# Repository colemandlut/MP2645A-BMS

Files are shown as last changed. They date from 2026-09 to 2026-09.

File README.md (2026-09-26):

# MP2645A-BMS：8S LiFePO4 200A 主动均衡 BMS（MPS 方案）

| 项目 | 内容 |
|---|---|
| 电池 | 8S LFP，25.6V 标称（20~29.2V） |
| 电流 | 持续放电 200A / 充电 100A，硬件短路 800A |
| AFE | MPS **MP2797**（监测、库仑计、高边驱动、硬件保护、被动均衡） |
| 均衡 | MPS **MP2643** ×7（相邻两节一颗，双向 buck-boost，1.78A），光耦由 MCU 控制；v0.3 起替代 MP2645A |
| 功率 | 高边背靠背 NMOS，每方向 8 并联（80V/1.2mΩ TOLL） |

## 目录

- `docs/01-系统设计说明.md` —— 完整方案：架构、选型、功率/采样/均衡电路、保护参数、布局、验证计划
- `docs/02-BOM.csv` —— BOM（数量、立创编号、来源）
- `docs/05-成本估算.md` —— 元器件成本（`python3 tools/cost.py`，嘉立创实时价）
- `tools/bms_calc.py` —— 设计计算器（MOSFET 损耗温升、分流器、均衡时间、MP2643 手册公式）
- `tools/jlc_api.py` —— 嘉立创料号查询（库存、基础/扩展库、阶梯价）
- `firmware/` —— 与硬件无关的保护状态机 + LFP 均衡策略（C11），附主机端单元测试
- `obsidian-vault/` —— 项目知识库（Obsidian 仓库，可直接用 Obsidian 打开）

## EDA

全部使用 **KiCad 10**。云端容器安装：`sudo bash tools/setup_kicad.sh`（之后可用 `kicad-cli`、`kicad-python`）。

## 运行

```bash
python3 tools/bms_calc.py                 # 打印设计计算
python3 -m unittest discover -s tests     # 计算器测试
make -C firmware test                     # 固件逻辑测试
```

> 标注【待核】的参数来自 MPS 产品简介，画原理图前需对照正式数据手册确认。

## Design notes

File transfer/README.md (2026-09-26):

# transfer/

- `pcb-workflow-skill.tar.gz`：上个会话在云主机上改写的 pcb-workflow 技能（KiCad 版、规则 0e、models.toml）。
  **只用于会话间转移**：新会话按 `docs/00-会话交接.md` 第 3 节解压回云主机技能目录，不作为仓库技能使用。

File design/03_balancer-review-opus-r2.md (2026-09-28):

# 03_balancer 第 2 轮独立复核（Opus，复核方）

> 时间戳：2026-09-28 12:15 JST（`TZ=Asia/Tokyo date` 实查）
> 快照：`review/03-r2/`。`03_balancer.kicad_sch` 的 md5 为 `8e57b0ec…1a`，与 `hardware/03_balancer.kicad_sch` 相同。
> 纪律：本轮只读，没有改工程文件，没有运行 git，也没有读画图方报告。
> 分级口径同第 1 轮：P0 = 接错或会损坏器件；P1 = 前提不成立或可靠性风险；P2 = 改进、文档或样板实测项。

## 结论速览

- **P0 0 条，P1 0 条，P2 3 条**（新增 2 条，另有 1 条是第 1 轮的 P2 沿用汇总）。
- 第 1 轮的两条 P1 **均已关闭**。
- **按口径，03 页判定完成。**

---

## 1. 网表与 ERC（独立复核，不依赖主代理的结论）

- **连接关系**：用 r1 和 r2 两份 `netlist.xml` 按「器件.引脚 → 网络」全量比对本页 113 个器件，**连接差异为 0**。
  - r1 的 274 个编号引脚已经在第 1 轮逐一对照规格书 §3.2 核过（0 处不符），所以 r2 的连接同样正确。
- **器件变化**：只有 23 件的值、LCSC 或符号有变化，没有位号增减。
  - D301–D308、D311–D318：1N5819WS → **BAT54WS**，符号 `jlc:BAT54WSL9`，LCSC C22629，封装仍是 `jlc:SOD-323_L1.8-W1.3-LS2.5-RD`。
  - R302–R308：100k → **330k 1%**，符号 `0402WGF3303TCE`，LCSC C25778，封装 `jlc:R0402`。
  - R301 保持 100k（C25741）。
- **BOM**：`docs/02-BOM.csv` 与上面一致：第 56 行 R301（C25741），第 57 行 R302–R308（C25778，7 只），第 59 行 D（C22629，16 只）。
- **ERC**：快照 `erc.json` 中 `/开关电容主动均衡/` 为 **0 条**。根页 6 条 `isolated_pin_label` 属于 01/02 页的契约标签，与第 1 轮相同。
- **网络类**：X1–X8、VB0–VB8、BAL0–8 都属 BAL_3A，BAL_CLK 为 Default ✅。
- **页面文字**：已全部改成 BAT54WS 和 R302–R308 330k。原理图文件里搜不到「1N5819」✅。

## 2. 变更 ①：BAT54WS 的 K/A 方向与「慢开快关」

- **符号**：嵌入符号 `jlc:BAT54WSL9` 与 `jlc.kicad_sym` 一致，引脚为 **1 = K，2 = A**。Footprint 与 `LCSC Part = C22629` 两个字段也一致。
- **封装**：共用的 SOD-323 封装没有变。焊盘 1 在 (−1.17, 0)，阴极丝印条在 x = −0.45，靠焊盘 1 一侧，所以**焊盘 1 = K** ✅。
  - 手册（`datasheets/C22629.pdf`，与 `C22629_CJ_BAT54WS.pdf` 的 md5 相同）p.1 的外形图上，色环一端标「−」，即阴极 ✅。
- **逐只核对**（netlist 里 k = 1..8 全部满足）：
  - **D30k**：1(K) = DRVk，2(A) = GNk。DRV 变低时，N 管栅极经二极管快速放电，**快关**；DRV 变高时二极管反偏，栅极只经 R31k 330Ω 充电，**慢开** ✅。
  - **D31k**：1(K) = GPk，2(A) = DRVk。DRV 变高时，P 管栅极经二极管快速充电，**快关**；DRV 变低时二极管反偏，栅极只经 R32k 330Ω 放电，**慢开** ✅。
- **结电容（第 1 轮 P1-1）**：
  - 手册 p.1 规定 **CT ≤ 10pF @ VR = 1V, 1MHz**（最大值）；p.2 的 CT–VR 曲线在 0V 时也只有十几 pF。
  - 开通管的栅极被耦合上去的量 = V_cell × Cj / (Cj + Cg)。按 Cj = 10–15pF、Cg 取 AO3416 的 Ciss 660pF（QN p.2）或 AO3415A 的 750pF（QP p.3）计算，最大约 **3.65 × 15 / 675 ≈ 0.08V**，远低于 Vth,min（N 管 0.45V，P 管 0.5V）✅。**P1-1 关闭**。
- **其它额定值**（均 ✅）：
  - **正向电压**：VF 最大 0.24V @ 0.1mA、0.32V @ 1mA（p.1）。关断尾段，栅压被拉到离源极不超过约 0.3V，低于 Vth,min。
  - **峰值电流**：关断方向约 (3.65 − 0.8) / 16Ω ≈ 0.18A，持续小于 100ns，低于 IFRM 300mA 与 IFSM 600mA。平均电流约为每边沿 5nC × 75kHz ≈ 0.4mA，低于 IF 200mA。
  - **反向电压**：VR 21V，实际不超过 3.65V。
  - **反向漏电**：IR ≤ 2µA @ 25V，与 330Ω 并联，可以忽略。
  - **结温**：Tj 最高 125°C，功耗是 µW 级。

## 3. 变更 ②：R302–R308 = 330k 时的翻转顺序（第 1 轮 P1-2）

### 3.1 计算条件

- **时间常数**：
  - 第 1 级 τ1 = 100k(±1%) × 1nF(±10%) = **89–111µs**；
  - 第 k 级（k ≥ 2）τk = 330k × 1nF = **294–359µs**。
- **阈值**：VT− 在 VCC = 3.0V 时为 0.89–1.20V（LVC p.6）；3.3V 时插值上限约 1.35V，3.65V 时插值上限约 1.53V。
- **漏电**：输入漏电 IIN ≤ ±1µA（LVC p.7，全温度范围）。在 330k 上最多造成 ±0.33V 的偏移，在 100k 上为 ±0.1V。
- **前提**：固件只在所有节 ≥ 3.0V、相邻压差 ≤ 300mV 时才输出 BAL_CLK，所以时钟卡高时同样满足这一条件。
- **翻转时间**：t = τ · ln[(V_hi − V∞) / (VT− − V∞)]，其中 V∞ 为漏电造成的终值偏移。

### 3.2 结果

| 情况 | 取值 | 翻转时间 |
|---|---|---|
| 第 1 级最晚 | V_hi = 3.37 − 0.3 = 3.07V（3V3 取 +2%），VT− = 0.89V，V∞ = +0.1V，τ = 111µs | ln(2.97 / 0.79) = 1.32，约 **147µs** |
| 第 k 级最早 | V_hi = 3.0 − 0.3 = 2.7V（发送节 3.0V），接收节 3.3V 时 VT− = 1.35V，V∞ = −0.33V，τ = 294µs | ln(3.03 / 1.68) = 0.59，约 **173µs** |
| 第 k 级最早（另一角点） | 发送节 3.35V、接收节 3.65V：V_hi = 3.05V，VT− = 1.53V | 同样约 173µs |

- **第 1 级一定最先翻低**，最坏角点叠加最坏漏电时仍有 26µs 余量；不计漏电时余量为 137µs 对 203µs。
- 第 1 级翻低时，第 2 级输入还在不低于 (2.7 + 0.33) × e^(−147/294) − 0.33 ≈ 1.5V，高于 VT−。
- DRV1 的下降沿（≥ 3.0V）把 IN2 推到约 −1.5V，被钳位在 −0.3V，第 2 级立即翻低，然后逐级在 ns 级内**同步带低**第 3–8 级。混相窗口从最长约 50µs 缩短到逐级传播延迟的量级（< 0.5µs），与每个正常时钟边沿相同。

### 3.3 各种情况

- **停时钟**（停在低电平）：最后一个下降沿逐级传播，全部为低 ✅。
- **MCU 复位**（PA8 变为高阻，R52 下拉）：C321 两端节点只有 pF 级对地电容，IN1 瞬间跳到约 −0.15V，是同步的下降沿 ✅。
- **时钟卡在高电平**：按上面的计算，第 1 级先翻，然后同步带低 ✅。
- **MCU 慢掉电**：
  - PA8 随 VDD 缓慢下降，经 C321 高通后在 IN1 上表现为**额外的向下偏移**（斜率 × τ1），第 1 级只会翻得更早；
  - 第 2–8 级不受 BAL_CLK 影响；
  - 掉电复位时的阶跃同样向下 ✅。
- **上电**：各节输入经下拉为 0，全部为低 ✅。
- **正常工作的副作用**：
  - 第 2–8 级的下垂由 6.5% 降到 2.2%，高电平约 2.64V，比 VT+,max 2.08V（3.3V 时）高，余量更大。
  - 空闲时漏电偏移不超过 0.33V，低于 VT−,min 0.89V，仍被可靠地压在低电平。
  - 时钟下限仍由第 1 级（τ1 = 100µs）决定，约 20kHz，不变 ✅。
- **结论**：停时钟、MCU 复位、时钟卡高、慢掉电四种情况都收敛到全低，**持续性混相已消除**，飞电容稳态只承受一节电压（≤ 3.65V）。**P1-2 关闭**。
  - 前提：固件的 300mV 压差门限必须有效。如果接收节 3.65V 而发送节只有 3.0V（压差 650mV），再叠加 −1µA 的漏电，第 k 级最早会提前到约 143µs，与 147µs 相当。这个角点已被固件的 `BAL_MAX_DIFF_MV` 排除，见 P2-2。

## 4. 变更 ③：可读性（PDF 第 4 页目视）

- C30k 的位号已经移到电容右侧，不再与 `VBk` 标签重叠 ✅。
- Q311–Q318 的「AO3415A」「Q31k」文字已经正向显示 ✅。
- 标题栏为 Rev `v0.3-draw-r2`、Date 2026-09-28 ✅。
- 残留：C301–C308 的值文字「100nF 16V」与电容的竖向连线轻微相交（每节都有），见 P2-1。

---

## P0

无。

## P1

无。第 1 轮的 P1-1（二极管结电容）和 P1-2（时钟卡高混相）均已关闭，分别见 §2 和 §3。

## P2

1. **P2-1（新增，可读性）**：C301–C308 的值「100nF 16V」与电容的竖向连线轻微相交。建议把值文字右移，或放到位号下方。属规则 00 ③，不影响网表。
2. **P2-2（新增，文档与固件）**：§3 的翻转顺序依赖两个固件前提：「≥ 3.0V 才开均衡」「压差 ≤ 300mV」。
   - 建议在 docs/03 §4.3 和规格书里注明：「R302–R308 = 330k 的时序余量依赖 `BAL_MAX_DIFF_MV` 与 `BAL_MIN_CELL_MV`」。
   - 固件 X-5（停时钟停在低电平、IWDG）仍然未实现，同第 1 轮 P2-6。
3. **P2-3（沿用）**：第 1 轮的 P2-1 到 P2-8 全部沿用，状态不变：
   - UMW 手册 p.2 引脚表与 p.1 图矛盾，原理图正确；
   - IN1 正向地电位瞬变没有钳位；
   - 跨级传播延迟造成的重叠待样板实测；
   - C191023 的手册没有进 `datasheets/`（现在已不再使用，可以忽略）；
   - 0.16A 口径的适用范围；
   - 74LVC 瞬态电流、BAL_3A 线宽、J6 定位柱。
   - 另外，第 1 轮 P2-4 中的「P 管文字倒置」和「标题栏」两项已经修掉，只剩本轮的 P2-1。
   - 补充：死区的绝对值取决于阈值以下的栅极电容，手册里 Ciss 660pF 与 Fig 11 初段约 1.3nF 两个数不一致，所以样板仍要按规格书 §8.3 第 2、3 条实测。若测得重叠，可以按规格书的预案把 330Ω 改为 470Ω（C25117），不影响封装。

## 覆盖清单

| 项 | 结果 |
|---|---|
| 连接与 r1 全量比对 | ✅ 0 差异（程序比对） |
| 23 件的值、LCSC、符号、封装 | ✅ 与 BOM 第 56、57、59 行一致 |
| 嵌入符号对库 | ✅ BAT54WSL9 为 1 = K、2 = A；0402WGF3303TCE 一致 |
| D 的封装极性 | ✅ 焊盘 1 靠阴极丝印条，手册色环为阴极 |
| 16 只 D 的方向与慢开快关 | ✅（§2） |
| 结电容 | ✅ ≤ 10pF，栅极耦合量 ≤ 0.08V |
| 停时钟、复位、卡高、慢掉电、上电 | ✅（§3，含容差、阈值和漏电的最坏角点） |
| 飞电容最大电压 | ✅ 稳态只承受一节，持续性混相已消除 |
| ERC、网络类 | ✅ 本页 0 条；X、VB、BAL 属 BAL_3A |
| 可读性 | ✅ 三项已改；残留见 P2-1 |
| 第 1 轮 P2 | 沿用（P2-3） |

### 交主代理 / 知识库（复核方没有写入）

- 「交流耦合链的同步回零：让第 1 级的 τ（100k）明显小于其余各级（330k），留出余量要算上 VT− 离散、±10% 电容容差和 ±1µA 漏电的最坏角点，并依赖固件的压差门限」。

---

## qwen P1-A 裁决（2026-09-28 12:50 JST，Opus 独立复核，只读）

**裁决：不构成 P1，降为 P2（样板实测项），维持现有电路，不建议串电阻。** 同时，qwen 的 P2-9「TI SN74LVC1G17 是反相器」**不成立**。

### 1. 快关路径的实际电流（按拓扑逐段核）

**上升沿（关 P 管）**：U30k.4 → D31k（A→K）→ GPk → Q31k 栅极。

- 回路电阻 = 输出内阻 ro + 二极管动态电阻（约 5Ω）。
  - ro 取 16–29Ω：由 LVC p.6–7 推算，VCC 3.0V 时 VOH 2.3V @ −24mA、VOL 0.55V @ 24mA。
- 驱动电压 = V_cell − Vf。BAT54WS 在 0.1A 时 Vf ≈ 0.7–0.8V（C22629 p.1：VF5 ≤ 1.0V @ 100mA）。
- 负载是 P 管栅极，约 0.75nF（Ciss，QP p.3）到约 1.8nF（按 Qg/V 计入米勒）。

**下降沿（关 N 管）**：经 D30k（A = GN → K = DRV）灌电流。对称计算，N 管栅极约 0.66–1.35nF，所以电流更小。

慢开支路（330Ω）在边沿时只额外叠加约 V_cell / 330Ω ≈ 10mA。

| ro | V_cell 3.0V | V_cell 3.65V |
|---|---|---|
| 16Ω | 110mA | 136mA |
| 24Ω | 79mA | 98mA |
| 29Ω | 68mA | 84mA |

- **峰值约 70–140mA**。qwen 的 85mA 在这个范围内，数量级正确。
- **持续时间**：τ = (ro + rd) × Cg ≈ 21–34Ω × 0.75–1.8nF ≈ 16–60ns。电流高于 50mA 的时间 ≈ τ·ln(Ipk / 50mA)，约 **15–60ns**。
- **每个边沿的电荷**：约 V_cell × Cg ≈ 3–6nC。
- **平均电流**：2 × 3.3V × 1.8nF × 75kHz ≈ **0.9mA**。
- **RMS 电流**：约 110mA × √(150k/s × 35ns / 2) ≈ **5.6mA**。
- **输出级耗散**：≈ ½CV² × 2f ≈ **1.5mW**，SOT-23-5 的温升 < 1°C（θJA 300°C/W，LVC p.4）。

### 2. ±50mA 是直流还是含瞬态

- UMW 手册 p.4 原文是「**DC** Output Sink Current IO ±50mA」，同表还有「**DC** Output Diode Current IOK ±50mA」和「**DC** Supply Current per Supply Pin ICC ±100mA」。三者都是**直流 / 连续**额定，手册没有给容性负载的瞬态峰值。
  - TI 原版的对应条目是「Continuous output current」，语义相同。
- 手册自己的 AC 测试条件就会产生超过 50mA 的瞬态：tpd 在 **CL = 50pF** 下测（p.8），74LVC 边沿约 1–2ns，i = C·dV/dt ≈ 50pF × 3.3V / 1.5ns ≈ **110mA**。可见数十到上百 mA、ns 级的容性充放电峰值，是这类输出的**正常工作状态**，并不违反直流 abs max。
- 与可靠性相关的量是平均电流和 RMS 电流（电迁移）以及结温。本设计分别约 0.9mA 和 5.6mA，温升 < 1°C，**都远低于 ±50mA 和 ±100mA**。
- 另外，qwen 引用的「24mA@3.0V」是 VOH/VOL 的**直流规格测试点**，不是电流上限。

**结论**：「长期超 abs max」的判断把直流额定套用到了 ns 级的容性瞬态上，前提不成立。**不构成 P1**。这条已被本报告第 1 轮 P2-8 覆盖（样板时看 DRVk 波形与 U30k 温升），维持 **P2**。

### 3. 「DRVk 串 10–33Ω」的后果（不建议）

- **串 10Ω**：峰值只降到约 55–100mA，仍高于 50mA，达不到目的。
- **要把峰值压到 50mA 以下**，需要串约 **47Ω**：(3.65 − 0.5) / (16 + 47 + 5) ≈ 46mA。这样快关的 τ 从约 16–60ns 增大到约 50–120ns，P 管关断时间（约 2.7τ）从约 110–165ns 增加到约 **135–330ns**。
- 慢开一侧只由 330Ω 加 47Ω 决定，基本不变：N 管在约 40–80ns 就越过 Vth,min。
- 净效果是**死区被吃掉，重新出现两管同时导通**，正好抵消 U-1 的目的，比现状更差。
- 如果将来实测证明确实要限流，必须**同步放大慢开电阻**，保持「慢开时间常数远大于快关时间常数」，例如串 47Ω 并把 R31k/R32k 由 330Ω 改为约 1k。代价是完全导通更慢（约 5µs，占半周期 6.67µs 的大部分），R_FSL 会明显变差，需要重新核算均衡电流。**不推荐**，只作为样板实测不理想时的备选。

### 4. qwen P2-9「TI SN74LVC1G17 是反相器」

- **不成立。** UMW 手册 p.1 Description 写的是「Single **Non-inverting** Schmitt Trigger Buffer」，p.1 Figure 1 的符号是不带反相圈的缓冲器，p.3 功能表为 A = L → Y = L、A = H → Y = H。
- TI 的命名规则也是 SN74LVC1G17 = 单路施密特**缓冲器**（非反相），SN74LVC1G14 才是施密特**反相器**。
- 本设计的「8 级同相、相位 1 全高、相位 2 全低」正是依赖非反相（规格书 §1.2 引 LVC p.3 函数表），原理图与 BOM 用的都是 1G17（C7394021），**正确**。

### 本节对总计数的影响

不变：**P0 0 / P1 0 / P2 3**。qwen P1-A 并入第 1 轮 P2-8（沿用，样板看 DRVk 波形与 U30k 温升）；qwen P2-9 驳回。**03 页判定完成的结论不变。**

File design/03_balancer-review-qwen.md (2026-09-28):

# 子图 03_balancer 独立复核（review2 / qwen3.8-27b）

- 快照：`review/03-r1/`（03_balancer.kicad_sch md5 `9caa8c53fcb304c45472574c5d2f5c59`）——**本报告的复核对象**
- 工作树说明：截至本复核（2026-09-28 12:3x JST）工作树已按规格书 §8.1c 用户决定进入 r2 状态（md5 `8e57b0ecc86f58e3d9b49bf7c53b8c1a`，冻结于 `review/03-r2/`）→ 骨架第 3 行「与工作树逐字节一致」已失效；本报告对 r1 快照下结论，并对 r2 换料做独立验收（§8）
- 复核方：阿里云 qwen3.8-27b；画图方 DeepSeek、第一复核 Opus，三方不同厂商
- 独立性声明：未读画图方报告（`03_balancer-draw-report.md`、`*-draw-*.out`）、未读第一复核报告、未读生成/自检脚本注释；全部结论从快照 + 规格书 + docs + BOM + 手册 + 05 页源独立重推
- 输入：`review/03-r1/`（sch / erc.json / netlist.xml / sch.pdf 第 4 页）、`design/03_balancer-spec.md`（含 §8.1b/§8.1c 用户决定）、`design/03_balancer-task-draw-r2.md`（任务书，允许输入）、`docs/03-详细设计.md` §1/2.4/4、`docs/02-BOM.csv` 均衡段、`datasheets/`（C479060、C5350990、C7394021、C191023、C22629、C15008、C163126、C18202166）、`hardware/05_mcu_comm.kicad_sch`（BAL_CLK 源）、`hardware/mp2645a-bms.kicad_pro`（网络类）、`hardware/lib/jlc/jlc.kicad_sym`、`tools/bms_calc.py`（sc_equalizer）、`tools/jlc_api.py`（抽核）

## 结论汇总

**P0 = 0；P1 = 3（P1-B、P1-C 为 r1 缺陷，r2 已修复且本复核独立核实修复成立；P1-A 仍未覆盖、保持开放）；P2 = 10（含 2 条纯备注）。**

| # | 级别 | 位号 | 摘要 | 状态 |
|---|---|---|---|---|
| P1-A | P1 | U301–U308（脚 4/DRVk） | 栅驱峰流 ≈(Vcell−Vf)/ro ≈ 80–110mA（ro≈24Ω 为 TI 同族估计，UMW 手册未列 ro），每边沿 ~13–18ns × 75kHz×2 边沿 ×8 级，超 UMW 手册 p4 绝对最大 **IO ±50mA**；功能不受影响（二极管钳位端点电压与 ro 无关）但长期 24/7 超出绝对最大额定 = 可靠性风险 → 样机实测/UMW 书面确认；备选：DRVk 串 10–33Ω | **开放**（r2 未覆盖） |
| P1-B | P1 | D301–308/D311–318（r1 = 1N5819WS C191023） | Cj 110pF@4V 与栅电容电容分压：DRV 边沿馈通 ΔV·Cj/(Cj+Ciss) ≈ +0.47V（N 栅）/ −0.42V（P 栅）→ 边沿提前 ~10–30ns。独立重推（缓冲器模型，见 §3.2）：P 栅馈通后 Vgs_P ≈ −1.4V，仍比 \|Vth\|max 0.9V 低 ≥0.5V → **不构成持续直通**；后果比初报定级轻（边沿毛刺，非死区失效）。r2 换 BAT54WS（CT≤10pF）将馈通降一个量级 → 有效改进 | r1 缺陷；**r2 已修，独立核实**（§8） |
| P1-C | P1 | R301–R308（r1 全 100k） | 停时钟/掉电时各级 IN 独立 RC 衰减，翻转时刻 t_k≈100µs·ln(Vcell_k/VT−_k)：ΔV≲100mV 的剖面下相邻级**可能逆序翻转**（靠 VT− 器件离散与电压差同量级竞争），窗口典型 ~1–3µs、最坏角 ~30µs；窗口内 (k=N 通, k+1=P 通) → CF(k−1) 跨两节 6.6–7.3V，板内 τ_CF≈(Rds_N+Rds_P+ESR)×200µF≈18–30µs → 最坏角 CF 峰值 ~6.0–6.5V（**边际超 6.3V 额定**，每掉电一次）；典型角 ~0.4–1.1V 不超。规格书 §4.3 只写「约 30µs 混相」未量化超压。注：本复核按 C33k∥C34k=200µF 口径，比早期「τ=9µs、超压 0.1–1.0V」的估计更保守（超压幅度更小、但最坏角仍触额定）。r2：R301 保持 100k、R302–308→330k，首级翻转 t1≈100µs·ln(V1/VT−1)≈101–131µs（规格「≤133µs」✓）恒早于其余级（≥330µs·ln(V/VT−)≈415–455µs）→ DRV1 下降沿经 C322 把 IN2 拉低 ~0.9975·Vcell（t1 时刻 IN2 自由衰减值仅 ~0.72–0.74·Vcell）→ 钳位至 VB1 输入二极管 → 级联 ~5ns/级带低 2–8 级 → 逆序窗口消除，残留 = MOS 转换 ~0.3µs → CF 过压 ≈7.3V×(0.3/18)µs ≈ **24mV** | r1 缺陷；**r2 已修，机制独立重推成立**（§8） |
| P2-1 | P2 | D30k/R31k/D31k/R32k（全部 8 级） | DRV 下降沿：N 快关（D30k 放栅，~40ns 过 Vth）与 P 慢开（R32k，~70ns 至「基本导通」、~400ns 全导通）重叠 ~30–350ns；Thevenin 峰值 Vcell/(Rds_N+Rds_P) ~10–20A，被电芯 ESR（~10–30mΩ）+线束 0.7µH 限制到实际数 A；每边沿能量 ~0.3–1µJ ×75k/s → **~10–80mW/级**（θJA 89°C/W → 每级几 °C–10°C）；AO3416 绝对最大 6A 在边界 → SPICE/样机实测灌流峰 | 待样机 |
| P2-2 | P2 | D30k + Q30k（GNk） | N 快关地板 GN=VOL+Vf：r1 1N5819WS ≈0.75–0.9V（r2 BAT54WS ≈0.54–0.8V）vs N Vth 0.45–1.0V：最坏角（Vth max）关断裕量 0.1–0.25V ✓，典型角（Vth 0.7）仅 ~50mV → 亚阈 µA 级漏 | 备注（典型角贴边） |
| P2-3 | P2 | D31k + Q31k（GPk） | DRV 高电平期间 P 栅端点 GP=DRV_high−Vf → Vgs_P≈−(0.7+Vf)≈−0.94…−1.15V vs \|Vth\| max 0.9V：r2 BAT54WS 低 Vf 角（0.24V）Vgs_P≈−0.94V → 部分 P（\|Vth\|≤0.94）在 N 导通半周处于导通边界（亚阈 µA–mA，非破坏）→ 仿真确认 | 待仿真 |
| P2-4 | P2 | C301（r1 PDF 第 4 页） | 可读性：C301 位号/字段压「VB1」全局标签；Q311–318 字段角度倒置（fa≠0）。r2 已修（r2 渲染确认分离/正立） | r1 缺陷；r2 已修 ✓ |
| P2-5 | P2 | 固件（X-5 TODO，尚无代码） | 规格书门控（ΔV>300mV 禁均衡 / <3.0V 禁 / 顶部区策略 / 静置 30min）尚未落地。无门控时：级 k 的 IN 高电平 = 前级 DRV 耦合 ≈Vcell(k−1)·0.9975，须 > VT+(VCC=Vcell_k) 才能翻转：最恶劣相邻剖面（下 2.5V/上 3.65V）高电平裕量 = 2.5·0.9975 − VT+(3.65≈2.4) ≈ 0.1V → 该级停摆（CF=0↔1 节，**非破坏**，均衡能力降级）→ 核固件落地 | 待固件 |
| P2-6 | P2（备注） | D30x/D31x 符号 | BAT54WSL9 为单二极管符号：已核实为单 die（CJST 手册 p1），JLC API 文案「Independent…Diodes」系分类套话；K=pin1（fp_poly 封装色环在 pin1 侧）✓ | 已核实，备注 |
| P2-7 | P2（文档更正） | — | 「栅负载约 3.2nF」（知识库 + 详细设计 §4.3）= Qg/V 假象（(8+9.5)nC/3.2V≈3.3nF），实际 Ciss 合计 660+750=**1.41nF**（另加二极管 Cj）→ 已写回知识库更正（死区决策本身不受影响，仍成立） | 已更正 |
| P2-8 | P2（未核） | F300–F308（CFS12V3T3R0 C163126） | 手册已读页无 I²t 表 → 规格书「40–73A 约 1ms 熔断」为工程估计 → **未核**；额定 3.00A/DC32V/分断 50A@32V/−20…+105°C 已核 | 未核 |
| P2-9 | P2（重要备注） | U301–U308（C7394021） | **器件身份**：UMW/UTD「SN74LVC1G17DBVR」是**非反相施密特缓冲器**（手册 p1 标题 "Non-inverting Schmitt Trigger Buffer"、p3 功能表 INA L→OUTY L / H→H、p1 引脚图），借用 TI 反相器 1G17 料号；TI 原装 1G17 为反相器且引脚不同（TI：1=GND/2=CEXT/3=A/4=Y/5=VCC，UMW：1=NC/2=INA/3=GND/4=OUTY/5=VCC）。本设计拓扑**依赖缓冲功能**（各级同相；若为反相器则各级交替 N/P，CF1/3/5/7 常态跨两节 6.6–7.3V）→ BOM/规格书/符号应加注「**勿代换为 TI 原装 1G17 反相器**」。所购 C7394021 = 缓冲器 = 设计正确 | 已核实，需加注 |
| P2-10 | P2（备注） | U30x / J6 | 规格源不一致：UMW 手册 p1 Features「Source/Sink 24mA@3.0V」vs JLC API/BOM「32mA」（P1-A 以 abs max ±50mA 为准，不受影响）；J6 连欣手册 6A/针 vs JLC API/BOM 5A/针（均被 F30k 3A 覆盖） | 备注 |

次要（不计 P2）：详细设计 §4.3 栅驱损耗 2.6mW/节 vs 按 Qg·f 推算 ~4.3mW（估算偏差，不影响结论）；2.5V 电芯角 Vgs_N≈2.25V 略低于 2.5V 测试条件，Rds(on) 略劣于 26mΩ 标称（~35–40mΩ 量级），I²R≈1mW 无碍。

## 0 前置检查（断线/死头/悬空、同网多名、GND/CELL）

- **断线/死头/悬空**：ERC（快照冻结 `erc.json`，Kicad 10.0.6，2026-09-28T02:32）sheet `/开关电容主动均衡/` violations = **0**；全工程 6 条 warning 均为根图页 `/` 的 `isolated_pin_label`（DSG_G/CHG_G/SRP/SRN/FET_MID/PACK+），与本页无关。网表逐脚复核：无一脚挂两网；未连接脚仅 **U30x.1**（NC，UMW 手册 p1 引脚图确认 NC）与 **J6.10**（有意空放 NC，规格书 §7 接口定义），均有文档依据，无意外悬空。
- **同网多名**：网表每网唯一名；本页 60 网无两名共指同一物理连接（逐脚比对无「两个不同全局标签落在同一对引脚」）→ 0 条。
- **本页无 GND / 无 CELL\***：网表确认本页 60 网全部为 `/开关电容主动均衡/…`（50 个：IN1–8、DRV1–8、GN1–8、GP1–8、X1–8、VB0–8、CLK_R）+ 全局 BAL0–8（9）+ BAL_CLK（1）；无 GND/0/CELL*。工程网表中的 GND、CELL0–8、NTC_CELL1/2 均在 01/02/05 页。符合规格书 §8.1b 用户决定（VB0 不接地、首级交流耦合、本页无 GND/电源符号）。
- **U30x 浮动供电合法性**：U30k VCC=VBk、VSS=VB(k−1)，供电 = 一节 2.5–3.65V ∈ UMW 手册 p5 推荐工作条件 1.65–5.5V ✓；C30k 100nF/16V（C1525）跨 VCC–VSS 去耦 ✓ 8/8。

## 1 逐节推导（k=1..8）

**拓扑（从 r1 网表独立重推，8 级逐字段核完，全部一致）：**

- **U30k**（C7394021 UMW 非反相施密特缓冲器，身份见 P2-9）：pin2 INA = INk（= R30k→VB(k−1) ∥ C32k）；pin3 VSS = VB(k−1)；pin5 VCC = VBk；pin4 OUTY = DRVk；pin1 = NC 悬空。
- **k=1 特例**：C321.1 = CLK_R（← R300 1k ← BAL_CLK；BAL_CLK 另两节点 = 05 页 R52.1、U6.29，即 MCU 侧 + 100k 下拉，规格书 §8.1b「IN 只接 100k 下拉」在 05 页实现）；**k≥2**：C32k.1 = DRV(k−1)。C32k.2 = INk。
- **Q30k N（AO3416 C479060）**：G=GNk、S=VB(k−1)、D=Xk；**Q31k P（AO3415A C5350990）**：G=GPk、S=VBk、D=Xk（N、P 漏极共 Xk，Xk 节点 = {C33k.1, C34k.1, Q30k.3, Q31k.3} ✓）。
- **死区网络（引脚级核完 8/8）**：D30k（r1：1N5819WS C191023）**pin1(K)=DRVk、pin2(A)=GNk**，∥ R31k 330Ω（DRVk↔GNk）→ **N 慢开**（R31k 充栅 τ≈330×(660+Cj)pF）、**N 快关**（D30k 放栅 GN=VOL+Vf）；D31k **pin1(K)=GPk、pin2(A)=DRVk**，∥ R32k 330Ω（GPk↔DRVk）→ **P 慢开**（R32k）、**P 快关**（D31k 钳 GP=DRV−Vf 跟上升沿）。二极管方向与页面注记「慢开快关」一致 ✓。
- **飞电容**：CFk = C33k∥C34k = 2×100µF/6.3V（C15008，1206），Xk↔X(k+1)，7 级 7/7 ✓。
- **储能/去耦**：C31k 100µF/6.3V（C15008）VB(k−1)↔VBk（本地储能，规格书 §8.1b：线束 0.7µH 与 100nF 谐振 ±1V → 必须 100µF）8/8 ✓；C30k 100nF/16V（C1525，0402）VB(k−1)↔VBk（栅驱去耦）8/8 ✓。
- **R30k**：INk↔VB(k−1)，r1 全 100k（C25741），R301.2=VB0 … R308.2=VB7 ✓。

**功能推导（缓冲器模型）：** INk 高 → DRVk 高 → N 通、P 关 → Xk=VB(k−1)；INk 低 → DRVk 低 → N 关、P 通 → Xk=VBk。CLK 高半周：1nF 耦合链使各级 IN 同相为高（tpd max 4.5ns@3.3V，UMW 手册 p7）→ **全级 N 通，CFk=Vcell_k**；CLK 低半周：全级 P 通，**CFk=Vcell_{k+1}**。电荷转移方向：Vcell_k>Vcell_{k+1} 时 CFk 在 N 相充至 Vcell_k、P 相跨在 k+1 节上放电 → 净 k→k+1 ✓（经典全同相开关电容均衡，拓扑正确）。

## 2 时钟链与停时钟/复位/上电/卡高状态、飞电容耐压

- **正常**：75kHz（半周期 3.35µs ≫ 慢开 0.22–0.28µs + tpd），全级同相（缓冲器级联，无反相）✓；均衡电流口径见 §6。
- **停时钟 / MCU 复位 / 时钟卡任意电平（DC 终态）**：R30k 把所有 INk 拉向 VB(k−1)（低），C32k 隔直 → 所有 DRVk 低 → **全 N 关**（地板 GN=VOL+Vf≈0.75–0.9V < Vth max 1.0V，最坏角关断）、**全 P 通**（Vgs≈0.3−3.3=−3.0V）→ **CFk=Vcell_{k+1} ≤ 3.65V ✓**。规格书 §8.1b「停时钟/复位都收敛到全低」的「全低」= 全 IN/DRV 信号低（即全 P 通态），与规格书口径一致。
- **收敛时间**：首级 IN1 经 R301∥(R300+R52) 衰减，τ≈100µs，翻转 t1=τ·ln(Vcell1/VT−)≈101–131µs（VT− 按 VCC=Vcell 内插）。**r1**：其余级 R30k 亦 100k → t_k 同量级 → 见 P1-C（混相）。**r2**：R302–308=330k → 其余级独立翻转 ≥415µs，全部由首级级联在 ~40ns 内带翻 → 见 §8。
- **上电**：初始充电经 F30k（3A）与导通 MOSFET，CFk 初值受相邻两节电压约束（≤单节等效）；C31k 初值分配 ≤4.4V/只（规格书 §5 上电分析，本复核核过充电通路存在、无 2 节直并路径）→ 6.3V 额定裕量 ≥1.9V ✓。
- **飞电容耐压（稳态 + 停钟态）**：CFk ≤ max(Vcell_k, Vcell_{k+1}) ≤ 3.65V（并联每只 3.65V = 额定 58%）✓。**唯一 CF>1 节的状态 = P1-C 的 r1 混相瞬态**（最坏角 ~6.0–6.5V，r2 已消）。

## 3 器件级核算（Vgs / Rds(on) / 耐压 / 死区直通）

### 3.1 各 MOSFET 的 Vgs（2.5–3.65V 驱动）

| 状态 | 栅压 | 角核算 | Rds(on) |
|---|---|---|---|
| N 通（DRV 高） | Vgs_N ≈ (Vcell−VOH)+Vf−… = GN−VB(k−1) ≈ Vcell−0.25（@3.3V 角 ≈3.05V；2.5V 角 ≈2.25V） | ≥ Vth max 1.0V 裕量 ≥1.25V ✓；2.5V 角低于 2.5V 测试条件 → Rds 略劣（~35–40mΩ 量级） | 26mΩ max @2.5V（AO3416 手册）；I²R@0.16A ≈ 0.7mW ✓ |
| N 关（DRV 低，地板） | Vgs_N = VOL+Vf ≈ 0.75–0.9V（r1）/ 0.54–0.8V（r2） | 最坏角 < Vth max 1.0V ✓（裕量 0.1–0.25V）；典型角（Vth 0.7）贴边 ~50mV → 亚阈 µA（P2-2） | 关态漏 µA 级 ✓ |
| P 通（DRV 低） | Vgs_P ≈ VOL−Vcell ≈ −3.0V（@3.3V）/ −2.2V（@2.5V，VOL max 0.55V 角） | < Vth min −0.5V 裕量 ≥1.4V ✓ | 47mΩ max @−2.5V（AO3415A 手册）；I²R ≈ 1.2mW ✓ |
| P 关（DRV 高，端点） | Vgs_P = (DRV_high−Vf)−Vcell ≈ −(0.7+Vf) ≈ −0.94…−1.15V | vs \|Vth\| max 0.9V：r1 角（Vf 0.45–0.6）裕量 0.35–0.55V ✓；r2 BAT54WS 低 Vf 角（0.24V）≈−0.94V → 贴导通边界（P2-3，µA–mA 亚阈） | — |

- 耐压：AO3416 ±20V、AO3415A −20V vs 单节 ≤3.65V + 混相瞬态 ≤7.3V（r1 P1-C 最坏角）✓ 裕量 ≥2.7V；二极管 VRM 30V（BAT54WS）/40V（1N5819WS）✓；C15008 6.3V 为唯一贴额定语件（P1-C 焦点）。
- 热：每级 8 件总损耗 = 导通 I²R（~2mW）+ 栅驱（Qg·V·f ≈ (8+9.5)nC×3.3V×75k ≈ 4.3mW，文档 2.6mW 偏低，次要）+ 重叠（P2-1，10–80mW）→ θJA 89.3/65–90°C/W → 结温升 <15°C，无热风险（P2-1 待仿真收紧）。

### 3.2 死区 / 直通（r1 1N5819WS，Cj 110pF@4V/1MHz）

- 时序（缓冲器模型 + 网表二极管方向，§1）：
  - **N 慢开**：R31k 330Ω 充 660pF(+Cj)：τ≈0.22–0.25µs，自地板 0.75V 充至 ~Vcell−0.25；**N 快关**：D30k 经 U30x 输出 ro（≈24Ω，TI 同族估计）放栅：τ≈ro×(660+110)pF≈18ns，过 Vth max（1.0V）~40ns。
  - **P 慢开**：R32k 放 750pF(+Cj)：τ≈0.28µs；**P 快关**：D31k 钳 GP=DRV−Vf 跟上升沿（~5ns 级）。
  - **重叠（DRV 下降沿）**：N ~40ns 关断、P ~70ns 起「基本导通」（~400ns 全导通）→ 重叠 ~30–350ns，Thevenin 峰值 ~10–20A，实际被电芯 ESR + 线束 0.7µH 限流 → 每边沿 ~0.3–1µJ ×75k/s → **10–80mW/级**（P2-1，样机/SPICE）。上升沿无重叠（N 慢开时 P 已快关）。
- **电容分压（P1-B 重推）**：Cj 与栅电容并联分压，DRV 边沿馈通 ΔV·Cj/(Cj+Ciss)：N 栅 +0.47V@3.3V（发生于 N 慢开启动点，此时 P 已关 → 短暂 10–30mA 提前导通，µW 级，无碍）；P 栅 −0.42V（DRV 下降沿）→ Vgs_P≈−1.4V，仍低于 \|Vth\|max 0.9V 达 0.5V → P 不提前通。**结论：r1 的 Cj 问题是「边沿提前 ~10–30ns」，非持续直通；r2 换 BAT54WS（CT≤10pF → 馈通 0.03–0.05V）有效，独立核实见 §8。**

### 3.3 U30x 输出峰流（P1-A，开放）

- 路径：DRVk 边沿 → 死区二极管（ro_d≈0.2–0.3Ω@100mA）→ 栅。上升沿：P 栅（750pF/Qg 9.5nC）经 D31k 充电：I_peak ≈ (DRV_high−GP_start−Vf)/ro_out ≈ (Vcell−0.7−0.45)/24 ≈ **85mA**（3.3V 角）；下降沿：N 栅经 D30k 放电：≈(2.75−0.75)/24 ≈ **83mA**；持续 ~13–18ns（tpd ~5ns + ro×C 16–18ns），**每个边沿**（75kHz×2）×8 级。
- 对照 UMW 手册：**绝对最大 IO = ±50mA（p4 Absolute Maximum Ratings）**；Features 保证 24mA@3.0V（p1）。峰流超 abs max ~70–110%：端点电压由二极管钳位、与 ro 无关 → **功能正确，但长期超出绝对最大额定 = 可靠性降级风险**（该器件 75kHz 永久工作，非偶发脉冲）。
- 处置建议：(a) 样机实测 U30x 输出电流峰（栅极电流探头/示波器）；(b) UMW/UTD 书面确认脉冲能力；(c) 若实测 >50mA：DRVk 串 10–33Ω（峰流降至 <50mA，重核慢开 τ 仍 ≪3.35µs ✓，D30k/D31k 钳位端点不变）。

## 4 J6 针位与保险丝

- **J6**（C18202166，连欣 XDWF-C3030WV-2X05P，Micro-Fit 3.0 兼容，2×5）：网表逐脚核完 **pad n ↔ BAL(n−1)（n=1..9），pad 10 = unconnected NC** ✓（规格书 §7「焊盘 10 空放」）。封装 `CONN-TH_XDWF-C3030WV-2-5P` 焊盘坐标（前会话已读封装文件）：之字形 2×5，pad 1,3,5,7,9 @y=−1.50、2,4,6,8,10 @y=+1.50，x=−6..+6 步进 3.0mm，pad 1 矩形为 pin-1 标记；连欣手册图面无针号 → BOM「按物理位置对针」合理 ✓。
- **电流**：连欣手册 6A/针 vs JLC API/BOM 5A/针（P2-10 备注）；均衡工况最坏针流 = 相邻两级叠加 ≤ 2×0.16 = 0.32A ≪ 3A 保险丝 ≪ 5–6A 端子 ✓。
- **F300–F308**（CFS12V3T3R0，C163126，TA-I 1206，3.00A）：网表 9/9 **脚 1 = BALk（线束侧）、脚 2 = VBk（板侧）** ✓；额定 DC32V、分断 50A@32V、−20…+105°C、100% 额定体温升 <75°C（手册已读页）；0.32A = 额定 10.7%，温升可忽略 ✓。保护对象 = 线束；**板上保险丝保护不了电芯端线束 → 线束端保险丝暂不加 = 已知风险 U-6（用户 2026-09-27 接受）**。I²t「40–73A 约 1ms」= 工程估计（手册已读页无 I²t 表）→ **未核**（P2-8）。

## 5 网络类（BAL_3A）

- 网表核完：`/开关电容主动均衡/` 的 **X1–8、VB0–8（17 个）+ 全局 BAL0–8（9 个）= 26/26 全部 class=BAL_3A** ✓（.kicad_pro BAL_3A：3A、线/迹 1.2mm）。
- IN/DRV/GN/GP/CLK_R/BAL_CLK = Default（控制信号网，脉冲均值 <1mA）✓，未被卷入 BAL_3A 也无 CELL_SENSE 误卷。
- **图纸名陷阱复核**：网表本地网名含图纸名路径 `/开关电容主动均衡/…`（非文件名 `03_balancer`）→ pattern 必须用图纸名（知识库既有教训，与 vault 记录一致）；改图纸名会静默退 3A 线宽。

## 6 均衡电流口径（bms_calc sc_equalizer）

- `tools/bms_calc.py sc_equalizer`：**0.159A@100mV** ↔ 规格书 §4.1 I=ΔV/0.628Ω → 0.16A ✓ 一致；60°C 0.14A、最坏 0.12A ✓。
- 模型假设（**未核，样机实测 X-1**）：线束/导线电阻 45mΩ 名义值、R_FSL 系数 4（MP2797 均衡路径安全系数）、C15008 直流偏置降额未建模、6·R_w 线阻模型。
- 级联叠加：bms_calc 为单级口径；8 级级联时线束针流 = 相邻两级之和（§4），0.32A 对 3A 保险丝/5–6A 端子裕量充足 ✓。

## 7 ① 电容完备性 / ② 封装下探 / ③ 可读性 / LCSC 与 BOM

**① 电容完备性**：U30k 去耦 C30k 8/8（16V 额定 vs 单节 3.65V = 4.4× 裕量 ✓）；CFk 双并联 7/7（一只失效 → 100µF 冗余，电流减半，非破坏）；C31k 本地储能 8/8（§8.1b 决定）；C32k 1nF/50V 耦合 8/8（50V ≫ 7.3V 瞬态 ✓）；栅极无旁路电容 = 直驱 + 330Ω，与规格书一致 ✓。**无缺漏。**

**② 封装下探**：AO3416/AO3415A SOT-23-3（Qg 8/9.5nC、θJA 89.3/65–90°C/W）：0.16A 下 I²R≈1.9mW/级，无热风险 ✓；BAT54WS SOD-323（r2）：IR 2µA@25V、PD 200mW、VRM 30V —— 钳位电流仅为栅边沿脉冲（均值 <1mA）✓；1N5819WS SOD-323（r1）同封装，Cj 110pF 见 P1-B；C15008 1206 100µF/6.3V：纹波损耗未核（手册已读页无 ESR 表，次要）；CFS12V3T3R0 1206：0.32A 温升可忽略 ✓；J6 3.0mm 孔阵 φ1.02 与连欣手册 3.00×3.00mm 布局一致，Micro-Fit 3.0 0.110" 线束针兼容 ✓。

**③ 可读性（sch.pdf 第 4 页，r1 渲染）**：缺陷 = C301 位号/字段压「VB1」标签 + Q311–318 字段倒置（P2-4，r2 已修，r2 渲染确认）；右栏整体上移 26.67mm 合理；F300–F308 与 VBk 不同高（两栏行距差，9 只排不齐）——画图方已自记为电气等价偏差，不影响判读（备注）；标题栏 v0.3-skeleton（r1）/ v0.3-draw-r2（r2）+ 6 行说明完整 ✓。

**LCSC 与 BOM 一致性**：r1 快照 113 件逐行比 BOM（均衡段行 49–61 + J6 行 100）：符号 Value/MPN/LCSC 全部一致 ✓（8 级同构 + 7 飞电容 + J6 + 9 保险丝 + R300 + 16 死区二极管 r1 态）。JLC API 抽核（`tools/jlc_api.py`）：C7394021、C22629、C479060、C5350990、C15008、C1525、C1523、C25741、C25778、C25104、C11702、C163126、C18202166 —— 与 BOM/手册一致（两处规格源不一致见 P2-10）；BOM 已更新至 r2 态（D→BAT54WS C22629、R302–308→330k C25778）✓。

## 8 r2 换料独立验收（任务书 §8.1c 用户决定，2026-09-28）

- **对象**：工作树 `hardware/03_balancer.kicad_sch`（md5 `8e57b0ec…`，与冻结 `review/03-r2/` 一致）。
- **独立重跑**（Kicad CLI 10.0.6，本复核执行）：
  - 网表（kicadxml）vs r1 冻结网表：175/175 网，本页子集 69/69（含 BAL_CLK 的 05 页外部引用 R52.1/U6.29）→ **名 0 差异、连接 0 差异、网络类 0 差异**；
  - 符号 diff = **恰好 23 件 Value/LCSC 变化**：16 D（1N5819WS/C191023 → BAT54WS/C22629，SOD-323 封装不变）+ 7 R（100k/C25741 → 330k/C25778），**R301 保持 100k**，总件数 113/113 ✓；
  - ERC（`--format json`）：本页 `/开关电容主动均衡/` **0 条**（全工程 6 条 warning 仍在根图页）。
- **机制独立重推（P1-C 修复有效性）**：R301=100k、R302–308=330k → 首级 t1≈100µs·ln(V1/VT−1)≈101–131µs（规格「≤133µs」✓）**恒早于**其余级独立翻转时刻（330µs·ln(V/VT−) ≈ 415–455µs，最恶劣角亦 > t1+280µs）→ 首级翻转时 DRV1 下降（缓冲器：IN 低 → DRV 低），C322 把 IN2 拉低 ~0.9975·Vcell1；t1 时刻 IN2 自由衰减值 ≈ Vcell·e^(−101µs/330µs) ≈ 0.72–0.74·Vcell < 拉低量 → IN2 被 U302 输入钳位二极管夹在 VB1 以下 → 2 级在 ~tpd(5ns) 内翻转 → 依次级联，**8 级全部在 ~t1+40ns 翻转**，逆序窗口从 r1 的典型 ~1–3µs/最坏 ~30µs 缩到 MOS 转换本身 ~0.3µs → CF 过压从最坏角 ~6.0–6.5V 降至 ≈7.3V×(0.3/18)µs ≈ **24mV**。**修复成立**（对 Vcell≥~3.15V 有效；低于 3.15V 两节 <6.3V 本就不会超压）。
- **残留**：(a) 级联钳位裕量按本复核口径 ≥~1V（IN2 拉低后低于 VSS 0.25V+，钳位二极管动作），对 VT− 离散不敏感 → 无需额外措施；(b) P1-A（U30x 峰流）r2 未覆盖，**保持开放**；(c) 建议样机示波器实测 DRV1 vs DRV8 边沿对齐（混相窗口直接证据）。

## 覆盖清单

| 必查项 | 状态 |
|---|---|
| ⓪ 断线/死头/悬空 | ✅ 0 条（ERC 本页 0 + 网表逐脚复核 + NC 脚均有文档依据） |
| ⓪b 同网多名 | ✅ 0 条 |
| 本页无 GND / 无 CELL\* 网 | ✅（60 网全核） |
| 逐节推导 k=1..8（串在哪/并在哪/电流路径） | ✅ 8/8 逐字段核完（含二极管 K/A 方向、R30k 端点 R301.2=VB0…R308.2=VB7） |
| 时钟链终态（停时钟/MCU 复位/上电/时钟卡高） | ✅ 缓冲器模型全核（U30x = UMW 非反相缓冲器，手册 p1/p3/p4 核实）；DC 终态全 P 通，CF≤1 节 |
| 飞电容最大电压 ≤6.3V | ✅ 稳态 ≤3.65V；瞬态 = P1-C（r1 最坏角 6.0–6.5V；r2 后 ≈24mV） |
| 每 MOS Vgs @2.5–3.65V 驱动 | ✅ §3.1 表（含 2.5V 角 Rds 降额、P2-2/P2-3 贴边角） |
| Rds(on) / 热 | ✅ 1.9mW/级 + 栅驱 4.3mW/级 + P2-1 重叠 10–80mW/级 → 结温升 <15°C |
| 直通 / 死区 | ✅ P2-1（估计值，待样机）+ P1-B（r2 已修，§8）+ P1-A（开放） |
| J6 pad n↔BAL(n−1)、pad 10 空 | ✅ 网表 + 封装焊盘坐标 + 连欣手册（图面无针号 →「按物理位置对针」合理） |
| F300–F308 → BAL 节点 | ✅ 9/9（脚 1=BALk、脚 2=VBk） |
| 网络类 Xk/VBk/BALk ∈ BAL_3A | ✅ 26/26；图纸名 pattern 陷阱复核 |
| 均衡电流 0.16A@100mV 口径 | ✅ bms_calc 0.159A 一致；模型假设标未核（X-1） |
| ① 电容完备性 | ✅ 无缺漏（4 类电容 8/8、7/7、8/8、8/8） |
| ② 封装下探 | ✅（C15008 ESR 纹波损耗未核——次要） |
| ③ 可读性（PDF 第 4 页） | ✅ r1：P2-4（r2 已修 ✓） |
| LCSC 与 BOM 一致性 | ✅ 113/113 + JLC API 抽核（P2-10 两处备注） |
| U30x 器件身份/引脚序 | ✅ p1 引脚图 4=OUTY/5=VCC 与库符号一致（p2 文字层乱码为提取伪影，非引脚对调） |
| r2 换料验收 | ✅ 连接 0 差异 + 恰好 23 件变化 + ERC 0 + 机制独立重推成立（§8） |
| 保险丝 I²t「40–73A 约 1ms」 | ⬜ **未核**（手册已读页无 I²t 表，P2-8） |
| U30x 输出 ro | ⬜ **未核**（UMW 手册未列；P1-A 用 TI 同族 24Ω 估计 → 待样机） |
| SPICE/样机（重叠灌流峰、混相窗口、U30x 栅驱电流） | ⬜ 未核（需样机） |
| 固件门控（Δ>300mV 禁/<3.0V 禁/顶部区/静置 30min） | ⬜ 代码未落地（P2-5，X-5 TODO） |
| C15008 ESR/纹波损耗 | ⬜ 未核（次要） |

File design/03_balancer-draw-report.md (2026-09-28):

# 03_balancer 画图报告（第 1 轮 · 分段 A + B）

> **本文件由「分段 B」创建**：任务书 r1a 要求分段 A 产出本报告，但 A 段结束时磁盘上没有这个文件
> （只有 03 页文件与两个脚本），故由 B 段补写。§1–§5 是对分段 A 成果的**追述**，数据不是凭记忆写的，
> 而是从 `hardware/03_balancer.kicad_sch`、`hardware/gen/gen_03_balancer.py`、`check_03_layout.py`
> 的实际输出与仓库 diff 里取的；凡是 B 段实测的数字都标了出处。§6 是分段 B 的正文。
>
> 时间戳：2026-09-28（分段 A 约 02:00 JST 前，分段 B 11:00–11:30 JST）
> 画图方：Claude（DeepSeek 画图泳道）　设计依据：`design/03_balancer-spec.md`（含 §8.1b 用户决定）
> 本段写入的文件**只有 4 个**：`hardware/03_balancer.kicad_sch`、`hardware/gen/gen_03_balancer.py`、
> `hardware/gen/check_03_layout.py`、本报告。库 / BOM / docs / 根图 / 其它子图都没动，
> 没跑 `tools/gen_kicad_skeleton.py`，没碰 git。

---

## 0. 一句话结论

第 1–8 节全部半桥、7 级飞电容、J6 线束端子与 F300–F308 熔丝**已画完**：
`check_03_layout.py` 检查 1–9 与墨迹版面 10/11/12/13 **全 PASS**（逐脚核对 **274/274**、113 件的
Footprint/LCSC 全非空），生成器**幂等**（连跑两次逐字节相同），`kicad-cli sch erc` 里
**本页（`/开关电容主动均衡/`）0 条**；全工程只剩 6 条 `isolated_pin_label`，**全部在 01/02 页**
（`DSG_G`/`CHG_G`/`SRP`/`SRN`/`FET_MID`/`PACK+`），不是本页的东西，也没动它们。

---

## 1. 分段 A 完成情况（追述）

### 1.1 画了什么

第 1–4 节（k=1..4）每节的 **11 件**，加首级时钟输入，加 k=1..3 的三个飞电容级与跨到第 4 节的第 4 级：

| 每节 11 件 | 符号（嘉立创 C 编号） | 连接（spec §3.1） |
|---|---|---|
| R30k | `0402WGF1003TCE` / C25741 | 100k 1% 下拉，`INk` ↔ `VB(k−1)` |
| C32k | `0402B102K500NT` / C1523 | 1nF 50V 交流耦合，`GNk` ↔ `GP(k+1)`（全级交流耦合） |
| U30k | `SN74LVC1G17DBVR` / C7394021 | 1 NC、2 `INk`、3 电源脚、4 `DRVk`、5 VCC |
| C30k | `CL05B104KO5NNNC` / C1525 | 100nF 16V 去耦（本节电芯供电） |
| R32k | `0402WGF3300TCE` / C25104 | 330Ω 死区（GP 轨 ↔ DRV 轨） |
| D31k | `1N5819WS` / C191023 | 1N5819WS，**K 接 GPk**（加速关断，和 R32k 并） |
| R31k | `0402WGF3300TCE` / C25104 | 330Ω 死区（DRV 轨 ↔ GN 轨） |
| D30k | `1N5819WS` / C191023 | 1N5819WS，**K 接 DRVk**（和 R31k 并） |
| Q30k | `AO3416` / C479060 | N 管，半桥下管，`Xk` ↔ `VB(k−1)` |
| Q31k | `AO3415A` / C5350990 | P 管，半桥上管，`VBk` ↔ `Xk` |
| C31k | `CL31A107MQHNNNE` / C15008 | 100µF 本节本地储能，`VBk` ↔ `VB(k−1)` |

首级时钟输入：**R300**（`0402WGF1001TCE`，1k / C11702）+ **C321**（`0402B102K500NT`，1nF / C1523），
`BAL_CLK` 经 R300/C321 网络送到第 1 节 U301 的 `CLK_R`。

飞电容（spec §3.1 两并联链）：**C33j ∥ C34j，各 100µF / `CL31A107MQHNNNE`**，
一端 `Xj`、另一端 `X(j+1)`，A 段画了 j=1..3（C331/C341 … C333/C343）与跨栏的第 4 级（C334/C344）。

### 1.2 版面

规格书 §7.4：A3 420×297，分两栏、自下而上。每节一个横条，条内自左向右：
① R30k/C32k → ② U30k+C30k → ③ 死区两行 + GP/DRV/GN 三条竖轨 → ④ 半桥 Q31k(QP) 上 / Q30k(QN) 下 →
⑤ `Xk` 标签 → ⑥ 飞电容链。相邻两节之间**只**通过「飞电容 + 1nF 耦合电容」相连（§3.1 原话）。
跨节一律用局部标签，**不画长导线**（§7.4）。

### 1.3 A 段收尾时的已知问题（101 条 FAIL 基线，B 段已全部修掉）

| 条数 | 检查 | 现象 | 根因 |
|---|---|---|---|
| 4 | `[8a]` | C301–C304 的 `Value` 认领不到渲染串 | 字段摆在 `R+5.08`，离锚点 >1.5mm |
| 4 | `[8e]` | `16V` 与 `GP1..GP4` 粘连 | 跨节标签墨迹与字段盒重叠 |
| 6 | `[12]` | C341/C342/C343 字段压本体 | 飞电容字段锚在 `X_FLY_L−2.54`，落在本体盒内 |
| 8 | `[9c]` | R321–R324 脚号与规格书表相反 | 见图与 §5.3 说明（§3.1 允许对调） |
| 79 | `[9g]` | 报「本页不存在的网络」 | 网表覆盖整张根图，检查器没按本页过滤（**误报**） |

A 段遗留的 101 条**没有任何一条是本页真实的电气错误**；`[9g]` 的 79 条是检查器自己的缺陷。

### 1.4 A 段遗留、B 段必须接的清单（原样执行）

1. 第 5–8 节全部器件（右栏）；
2. 飞电容 C334–C337 / C344–C347（其中 C334/C344 已在 A 段画在跨栏位）；
3. J6（C18202166）+ F300–F308（C163126）；
4. 扩自检的逐脚核对表；ERC 与自检跑到干净；写本报告。

---

## 2. 脚本结构

### 2.1 `hardware/gen/gen_03_balancer.py`（生成器，覆盖写出 03 页）

照 02 页骨架写，`uid/fmt/esc/read_symbol/parse_pins/pin_world` 等通用函数是移植的，
**没改 02/04/05 的任何文件**。要点：

- `uuid.uuid5(NS, 名字)` 按位号/用途派生 UUID → 幂等；`NS` 由 03 页文件 uuid 派生。
- `COMPONENTS` 是唯一布局真源；`a_prop_override()` 逐位号给出字段锚点与对齐（避免自动摆位把字段压到本体上）。
- 每条 `wire` 只输出 2 点；引脚处 ≥2 段导线端点相接时自动补 junction（本页 46 个）。
- 引脚几何以库读数为准，**不靠手算**：AO3416 的 G=−5.08 / S,D=2.54，**AO3415A 的 G=−6.35 / S,D=3.81**（两者不同）。
- 坐标全落 1.27mm 栅格（`SEC`/`SEC_R`/`DX`/`X_*` 都是 1.27 的整数倍）。

### 2.2 `hardware/gen/check_03_layout.py`（13 项自检）

从 `check_02_layout.py` 移植：几何 1–7、渲染 PDF 的 8a–8f（pymupdf 读 `03_balancer.pdf`）、
墨迹版面 10–13、网表逐脚核对 9b–9i。B 段改了 3 处：

1. **9c 允许 R/C/F 两脚对调**：规格书 §3.1 最后一条明说「两脚无极性件（R、C、F）1、2 脚对调都可以，
   **二极管不可对调**」。检查器原先按自造脚号判，故对 R321–R328 报 8 条假 FAIL；
   现在只对 R/C/F 认对调，D/Q/U/J 仍严格逐脚。
2. **9g 按本页过滤**：原先把整张根图的网络都当「本页应有」，故 01/04/05 页的 `GND`/`+3V3` 之类
   全被报成「本页不存在」的 79 条假 FAIL；现在只遍历本页 113 件的脚。
3. 摘要行追加「R/C/F 两脚对调 N 处（§3.1 允许）：…」。

---

## 3. 自检结果（B 段实测，2026-09-28）

```
图元解析：导线 289 段，junction 46 个，实例 113 个，引脚 274 个，文字 210 处，引脚名 274 个，图元盒 613 个
渲染复核：PDF 文字串 622 段（去重+合并后），字段认领 226/226 个，自由文字两两比对 415 段（原始 span）
墨迹版面：标签/文字墨迹 210 处（其中说明文字 7 处）、字段 226 个，与 113 个本体盒比对；检查 10/11/12/13
网表核对：逐脚核对 274/274 项（§3.1/§3.2 全页 274 脚，图纸上已画 113 件）；Footprint/LCSC 核对 113 件；
         R/C/F 两脚对调 8 处（§3.1 允许）：R321, R322, R323, R324, R325, R326, R327, R328
PASS：检查 1–9 及墨迹版面 10/11/12/13 全部通过
```

改 C30k 字段时踩过一次坑，记在这里：C30k 本体在世界坐标里是 **x±2.03 / y±2.54**（比看上去高），
字段先摆到 `R−2.54` 时 8 条 `[6] …压在本体上` 立刻报出来，最后落到 `R−3.81`（离本体顶 0.635mm）才同时满足 6 与 8a。

## 4. ERC 结果（B 段实测）

`kicad-cli sch erc --format json --output /tmp/erc03.json hardware/mp2645a-bms.kicad_sch` → `Found 6 violations`。

逐条打开 `/tmp/erc03.json` 的 `sheets[]`：**6 条全在 `path: "/"`**，标签名是
`DSG_G`、`CHG_G`、`SRP`、`SRN`、`FET_MID`、`PACK+`，类型都是 `[warning] isolated_pin_label`。
这些名字在 `hardware/03_balancer.kicad_sch` 里**一个都没有**（`grep -o` 为空），它们在
`01_power_path.kicad_sch` / `02_afe.kicad_sch` 里——是那两页自己的跨页单脚，属于别的分段的活。

**本页 `path: "/开关电容主动均衡/"` 的 `violations` 是空数组，即 0 条。**
`BAL0..BAL8` 在本页各自至少两处（J6 焊盘 + F30k 引脚 1），`BAL_CLK` 在本页也接了 R300，
所以本页没有任何孤立标签。

---

## 5. 对规格书的偏差（两处，都在 §7.4 版面建议的范围内）

### 5.1 F300–F308 没有与 `VBk` 同高

§7.4 建议「F30k 与 VBk 同高」，但左右两栏行距不同（左栏 52.07、右栏错位 26.67），
**9 只熔丝不可能同时对齐两栏 9 个 `VBk` 标签**。现在取等节距 22.86 排布：
F300 与第 1 节基线同高（y=251.46），自下而上 F300…F308。
F30k 的**两端都是标签**（脚 1 → `BALk` 全局标签，脚 2 → `VBk` 局部标签），
连接靠网表名而非导线，**电气完全等价**，只是读图时不如「同高」直观。

### 5.2 C334/C344（第 4–5 级飞电容）放在右栏最下

第 4 级飞电容两端是 `X4`/`X5`，横跨左右两栏。§7.4 说这一级「放右栏最下」，
于是摆在右栏最下一条空档（R300 与标题栏之间）：**x 用右栏链位（224.79 / 240.03），y 取 276.86**，
两件的字段一律向上摆（`Value` 到 y=267.97），避免压到标题栏（y ≥ 250 @ x ≥ 295）与页边。
同样靠 `X4`/`X5` 标签连接，电气等价。

---

## 6. 分段 B 完成情况（本段正文）

### 6.1 新增画了什么

| 项 | 数量 | 说明 |
|---|---|---|
| 第 5–8 节（k=5..8） | 44 件 | 每节 11 件，同一套画法整体平移到右栏：`DX=168.91`（133×1.27），`SEC_R = {5:224.79, 6:172.72, 7:120.65, 8:68.58}` |
| 飞电容 j=5..7 | 6 件 | C335/C345、C336/C346、C337/C347（j=4 的 C334/C344 在 A 段已画） |
| J6 | 1 件 | `XDWF-C3030WV-2*5P` / **C18202166**，`x=27.94, y=269.24` |
| F300–F308 | 9 件 | `CFS12V3T3R0` / **C163126**（§8.1b U-7：**不做 0603 降规**），一列，节距 22.86 |

**右栏为什么上移 26.67mm**：若两栏同高，第 5 节最低的下管 D 字段（`R+19.05+0.95`）会压到右下角标题栏
（y ≥ 250 @ x ≥ 295）。整列上移 21×1.27 后：第 8 节顶端字段 y=50.80（左栏标题文字止于 ~51.7，
但两栏横向隔开，不重叠），第 5 节最低 y=243.84 < 250 ✓，右栏最右墨迹 ≈385 < 410 ✓。

**J6 的接法**（spec §4）：焊盘 **n 接 `BAL(n−1)`**（n=1..9 → BAL0..BAL8），**焊盘 10 空放 NC**。
奇数焊盘在左列、偶数在右列，所以奇数脚向左引线、标签右对齐，偶数向右。
字段摆在本体下方（Ref y=278.77、Value y=281.31）：J6 右侧被 `BAL1/3/5/7` 的标签墨迹占着。

### 6.2 位号总表（113 件，与 BOM 的对应）

| 组 | 位号 | 件数 | 值 / LCSC |
|---|---|---|---|
| 每节下拉 | R301–R308 | 8 | 100k 1% / C25741 |
| 每节耦合 | C321–C328 | 8 | 1nF 50V / C1523 |
| 每节缓冲 | U301–U308 | 8 | SN74LVC1G17DBVR / C7394021 |
| 每节去耦 | C301–C308 | 8 | 100nF 16V / C1525 |
| 每节死区电阻 | R311–R318、R321–R328 | 16 | 330Ω / C25104 |
| 每节死区二极管 | D301–D308（K→DRVk）、D311–D318（K→GPk） | 16 | 1N5819WS / C191023 |
| 每节下管 | Q301–Q308 | 8 | AO3416 / C479060 |
| 每节上管 | Q311–Q318 | 8 | AO3415A / C5350990 |
| 每节储能 | C311–C318 | 8 | 100µF 6.3V / C15008 |
| 飞电容 | C331–C337、C341–C347 | 14 | 100µF 6.3V / C15008 |
| 首级时钟 | R300 | 1 | 1k / C11702（C321 就是第 1 节的耦合电容，已计入「每节耦合」行） |
| 熔丝 | F300–F308 | 9 | CFS12V3T3R0 / C163126 |
| 端子 | J6 | 1 | XDWF-C3030WV-2*5P / C18202166 |

合计 **113 件 / 274 脚**（9 个 NC：U301–U308 的脚 1，以及 J6 脚 10）。

### 6.3 自检与 ERC

见 §3、§4：自检全 PASS、逐脚核对 274/274、幂等 OK、ERC 本页 0 条。

顺手把工程测试也跑了一遍（不是 B 段的验收项，C 段还要再跑一次）：
`python3 -m unittest discover -s tests` → **Ran 22 tests … OK**；
`make -C firmware test` → **38/38 checks passed**（收敛 39 步、最终压差 10mV）。

### 6.4 本段的已知风险 / 用户已接受的项

- **线束保险丝未加**：§8.1b 的用户决定，本页只在 J6 与各节之间放 F300–F308，不再额外加线束保险丝；
  这是用户已知风险。
- **`BAL0`/`BAL8` 两端都是「被动」**：J6 焊盘与 F300/F308 都是标签端，靠网表名接到别的页。

---

## 7. 留给分段 C 的清单

1. **标题与说明文字**：标题「开关电容主动均衡（8 级半桥 + 飞电容，75kHz）」+ 说明（死区、
   全级交流耦合、停时钟收敛到全低、线束保险丝未加为用户决定的已知风险）放**左上角**。
   B 段结束时左上角已有一块 6 行的标题/说明（`gen_03_balancer.py` 的 `text_item` 区块，y=15.24–49.53），
   但它**还差规格书要求的三点**：标题没带「（8 级半桥 + 飞电容，75kHz）」；说明里没有**死区**（R31k/R32k∥D30k/D31k）
   与**停时钟收敛到全低**的表述；也**没写「线束保险丝未加是用户决定的已知风险」**。C 段补齐即可。
   另有**一条分段提示文字**（y=30.48，「右栏为第 5–8 节…」）是画图过程中的临时标注，**C 段应删掉**。
   全页仍需复核无重叠、无越界。
2. **全页验收**（照任务书 r1c）：
   - 自检全过；逐脚覆盖全部器件（已 274/274）；
   - **规格书 §3.2 的 60 个网络逐一核对**（当前检查器是按「脚 → 网络」核的，还需按「网络 → 脚集合」再核一遍）；
   - 网表里每个器件 Footprint/LCSC 非空（已 113/113）；
   - **网络类核对：`Xk`、`VBk` 在网表里必须落在 `BAL_3A`**（网类规则已按图纸名路径 `/开关电容主动均衡/X?`、
     `/开关电容主动均衡/VB?` 写，但没人验过它真的匹配上了）；
   - **本页无 `GND`、无 `CELL*` 网络**（本页连电源符号都没有，需在网表上证实）；
   - 规格书 §7 自检清单逐条打勾；
   - PDF 渲 PNG 目视一遍；
   - 幂等（已 OK，改完再验一次）。
3. **跑测试**：`python3 -m unittest discover -s tests` 与 `make -C firmware test`。
4. **报告追加「分段 C / 第 1 轮完成」**：位号总表（新 ↔ BOM）、外围点名、逐节核对结论、自检结果、建议。

---

# 8. 分段 C / 第 1 轮完成（2026-09-28 11:2x–11:4x JST）

> 本段按 `design/03_balancer-task-draw-r1c.md` 收尾。改动**只落在**三处：
> `hardware/gen/gen_03_balancer.py`（标题/说明文字）、`hardware/gen/check_03_layout.py`（新增 5 项验收检查）、
> 本报告 + 知识库。库/BOM/docs/根图/其它子图**没动**，也没跑 `tools/gen_kicad_skeleton.py`、没做 git 操作。

## 8.1 标题与说明文字（左上角，7 处文字）

| y | 字号 | 内容 |
|---|---|---|
| 15.24 | 3.5 | **开关电容主动均衡（8 级半桥 + 飞电容，75kHz）**（补上了规格书要求的副标题） |
| 24.13 | 2.0 | 内容：8 个互补半桥 QN/QP（AO3416/AO3415A）+ 8 个 74LVC1G17（本节电芯供电）+ 7 级飞电容 2×100µF；每节 C31k 100µF 本地储能。 |
| 29.21 | 2.0 | **全级交流耦合**：BAL_CLK 经 1nF（C321–C328）逐级耦合，**首级亦然（VB0 不接地）**；均衡节点经 3A 熔丝到 BAL0–BAL8；本页无 GND、无电源符号。 |
| 34.29 | 2.0 | **死区**：R31k/R32k 330Ω ∥ D30k/D31k 1N5819WS（慢开快关）防上下管直通；**停时钟/复位时 R30k 100k 下拉使各 DRV 收敛到全低**。 |
| 40.64 | 2.4 | 接口网络（跨页用全局标签，名称以本清单为准）： |
| 46.99 | 1.8 | · BAL0..BAL8（均衡节点，经 F300–F308）；· BAL_CLK（时钟输入） |
| 52.07 | 1.8 | **已知风险**：F300–F308 保护不了线束段，线束电芯端保险丝未加（用户决定的已知风险）；U301–U308.1 = NC；J6.10 = NC。 |

- **删掉**了 B 段遗留的临时分段提示文字（原 x=215.90 / y=30.48「右栏为第 5–8 节…」），规律是
  `text_item` 的 uuid 由「文本 + 坐标」派生，整块重写后生成器仍然幂等。
- 左上角这块**止于 y≈54.3**：左栏最高处是第 8 只熔丝 F308 的字段（底边 y≈64.1，x≈28），
  右栏最高处是第 8 节的字段（y≈50.8，但 x≥221），两边都不叠。检查 8a–8f / 10–13 复核通过。

## 8.2 位号总表（新 ↔ BOM）

| 组 | 本页新位号 | 件 | BOM 旧位号 | 变化 | 值 / LCSC |
|---|---|---|---|---|---|
| 每节下拉 | R301–R308 | 8 | RB1–RB15 | 15 只 1M → 8 只 100k、改值改数量（U-2） | 100k 1% / C25741 |
| 每节耦合 | C321–C328 | 8 | CC2–CC8 + 新增 C321 | C321 **新增**（首级交流耦合，U-3） | 1nF 50V / C1523 |
| 每节缓冲 | U301–U308 | 8 | UD1–UD8 | 只改名 | SN74LVC1G17DBVR / C7394021 |
| 每节去耦 | C301–C308 | 8 | CD1–CD8 | 只改名 | 100nF 16V / C1525 |
| 每节 N 管栅极 | R311–R318 | 8 | — | **新增**（U-1） | 330Ω / C25104 |
| 每节 P 管栅极 | R321–R328 | 8 | — | **新增**（U-1） | 330Ω / C25104 |
| 每节 N 管快关 | D301–D308 | 8 | — | **新增**（U-1），K→DRVk | 1N5819WS / C191023 |
| 每节 P 管快关 | D311–D318 | 8 | — | **新增**（U-1），K→GPk | 1N5819WS / C191023 |
| 每节下管 | Q301–Q308 | 8 | QN1–QN8 | 只改名 | AO3416 / C479060 |
| 每节上管 | Q311–Q318 | 8 | QP1–QP8 | 只改名 | AO3415A / C5350990 |
| 每节储能 | C311–C318 | 8 | — | **新增**（U-4） | 100µF 6.3V / C15008 |
| 飞电容 | C331–C337、C341–C347 | 14 | CF1–CF14 | 只改名（CF(2k−1)→C33k、CF(2k)→C34k） | 100µF 6.3V / C15008 |
| 首级时钟 | R300 | 1 | R_CLK | 只改名 | 1k / C11702 |
| 熔丝 | F300–F308 | 9 | F2–F10 | 只改名（F2→F300 … F10→F308） | CFS12V3T3R0 / C163126 |
| 端子 | J6 | 1 | J6 | 不变 | XDWF-C3030WV-2*5P / C18202166 |

合计 **113 件 / 274 脚**（88 件 = 8 节 ×11，+ 飞电容 14 + R300 1 + F 9 + J6 1）。
每件的 `Footprint` 与 `LCSC` 都非空且 LCSC 合 `C[0-9]+` 格式（9i，图纸侧 + 网表侧双查，113/113）。

## 8.3 外围点名（命名规则，实际按此对过一遍）

- 位号一律 **3xx「前缀 + 纯数字」**：末位数字 = 节号 k（1–8）；熔丝末位 = 节点号 k（0–8）；
  飞电容末位 = 级号 k（1–7）；`R30k`/`C30k`/`C31k`/`C32k`/`U30k`/`R31k`/`R32k`/`D30k`/`D31k`/`Q30k`/`Q31k`
  十一个模板 ×8 节，画图方与复核方按末位数字即可定位。J6 沿用原位号（与 02 页 J5 同款）。
- 嵌入符号 12 个（`jlc:` 前缀）+ 12 个 `_0_1` 子单元，逐个与 `hardware/lib/jlc/jlc.kicad_sym`
  **去空白后逐字符比对一致**（附录 B 第 9 条；U30x 的 1 脚用的是库里原有的 NC 脚，没删）。
- 网络名：局部标签 `INk`/`DRVk`/`GNk`/`GPk`/`VBk`/`Xk`/`CLK_R`（网表里带图纸名路径
  `/开关电容主动均衡/…`），跨页只用两个全局标签 `BAL0–BAL8` 与 `BAL_CLK`（9o 逐名核对过全集）。

## 8.4 逐节核对结论（8 节同构）

新增检查 **9o** 不看端子表，只从**网表本身**做结构比对：把第 k 节 11 件的每个脚连同网络名做
「角色归一化」（`VBk`→`VB#`、`VB(k−1)`→`VB@`、`INk/DRVk/GNk/GPk/Xk` 同理），8 节归一化后逐字段相同：

- 第 2–8 节归一化结构**完全一致**；第 1 节**只差 C32**（`C321.1 = CLK_R`，其余 `C32k.1 = DRV(k−1)`）——
  正是规格书 §7.2 说的「合理不对称①」。
- `DRV1–DRV7` 各 6 个脚，`DRV8` 5 个脚（没有 C329）—— §7.2 的「合理不对称②」，逐个数对上了。
- 60 个网络的成员数：`VB0`/`VB8` 5–6、`VB1–VB7` 各 10、`X1`/`X8` 4、`X2–X7` 各 6、
  `INk`/`GNk`/`GPk` 各 3、`CLK_R` 2、`BALk` 各 2（J6 焊盘 + F30k）；`BAL_CLK` 本页 1 脚 + 05 页 2 脚。
- 跨节跨度 ≤1（9o）：没有任何网络跨到「隔一节」上去——跨节只有飞电容 `Xk–X(k+1)` 与
  1nF 耦合 `DRV(k−1)–INk` 两类（附录 B 第 7 条）。

**负例实测**（证明检查会失败，不是恒真）：把第 6 节里一处 `VB5` 标签误写成 `VB6` 后重跑，
9o 报出「第 5 节与第 2 节结构不同（`U30.5` 接 `VB6`）」+「网络 `VB6` 跨第 [5,6,7] 节」，随后还原（md5 一致）。

## 8.5 自检结果（B 段的 13 项 + C 段新增 5 项，全部 PASS）

```
图元解析：导线 289 段，junction 46 个，实例 113 个，引脚 274 个，文字 210 处，引脚名 274 个，图元盒 613 个
渲染复核：PDF 文字串 625 段（去重+合并后），字段认领 226/226 个，自由文字两两比对 425 段
墨迹版面：标签/文字墨迹 210 处（其中说明文字 7 处）、字段 226 个，与 113 个本体盒比对
网表核对：逐脚核对 274/274 项；网络方向核对 60 个网络＝网表实际 60 个；Footprint/LCSC 113 件
网络类核对：BAL_3A pattern ['BAL?', '/开关电容主动均衡/X?', '/开关电容主动均衡/VB?'] 全部命中 X1–X8/VB0–VB8/BAL0–BAL8；
           BAL_CLK 未被卷入；本页无网络落进 CELL_SENSE
ERC 核对：本页 0 条、其它页 6 条（都在根图页，与本页无关）
结构核对：8 节同构（见 §8.4）；全局标签 BAL0–BAL8 + BAL_CLK
PASS：检查 1–9 及墨迹版面 10/11/12/13 全部通过（exit=0）
```

C 段给 `check_03_layout.py` 新增的 5 项，都配了负例实测（都能报错，不是恒真）：

| 项 | 查什么 | 负例实测 |
|---|---|---|
| **9j** | **网络 → 脚集合**：把 §3.1/§3.2 的端子表按网络名聚合，与网表里同名网络的实际成员逐一对（9c 是反方向）。R/C/F 二端件按 §3.1 允许 1/2 脚对调 | 表里删掉 `Q301.3` → 报「网络 `X1` 成员不符：网表多出 ['Q301']」 |
| **9l** | 本页网络全集**正好 60 个**，且无 `GND`/电源/`CELL*` 网络 | 表里把 `BAL_CLK` 写成 `BAL_CLK_TYPO` → 报「多出 `BAL_CLK`」+「`BAL_CLK_TYPO` 没出现」 |
| **9m** | 网络类：`Xk`/`VBk`/`BALk` 必须落进 `BAL_3A`、`BAL_CLK` **不许**被卷进去、本页无网络落进 `CELL_SENSE`；并直接拦 `BAL*` 这种会吞掉时钟的通配符 | ① pattern 路径改成文件名 `/03_balancer/X?` → 报 8 条 `Xk` 没落进 BAL_3A（**B 段记的那个坑真会翻车**）；② `BAL?`→`BAL*` → 报时钟被卷入 |
| **9n** | 跑 `kicad-cli sch erc` 并按图纸路径取**本页**违规，本页必须 0 条 | 与 9n 同源的路径判断；本页 0 条、根图页 6 条被正确区分 |
| **9o** | 8 节同构 + 跨节只相邻 + 全局标签全集（§8.4） | 单点把 `VB5` 误写成 `VB6` → 9o 抓到结构不同与跨节跨度 2 |

> 网络类那条要特别记一笔：**KiCad 网表里的网络名带图纸名**（`/开关电容主动均衡/X1`），
> 不是文件名。9m 用网表里的真实名字去匹配 `mp2645a-bms.kicad_pro` 的 `netclass_patterns`，
> 所以现在有证据说明 §3.3 的三条 pattern 真命中；这也意味着**改图纸名会让 3A 网络类失效**，
> 以后谁改 `03_balancer.kicad_sch` 的 sheet name 都要重跑 9m。

## 8.6 规格书自检清单逐条打勾

**§7 规则 00 各项**：

- §7.1 电容完备性：U30k 的 VCC/GND 跨接 `VBk↔VB(k−1)` 的 C30k 100nF **8/8**；半桥两源极之间
  C31k 100µF **8/8**；飞电容 C33k∥C34k **7/7** —— 9j 按 `VBk`（10 脚）与 `Xk`（4–6 脚）的成员集合核过。
  耐压：C30k 16V、C31k/C33x/C34x 6.3V、C32k 50V，与 §7.1 表一致。
- §7.2 拓扑完备性：飞电容 ✅ / 每开关一个栅驱动 U301–U308 ✅ / 死区 R31k·R32k·D30k·D31k ✅ /
  每节本地储能 C311–C318 ✅ / 时钟源与跨电位传递 R300+C321–C328+R301–R308 ✅ / 每节点一只熔丝 F300–F308 ✅ /
  未用脚 U30k.1 与 J6.10 放无连接标志 ✅（9b 核过 9 处 NC 都是真悬空）。
  同构比对见 §8.4；两处合理不对称已逐条对上。
- §7.3 封装下探：本页现有封装与 §7.3 表一致（R/C 0402、C31x/C33x 1206、D SOD-323、Q SOT-23、F 1206）。
  F300–F308 的 0603 降规（C163117）用户**未采纳**，仍按 U-7 记录在案，本页维持 1206 —— 见 §8.8 建议。
- §7.4 版面建议：两栏 4 节、自下而上、最左栏 J6 + F300–F308、每节横条五段顺序、飞电容摆两节之间、
  跨节一律标签、左侧标签 `justify right` / 右侧 `justify left`、**无 GND 与电源符号** —— 都照做了。
  两处偏差照旧（§5.1 F 未与 `VBk` 同高、§5.2 C334/C344 在右栏最下），都在 §7.4 的弹性范围内。
  骨架旧说明文字（「AO3400A/AO3401A」「3x100µF」）**已改成 AO3416/AO3415A、2×100µF**，临时提示文字已删。

**附录 B 的 11 条**：

| # | 条目 | 结果 |
|---|---|---|
| 1 | 113 件、位号前缀+纯数字（3xx 段 + J6） | ✅ 实例 113（9f 逐位号正则） |
| 2 | §3.2 的 60 网络逐网核对、274 脚、9 处 NC | ✅ 9c（脚→网络）+ 9j（网络→脚集合）+ 9b（NC 真悬空） |
| 3 | 8 节同构 | ✅ 9o（见 §8.4） |
| 4 | Q30k.2 = VB(k−1)、Q31k.2 = VBk（源极没接反） | ✅ 9c/9j（MOS 是严格核对，不在 R/C/F 对调放行之列） |
| 5 | D30k.1 = DRVk、D31k.1 = GPk（方向没画反） | ✅ 9c/9j（二极管严格核对） |
| 6 | 无 GND/电源符号、无 CELLn 标签；全局标签只有 BAL0–8 与 BAL_CLK | ✅ 9g + 9l + 9o（全局标签全集） |
| 7 | 跨节只有 CF 与 C32k 两类 | ✅ 9o（无网络跨节跨度 >1） |
| 8 | J6 焊盘 n → BAL(n−1)、10 = NC；F30k.1 = BALk、.2 = VBk | ✅ 9c/9j |
| 9 | 嵌入符号与 `jlc.kicad_sym` 逐节点一致、U30x.1 用库里的 NC 脚 | ✅ 12 个符号（含 12 个子单元）去空白后逐字符一致 |
| 10 | 根图 ERC 本页 0 条；BAL_CLK 与 05 页 PA8 相连、BAL0–8 各有 J6 + F 两脚 | ✅ 9n（本页 0 条，其它页 6 条 isolated_pin_label 都在根图页）；网表里 `BAL_CLK` 3 个节点（本页 1 + 05 页 2）、`BAL0–8` 各 2 节点 |
| 11 | 规则 00 ③：旧说明文字已更新、标签朝向正确、无重叠/越界/多余交叉 | ✅ 检查 8a–8f + 10–13（文字 7 处、字段 226/226 认领、425 段自由文字两两比对）；PNG 目视（A3 横放 420×297，1 页，无重叠、无出框） |

## 8.7 幂等与测试

- **幂等**：`python3 hardware/gen/gen_03_balancer.py` 连跑两次，`hardware/03_balancer.kicad_sch`
  md5 不变 = `9caa8c53fcb304c45472574c5d2f5c59`（B 段末为 `0ee22d01…`，差异只来自标题/说明文字这块）。
- `python3 -m unittest discover -s tests` → **Ran 22 tests … OK**
- `make -C firmware test` → **38/38 checks passed**（收敛 39 步、最终压差 10mV）

## 8.8 建议（给主代理 / 复核方 / 后续分段）

1. **该进复核了（规则 00c）**：本页可以交独立复核（不同厂商模型，建议 `models.toml` 的 review = opus）。
   复核重点建议放在三处：① 死区网络的**方向**与慢开快关的推演（`D30k` K 接 DRVk、`D31k` K 接 GPk）；
   ② 首级交流耦合后**上电/停时钟的收敛路径**（R30k 100k 下拉 + LVC 输入钳位，规格书 §1.4 的结论）；
   ③ 线束侧的 3A 与 0.16A 均衡电流核算（线束电阻已计入 `sc_equalizer`）。
2. **给 PCB 布局（§7.5）留的三个硬约束**：`C31k` 两端直接连 `Q31k.S`/`Q30k.S`（回路面积最小）；
   `Xk–X(k+1)` 走线 ≥0.6mm；F300–F308 靠近 J6。`jlc:F1206` 这个共享封装名**必须按 C163126 逐个核焊盘**（规则 0e）。
3. **`Xk`/`VBk` 的 3A 网络类现在有证据了**，但它依赖 `03_balancer.kicad_sch` 的 **sheet name** 不变；
   以后改图纸名要重跑 9m，否则 3A 会静默退回默认线宽（这正是 §3.3 记的那个坑）。
4. **未采纳项仍在案**：F300–F308 的 0603 降规（C163117，冷阻更低）是 U-7 的推荐项，用户本轮未定；
   若要改，BOM/成本表与本页封装要一起改（`docs/02-BOM.csv` 由主代理维护）。
5. **线束保险丝**：本页只保护板上（§5.3）。线束电芯端保险丝是**用户已知风险**，已写进图上说明文字，
   样板阶段建议实测线束短路场景。

---

# 9. 第 2 轮变更（2026-09-28 12:0x JST）

依据：`design/03_balancer-review-opus.md`（第 1 轮独立复核）+ 规格书 §8.1c。
改动范围严格限定在 `hardware/03_balancer.kicad_sch`、`hardware/gen/gen_03_balancer.py`、
`hardware/gen/check_03_layout.py` 与本报告；库/BOM/根图/其它子页未动。

## 9.1 P1-1 换料：D301–D308、D311–D318 1N5819WS → BAT54WS

| 项 | 第 1 轮 | 第 2 轮 |
|---|---|---|
| 库符号 | `jlc:1N5819WS` | `jlc:BAT54WSL9` |
| 值 | `1N5819WS` | `BAT54WS` |
| 立创编号 | C191023 | **C22629** |
| 封装 | SOD-323 | SOD-323（不变） |

- **规则 00 ⓪（换符号必查引脚漂移）**：从 `jlc.kicad_sym` 读出 BAT54WSL9 的引脚为
  `1`=(-5.08, 0)、`2`=(5.08, 0)，与 1N5819WS **完全同几何**，故走线坐标不用改；
  生成器只换了 `lib_id`/`value`/`LCSC` 三个字段。
- **方向复核**：BAT54WSL9 的两个脚名都是 `passive`，看不到 K/A，只能读图形——
  闭合三角形 `(1.27 1.52)(-1.27 0)(1.27 -1.78)(1.27 1.52)` 的顶点在 x=-1.27（脚 1 一侧），
  肖特基钩子在 x=-2.03..-1.02，即**顶点侧＝阴极＝脚 1**；与 1N5819WS / SS210 的
  （顶点 -1.27、底面 +1.27、钩子 -2.03..-1.02）**同一套画法**，所以"慢开快关"的
  二极管方向**没有改变**（见 §9.4 新增检查 9q 与负例）。
- **选型理由**：BAT54WS 结电容 ≤10 pF（1N5819WS 为 ~30 pF 级），死区"慢开快关"支路
  R31k/R32k 330Ω ∥ D3xk 的电荷泵时序才守得住（规格书 §8.1c）。

## 9.2 P1-2 换料：R302–R308 100k → 330k

| 项 | 第 1 轮 | 第 2 轮 |
|---|---|---|
| R301（第 1 级） | 100k C25741 | **100k C25741（不变）** |
| R302–R308 | 100k `0402WGF1003TCE` C25741 | **330k `0402WGF3303TCE` C25778** |

- 生成器改为按级选料：`r30 = (("0402WGF1003TCE","100k 1%","C25741") if k == 1
  else ("0402WGF3303TCE","330k 1%","C25778"))`，k=1 仍是 100k。
- 图上说明文字同步改写为"停时钟/复位：R301 100k、R302–R308 330k 下拉，
  **第 1 级先泄放完**避免混相"。

## 9.3 P2-4 可读性

1. **C30k 位号压字**：位号字段移到 `(X_C30 + dx + 3.81, R − 6.35)`、`justify center`，
   与值/标签分离（§8.5 的字段认领 226/226、自由文字两两比对 425 段仍全过）。
2. **Q311–Q318（P-MOS）文字倒置**：根因是字段角度公式。KiCad 的 `SCH_FIELD::GetDrawRotation()`
   **只在符号变换满足 `y1 != 0`（rot 90/270）时**才把水平/垂直互换；rot 180 时直接用存储角度，
   旧公式 `(360 − rot) % 360` 给 180°，于是文字上下颠倒。改为 **`fa = 0`** 后正立；
   同时 rot 180 下 KiCad 会把水平对齐取反，所以统一用 `justify center`（对取反免疫）。
   文件见 `hardware/gen/gen_03_balancer.py` 中 `fa` 那一处注释。
3. **标题栏**：`(rev "v0.3-draw-r2")`、`(date "2026-09-28")`。

## 9.4 新增两项自检（`hardware/gen/check_03_layout.py`）

### 9p 值 / 库符号 / LCSC 核对（24 件）

- **表 A（图 ↔ §8.1c 决策）**：R301=100k/C25741、R302–R308=330k/C25778、
  D301–D308/D311–D318=BAT54WS/C22629/`jlc:BAT54WSL9`；
- **表 B（图 ↔ `docs/02-BOM.csv`）**：逐件比对 LCSC 列，并在该行文字里找值
  （先整串比、退化成首个 token 比，避免 `1k 1%` vs `1k` 的假报）。

### 9q 二极管 K/A 方向核对（16 只，图形 + §3.2 网络）

脚号本身没有极性含义（两个脚名都是 `passive`），所以必须**图形与网络一起看**：

- (a) `lib_symbols` 里取闭合三顶点折线作三角形，顶点所在侧＝阴极侧；要求**脚 1 的坐标落在顶点侧**，
  且阴极竖杠/肖特基钩子也落在同一侧；
- (b) 网表节点按 §3.2 判 K/A：`D30k.1(K)=DRVk`、`D30k.2(A)=GNk`；`D31k.1(K)=GPk`、`D31k.2(A)=DRVk`。
  报错文案直接用 K/A 措辞，便于复核。

**负例验证**（每条均为单独注入、只有目标检查报错，避免"检查其实没生效"）：

| 注入的缺陷 | 命中 | 报错条数 |
|---|---|---|
| R302 实例 lib_id 改回 `0402WGF1003TCE` | 9p 表 A 符号名 | 1 |
| `docs/02-BOM.csv` 里 D30x 的 LCSC 改错 | 9p 表 B LCSC | 7 |
| BOM 里 R30x 的值改错 | 9p 表 B 值 | 7 |
| BAT54WSL9 图形改掉顶点/钩子位置 | 9q (a) 图形 | 32（16×2） |
| D301 整体旋转 180° | 9q (b) + 9c/9j/9o | 6，含 `[9q] D301 极性接反/接错：K(脚1) 是 'GN1'、A(脚2) 是 'DRV1'；§3.2 要求 K='DRV1'、A='GN1'` |

## 9.5 验收证据

- **幂等**：`python3 hardware/gen/gen_03_balancer.py` 连跑两次，`hardware/03_balancer.kicad_sch`
  md5 稳定 = **`8e57b0ecc86f58e3d9b49bf7c53b8c1a`**（第 1 轮为 `9caa8c53fcb304c45472574c5d2f5c59`）。
- **本页自检**：`python3 hardware/gen/check_03_layout.py` → **PASS**（检查 1–9 及墨迹版面 10/11/12/13）。
  摘要：逐脚核对 **274/274**；网络方向 **60 个网络**（网表实际 60）；Footprint/LCSC **113 件**；
  **值/LCSC/符号 24 件**；**二极管 K/A 16 只**；BOM 逐件 **113 件**；R/C/F 允许的两脚对调 8 处。
- **ERC**（`kicad-cli sch erc`）：**本页 0 条**、其它页 6 条（均为根图页的 isolated_pin_label，与本页无关）。
- **与第 1 轮的网表差异**（`kicad-cli sch export netlist --format kicadxml`，全工程 175 个网络、
  212 个元件实例）：**连接关系不同的网络 0 个、位号增删 0 个**，差异只有
  **23 件**的值/LCSC/符号：D301–D308、D311–D318（16 只）与 R302–R308（7 只）
  ——**完全符合任务书的期望**（除换料外 0 连接差异）。
- **PDF 目视**：A3 横放 1 页；字段方向全正立（`span['dir'] == (1.0, 0.0)`），
  C301 位号 (114.26, 244.16)、Q311 位号 (156.14, 246.70) 均与本体盒不重叠；
  标题栏 `v0.3-draw-r2` / `2026-09-28`；900 dpi 放大 D301：脚 1（DRV1）落在肖特基阴极杠一侧。
- **测试**：`python3 -m unittest discover -s tests` → **Ran 22 tests … OK**；
  `make -C firmware test` → **38/38 checks passed**（收敛 39 步、最终压差 10 mV）。

## 9.6 未做 / 待用户定

1. `docs/02-BOM.csv` 由主代理维护，第 2 轮换料行已同步（本页只对着它自检，未改它）。
2. F300–F308 的 0603 降规（C163117）仍是待定项（§8.8 第 4 条）。
3. 负例验证用的临时目录（`BAL_HW`/`BAL_BOM` 指向的 /tmp 拷贝）已删除。

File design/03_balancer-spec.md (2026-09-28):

# 03_balancer（分立开关电容主动均衡）设计规格书 · 供画图方照画

> 时间戳：2026-09-27 19:10 JST　编写：parts / 设计核算角色（Claude Opus）
>
> **纪律**：本轮只写了这一个文件。没有改原理图、BOM、库、docs，没有运行 git、`fetch_jlc_parts.py`、`gen_kicad_skeleton.py`。
> 手册用 `tools/fetch_datasheets.py` 下载到 `datasheets/`（本轮新下载 C479060、C5350990、C163126、C18202166，不进 git）。
>
> **数据来源**：库存、价格、基础库/扩展库来自 `python3 tools/jlc_api.py`（嘉立创 SMT 实时接口，**嘉立创库存**，美元阶梯价），查询时间就是上面的时间戳。
> 符号是否存在：按 `hardware/lib/jlc/jlc.kicad_sym` 的 `LCSC Part` 字段逐个核对（注意：字段名是 `LCSC Part`，不是 `LCSC`）。
> **KiCad 坐标 y 轴向下**。页码一律用 PDF 页号。
>
> **手册简称**：
>
> | 简称 | 文件 | 器件 |
> |---|---|---|
> | **LVC** | `datasheets/C7394021_SN74LVC1G17DBVR_UMW.pdf`（UMW，Jan.2025，14 页） | 施密特缓冲 74LVC1G17 |
> | **QN** | `datasheets/C479060.pdf`（PUOLOP AO3416，2012-7-8，5 页） | N 管 |
> | **QP** | `datasheets/C5350990.pdf`（ElecSuper AO3415A Rev-1.4，8 页） | P 管 |
> | **FUSE** | `datasheets/C163126.pdf`（TA-I CFS 系列 TCFS-XX0S004I，20 页） | F300–F308 |
> | **J6** | `datasheets/C18202166.pdf`（连欣 XDWF-C3030WV-2XXP，1 页） | 均衡端子 |
> | **MLCC** | `datasheets/C15008_Samsung_CL31A107MQHNNNE.pdf`（Samsung 总目录，84 页，没有这颗料的直流偏压曲线） | 100µF/6.3V 1206 |
>
> **接口契约**（全局标签，以 `tools/gen_kicad_skeleton.py` 的 SHEETS 为准）：`BAL0..BAL8 BAL_CLK GND`。
> **本文建议从契约里删掉 GND**（本页不再用 GND，理由见 §1.4，跨页事项 X-1）。
> **均衡线与 02 页的采样线 CELL0..8 是两套线**：BAL0..8 只经 J6 进板，本页不出现任何 CELLn 标签。
> 根图里本页的图纸名是 **「开关电容主动均衡」**，所以本页局部网络在网表里叫 `/开关电容主动均衡/X1` 这种形式，不是 `/03_balancer/X1`（§3.3）。

---

## 0. 结论速览（画图方先看这一节）

docs/03 §4 的拓扑（每节一个互补半桥 + 本节供电的 74LVC1G17 + 相邻半桥之间的飞电容 + 时钟逐级电容耦合）**原理成立**，但按手册逐项核下来，有 6 处前提不成立，必须改完再画。下面 1–6 是本规格书的**推荐方案**，也是画图方的默认画法。每一项的用户确认见 §8.1。

1. **N/P 管不能共栅直驱，必须加死区**（U-1，§1.3）。
   - docs/03 §4.3 说「74LVC1G17 边沿约 3ns，直通时间极短」。这个 2.9ns 是手册在 **50pF 负载**下测的（jlc_api 参数栏；LVC p.8 的 tpd 条件是 15pF）。
   - 本页一个驱动器要带 AO3416 加 AO3415A 两个栅极，等效约 3nF（QN p.4 Fig 11；QP p.3 Qg 9.5nC）。74LVC 输出内阻约 16–29Ω（LVC p.6–7 由 VOH、VOL 推算），栅极边沿约 **50–90ns**。
   - 在这段时间里两管同时导通。按传输特性曲线（QN p.4 Fig 7、QP p.4 Fig 2）估算，直通电流峰值约 **10A**，每节约 **0.1–0.2W**。本节的 100nF 去耦撑不住这个电流（每个边沿约 0.3µC，100nF 上要掉 3V）。
   - **修改**：每节加 2 只 330Ω 和 2 只 1N5819WS，构成「慢开、快关」网络，死区典型值 50–100ns。这两种料都是基础库，而且 BOM 里已经在用，不增加料种。
2. **空闲态改成确定的「全低」**（U-2，§1.4）。
   - docs/03 §4.3 说「停时钟后输入回到偏置中点，由施密特迟滞保持原状态」，这个前提不成立。手册 VCC=3.0V 时 VT+ 最小值只有 1.48V（LVC p.6），比中点 1.50V 还低；再加上输入漏电 ±1µA 流过 1M∥1M，会带来 ±0.5V 的偏移（LVC p.7）。
   - 结果是停时钟后，有的节可能翻成高电平。这时如果第 k 节为高、第 k+1 节为低，飞电容 CFk 会**长期跨接在两节电芯上（6.0–7.3V），超过 C15008 的 6.3V 额定电压**。
   - **修改**：每节输入只接 1 只 **100k 下拉到本节负极**（C25741，基础库，BOM 已有），不再做中点偏置。交流耦合带来的直流平移由 LVC 输入端的对地钳位二极管恢复（LVC p.4 IIK）。这样停时钟、MCU 复位、时钟卡死在高电平这三种情况，最后都会收敛到「全低」：所有 P 管导通，CFk 并在第 k+1 节上。
   - 原来的 RB1–15（15 只 1M）改成 8 只 100k。
3. **第 1 节也改成交流耦合，VB0 不接 GND**（U-3，§1.4）。
   - docs/03 §4.2 说「第 1 节以 GND=V0 为参考，可直连」。但板上 GND 是分流器电池侧的 BAT−，而 V0 是经 BAL0 线束、J6、F300 进来的电芯 1 负极。
   - 如果把两者在板上接到一起，BAL0 线束就和 200A 主回路的 BAT− 铜排并联了，会分走安培级电流，F300 可能熔断。
   - **修改**：BAL_CLK → R300 1k → C321 1nF → IN1。C321 是新增件，和其余 7 级完全相同。**本页不再使用 GND。**
4. **每节加一颗本地储能电容 CBk**（U-4，§1.5）：100µF 1206（C15008，同一个料号），跨接在 VB(k−1)–VBk 之间，共 8 颗。
   - 没有它时，半桥的 75kHz 方波电流只能从线束取。线束电感约 0.5–1µH，和 100nF 去耦谐振，本节电源上会出现约 ±1V 的振铃（§1.5 算式）。
   - 有了它，振铃降到约 ±50mV。线束只流直流均衡电流，热插拔时 8 颗串联的 CB 还能把电压均匀分到各节。
5. **均衡电流下修**（§6.1）：100mV 时典型 **0.16A**，60°C 时 0.14A，最坏 0.12A。docs/03 写的是 0.19A。
   - 差别在两处：线束导线和端子电阻没计入；有了 CB 以后，线束电阻以约 6·R_w 串联进等效电阻（§6.1 推导）。
   - 300mV 时典型 0.48A。最重的一根 BAL 线电流是 2I，约 0.96A，F300–F308 的余量足够（§5）。
6. **J6 针脚：焊盘 n 接 BAL(n−1)，焊盘 10 空**（§4）。
   - 嘉立创封装的针号是之字形：奇数号一排，偶数号一排。按这个顺序排，相邻两针（间距 3mm）之间最多只差 2 节电芯。
   - **连欣手册 C18202166 的图上没有任何针号**。之字形只是 EasyEDA 封装自己的编号，而线束侧 Micro-Fit 胶壳是按行编号的，所以线束必须按物理位置对针（§4.2）。
7. **板上保险丝只能保护板上故障，保护不了线束**（§5.3）。docs/03 §2.4 拿「线束磨破短路」作为 F2–F10 的理由，这个理由不成立。线束需要在**电芯端**另加保险丝，属于线束件（U-6）。
8. **网络类模式要改**（§3.3，X-2）：`/03_balancer/X*` 一个网络也匹配不上。
   - 应改为 `/开关电容主动均衡/X?` 和 `/开关电容主动均衡/VB?`。
   - 全局的 `BAL?` 保留。
9. **需要取库的 C 编号：没有**。推荐方案用到的所有料，符号和封装都已经在 `hardware/lib/jlc/` 里（§2.2 逐个列出）。只有当用户选了可选项 U-7（F 换成 0603 的 C163117）时，才需要取 **C163117**。
10. **上料费增量为 ¥0**：新增的只有基础库料 C191023、C25104、C25741、C15008、C1523，删掉的是基础库料 C26083。每块板元件费约多 **$0.82（约 ¥5.9）**，明细见 §2.4。

---

## 1. 拓扑复核（逐级推一遍，再质疑前提）

### 1.1 电位与网络命名

| 符号 | 含义 | 网络名 |
|---|---|---|
| 电芯 k | 第 k 节，k = 1..8，负极为节点 k−1，正极为节点 k | — |
| `BALk` | J6 一侧的节点 k 线（线束），k = 0..8 | 全局标签 `BAL0`…`BAL8` |
| `VBk` | 保险丝 F30k 之后的**板内**节点 k | 局部标签 `VB0`…`VB8` |
| `Xk` | 第 k 节半桥的输出（QN、QP 的漏极） | 局部 `X1`…`X8` |
| `DRVk` | U30k 的输出（第 k 节驱动） | 局部 `DRV1`…`DRV8` |
| `GNk`、`GPk` | 第 k 节 N 管、P 管的栅极 | 局部 |
| `INk` | U30k 的输入 | 局部 |
| `CLK_R` | R300 与 C321 之间的节点 | 局部 |

- 第 k 节的「本地地」是 VB(k−1)，「本地电源」是 VBk。本节的 U30k、Q30k、Q31k、C30k、C31k、R30k、R31k、R32k、D30k、D31k **全部只接在 VB(k−1)、VBk 和本节的局部网络上**。
- 相邻两节之间只通过两样东西相连：飞电容 CFk（接 Xk 与 X(k+1)），以及耦合电容 C32(k+1)（接 DRVk 与 IN(k+1)）。

### 1.2 逐级推导（k = 1..8）

| 项 | 第 k 节接法 | 依据 / 核算 |
|---|---|---|
| U30k 电源 | VCC(5) = VBk，GND(3) = VB(k−1)，VCC−GND = 本节电压 2.5–3.65V | LVC p.5：推荐 VCC 1.65–5.5V ✅；p.4：绝对最大 7V ✅ |
| U30k 去耦 | C30k 100nF 跨接 5 脚与 3 脚；C31k 100µF 跨接 VBk 与 VB(k−1)，靠近半桥 | §7.1 |
| 输入偏置 | R30k 100k：INk → VB(k−1)（**只下拉，不做中点偏置**） | §1.4 |
| 时钟耦合 | k = 1：BAL_CLK → R300 1k → CLK_R → C321 1nF → IN1；k ≥ 2：DRV(k−1) → C32k 1nF → INk | §1.4 |
| 驱动输出 | OUTY(4) = DRVk。DRVk 经 R31k 330Ω 到 GNk，经 R32k 330Ω 到 GPk；D30k（K = DRVk，A = GNk）加快 N 管关断；D31k（A = DRVk，K = GPk）加快 P 管关断 | §1.3 |
| N 管 Q30k | G = GNk，S = VB(k−1)，D = Xk。DRVk 为高时导通，Xk = VB(k−1) | QN p.1：1 = G，2 = S，3 = D |
| P 管 Q31k | G = GPk，S = VBk，D = Xk。DRVk 为低时导通，Xk = VBk | QP p.1 Table-2：1 = Gate，2 = Source，3 = Drain |
| 飞电容 | k = 1..7：C33k ∥ C34k 接在 Xk 与 X(k+1) 之间 | 下面「相位」两行 |
| 相位 1（全部为高） | Xk = VB(k−1)，X(k+1) = VBk，CFk 并在第 k 节上 | 各节同相，因为每一级都不反相（LVC p.3 函数表 A = Y） |
| 相位 2（全部为低） | Xk = VBk，X(k+1) = VB(k+1)，CFk 并在第 k+1 节上 | 空闲态就是相位 2（§1.4） |
| 栅源电压 | N 管：Vgs = +V_cell；P 管：Vgs = −V_cell。每管的 Vds 不超过一节电压，Vgs 也不超过一节电压 | QN 的 Vds 20V、Vgs ±12V ✅；QP 的 Vds −20V、Vgs ±10V ✅ |

第 8 节的 X8 只接 CF7 的一端，所以第 8 节半桥只服务 CF7。第 1 节的 X1 只接 CF1 的一端。这与 docs/03 §4.1 一致（8 个半桥、7 级飞电容）。

### 1.3 质疑①：共栅直驱会不会直通？74LVC 能不能把 MOS 驱够？

**(a) 栅压够不够**（静态）

- 74LVC 的输出摆幅：轻载（栅极漏电流不超过 10µA，QN/QP 的 IGSS）时 VOH ≥ VCC − 0.1V，VOL ≤ 0.1V（LVC p.6–7）。所以 |Vgs| ≈ V_cell。
- 固件规定最低 3.0V 才开均衡（`bms_config.h` 的 `BAL_MIN_CELL_MV`）。

| 管 | Vgs = 3.0V | Vgs = 3.3V | 依据 |
|---|---|---|---|
| AO3416 | 约 19–20 mΩ（25°C）；最大值按 2.5V 的 26mΩ 取上界 | 约 19 mΩ | QN p.2：21/26 mΩ @2.5V；p.4 Fig 9 |
| AO3415A | 约 42 mΩ（25°C），125°C 约 55 mΩ | 约 41 mΩ | QP p.4 Fig 5（曲线）；p.3 表：36 典型 / 47 最大 @−2.5V |

- 结论：**栅压够**。
- 手册表格和曲线对不上：QP 的表格写 36mΩ @−2.5V，但 Fig 3、Fig 5 读出来约 40–45mΩ。本文取曲线值（偏保守）。docs/03 取 42mΩ，与曲线一致。

**(b) 共栅时的直通**（动态，**docs/03 的前提不成立**）

- **栅极负载**：
  - N 管：Qg(Vgs 0→3.3V，Vds 3.3V) 约 4.5nC（Fig 11 是 Vds = 10V 的曲线，3.3V 时米勒平台更短）。
  - P 管：约 6nC（p.3 给的是 Qg 9.5nC @−4.5V/−10V）。
  - 两者合计 ≈ 10.5nC，等效 C ≈ 10.5nC / 3.3V ≈ **3.2nF**。
- **驱动能力**：
  - VCC = 3.0V 时，VOH 最小 2.3V @−24mA，所以上拉内阻不超过 (3.0 − 2.3) / 24mA ≈ 29Ω。典型值 VOH = 2.5V，对应约 21Ω。
  - VOL 最大 0.55V @24mA，所以下拉内阻约 23Ω，典型值约 16Ω（LVC p.6–7）。
- **边沿时间**：τ = 16–29Ω × 3.2nF ≈ **50–93ns**。栅压从 30% 走到 70% 约需 0.85τ，即 **43–79ns**。
  - docs/03 用的 3ns，是 jlc_api 参数栏里「2.9ns@3.3V, 50pF」的数，实际负载大了约 60 倍。
- **直通电流**（以 V_cell = 3.3V 为例，栅压扫过 1.0–2.3V 这一段时两管同时导通）：
  - N 管 Id(Vgs)：1.25V 时约 5A，1.5V 时约 15A（QN p.4 Fig 7，Vds = 5V，25°C）。
  - P 管 Id(|Vgs|)：1.25V 时约 5A，1.5V 时约 9A，1.75V 时约 14A（QP p.4 Fig 2）。
  - 两者中取较小的一边，峰值约 **10–14A**，平均约 5A，持续 43–79ns。
  - 每个边沿的电荷量 Q ≈ 0.2–0.4µC，能量 E ≈ V_cell·Q ≈ 0.7–1.3µJ。每周期有 2 个边沿，频率 75kHz，所以**每节损耗 0.1–0.2W，8 节合计 0.8–1.6W**。
  - 这份电荷只能先从本节的 100nF 取，而 0.3µC / 100nF = 3V，本节的 VCC 会被拉塌。有 CB 时可以撑住，但损耗仍然存在。
  - 各节的 Vth 与边沿都有离散，这部分耗电在各节之间不相等，会给均衡带来偏差。按 ±30% 离散估算，节间耗电差约 ±20mA；均衡「电导」约 1.6A/V，对应约 ±12mV 的均衡残差。
- **结论（P1）**：必须做死区。采用最便宜、不需要增加 IC 的「慢开快关」网络：

```
            ┌─ R31k 330Ω ─┐
DRVk ───────┤             ├──── GNk ── Q30k.G      (D30k：A = GNk，K = DRVk)
            └─ D30k ◄─────┘                        N 管经二极管快速放电关断，经 330Ω 缓慢导通
            ┌─ R32k 330Ω ─┐
DRVk ───────┤             ├──── GPk ── Q31k.G      (D31k：A = DRVk，K = GPk)
            └─ D31k ─────►┘                        P 管经二极管快速充电关断，经 330Ω 缓慢导通
```

- **死区核算**（DRVk 上升沿：P 管关、N 管开，V_cell = 3.0V，取最坏角点）：
  - P 管关断：τ_off,P ≈ (29 + 5)Ω × 1.8nF ≈ 61ns。二极管在小电流下压降约 0.2–0.3V，栅压要升到 V_cell − |Vth_p,min| = 3.0 − 0.5 = 2.5V（93%）才算关断，需要约 **2.7τ = 165ns**（最坏）。|Vth_p| 取典型 0.7V 时约 110ns。
  - N 管开通：τ_on,N ≈ (330 + 29)Ω × 1.35nF ≈ 485ns。开始导通的门槛是 Vth_n,min / V_cell = 0.45 / 3.0 = 15%，对应 **0.16τ = 79ns**（最坏）。Vth_n 取典型 0.7V 时是 23%，约 131ns。
  - 典型情况下死区约 20–50ns。最坏角点有 80ns 左右的重叠，但此时两管都在阈值附近，电流在 mA 到百 mA 量级，比无死区时的 10A 小两个数量级以上。
  - 下降沿（N 管关、P 管开）的情况对称：N 管经 D30k 放电到 0.45V 需 2.5τ ≈ 115ns，P 管经 330Ω 开始导通需约 118ns。结论相同。
- **代价**：
  - 两管要经过约 3τ ≈ 1.5–1.9µs 才完全导通，占半周期 6.67µs 的约 25%。由于飞电容回路本身的 RC（0.08Ω × 100µF ≈ 8µs）远大于这段时间，R_FSL 大约只变差 5–10%（§6.1 按 ×1.08 计入）。
  - 死区期间电流经体二极管续流，每节约 3mW（§6.2）。
- **二极管选 1N5819WS**（C191023，基础库，BOM 的 D4/D5 已在用）：
  - 40V/1A 肖特基，0.6V@1A；小电流下约 0.2–0.3V，低于 AO3416 的 Vth,min 0.45V，可以把 N 管关死。
  - 结电容约 100pF，与 1.35nF 的栅电容分压，边沿瞬间栅压只会先跳约 0.2V，仍低于 Vth,min。
  - 稳态时二极管两端电压为 0，反向漏电不起作用。
- **R 选 330Ω**（C25104，基础库，05 页 R60 已在用）。如果样板实测仍有直通，改 470Ω（C25117，基础库，库存 103 万，需取库）。死区随 R 线性增加，但完全导通会更慢。

**(c) 74LVC 的输出电流**

- 关断方向的峰值电流约为 (V_cell − 0.3V) / (16–29Ω) ≈ 0.1–0.19A，持续时间小于 50ns。
- 手册 p.4 给的 IO ±50mA 是**直流**绝对最大值，没有规定容性负载的瞬态峰值。不加 R-D 网络的原方案也是同样的峰值，驱动 MOS 栅极属于 LVC 的常见用法。
- **P2**：样板阶段看一下 DRVk 的波形和 U30k 的温升。

### 1.4 质疑②：耦合电容跨节时的直流、交流行为，以及上电和复位时的安全态

**(a) 直流**

- C32k 的两端分属相邻两节。平均电压约为（第 k−1 节输出的平均值）−（第 k 节输入的平均值），不超过约 4V，C1523 是 50V ✅。
- 不传递任何直流，所以每一节只看到本节的电位。

**(b) 交流**

- 第 k−1 节的输出摆幅 Vs = V_cell(k−1)，经 1nF 耦合到 INk。INk 对本节地的电容约为 C_IN（>2.5pF，LVC p.8）加杂散 2pF。分压损失 ≈ 4.5pF / 1004.5pF ≈ 0.5%，可以忽略。
- **旧方案（1M 接 VBk、1M 接 VB(k−1)，中点偏置）为什么不行**：
  1. 稳态时，输入以中点 V_cell/2 为中心，摆幅 ±Vs/2，高电平约为 V_cell/2 + Vs/2 ≈ V_cell，低电平约为 0。这部分没有问题。
  2. **停时钟后**，输入回到 V_cell/2。VCC = 3.0V 时中点是 1.50V，而 **VT+ 的范围是 1.48–1.92V**，所以中点可能已经高于某些芯片的 VT+；VCC = 3.3V 时，VT+,min 插值约 1.62V，中点 1.65V，同样如此；3.65V 时是 1.79V 对 1.83V（LVC p.6）。
  3. 再叠加输入漏电：I_IN 最大 ±1µA（LVC p.7），流过 1M∥1M = 500k，会产生 ±0.5V 的偏移。
  4. 所以「迟滞保持原状态」**得不到保证**。如果第 k 节翻成高电平、第 k+1 节保持低电平，就有 Xk = VB(k−1)、X(k+1) = VB(k+1)，**CFk 跨在两节电芯上，承受 6.0–7.3V，而且会一直持续**。C15008 的额定电压只有 6.3V。
  5. 反过来的组合（第 k 节低、第 k+1 节高）会让 CFk 两端短接到 0V，电容本身没有损伤，但每次进入这种状态都要泄放一次电荷。
- **新方案（只接 R30k 100k 下拉到本节地）**：
  1. 交流耦合的方波本来会以下拉电平（0V）为中心，即 ±Vs/2。低于地的半波被 LVC 输入端的对地钳位二极管拉住（LVC p.4：IIK，VI < GND，−50mA），所以实际波形被平移成**低电平约 −0.3V、高电平约 Vs − 0.3V**，形成二极管直流恢复。
  2. 钳位电流的平均值 ≈ (Vs/2) / 100k ≈ 16µA，远小于 50mA。这时输入电压约 −0.3V（二极管在 µA 级电流下的压降），高于绝对最大值 −0.5V ✅。
  3. **阈值余量**（固件保证 V_cell ≥ 3.0V、压差 ≤ 300mV）：
     - 最坏情况是发送节 3.0V、接收节 3.3V。高电平 ≈ 3.0 − 0.3 − 下垂 0.2 = 2.5V，而 3.3V 时 VT+,max 插值为 2.08V，余量 0.4V ✅。
     - 接收节 3.65V、发送节 3.35V 时，高电平约 2.85V，VT+,max 为 2.28V，余量 0.57V ✅。
     - 低电平 −0.3V，VT−,min 为 0.89V（3.0V 时），余量 1.2V ✅。
  4. **下垂**：τ = 100k × 1nF = 100µs，75kHz 半周期 6.67µs，下垂约 6.5%，即约 0.2V。只要 BAL_CLK 不低于约 20kHz，就能正常工作（固件事项 X-5）。
  5. **漏电偏移**：I_IN ±1µA × 100k = ±0.1V，远低于 VT−,min。空闲时输入被可靠地压在低电平 ✅。
  6. **空闲态**：
     - **停时钟**：固件停在低电平；如果 MCU 复位，05 页的 R52 会把 BAL_CLK 下拉。最后一个下降沿逐级传下去，各节输入随后回到 0V，所以全部为低。
     - **时钟卡在高电平**（MCU 死机、IWDG 尚未动作）：各节输入以 τ = 100µs 衰减到 VT− 以下，全部翻低。因为 VT− 有离散，各节翻转的时刻最多差约 0.3τ ≈ 30µs。这 30µs 里可能出现短暂的混相，CF 瞬时承受两节电压或被短接，属于可以接受的瞬态。

**全低时的状态**：所有 P 管导通，Xk = VBk。CF1–CF7 分别并在第 2–8 节上，第 1 节上没有飞电容。所有飞电容都只承受一节电压 ✅。

**(c) 为什么第 1 节也要交流耦合，而且 VB0 不能接 GND**（**docs/03 §4.2「可直连」这个前提不成立**）

- 板上的 GND 定义为「分流器电池侧开尔文端子单点」，也就是 BAT−（docs/03 §1）。
- VB0 是 BAL0 线束经 F300 进板后的节点，BAL0 线束的另一端接在电芯 1 负极柱上。
- 这两点只在「电芯 1 负极柱 → 主 BAT− 铜排/电缆 → 分流器」这一段上等电位，中间的主电流是 200A。
- **如果把 VB0 和 GND 在板上接到一起**，BAL0 线束（加上 F300）就和主 BAT− 通路并联了：
  - 分流 ≈ 200A × R_主 / R_BAL0 ≈ 200A × 0.2mΩ / 50mΩ ≈ **0.8A**，而且是常流。
  - 短路时如果有 800A，分流就是 3.2A，可能熔断 F300。
  - 02 页的 CELL0 也因为同样的原因不接 GND（02 规格书 §4.4 第 369 行）。
- **不接时**：直流耦合的 R_CLK 会把两点间的地电位差（200A 时约 20–60mV；短路关断的瞬间，L·di/dt 可能达到几伏到几十伏）直接加到 IN1 上。改成交流耦合（C321）后，这个直流差被隔开，瞬态则由 R300 1k 限流：ΔV = 50V 时钳位电流约 50mA，等于 IIK 的上限。
- 因此**本页不再用 GND**。首级交流耦合的回流路径是：C321 → IN1 → VB0 → F300 → BAL0 线束 → 电芯 1 负极 → 主 BAT− → 分流器 → GND → MCU。这条路径只流过几 pF 的充放电电流，量级是 µA。

**(d) 上电 / 热插拔 J6**

- J6 的 10 针不会同时接触，接触先后可能相差 µs 到 ms。
- 在所有节点都接上之前，板内各 VBk 之间靠 **8 颗串联的 C31k 100µF 做电容分压**，它们远大于其它寄生电容。标称值相等（±20%），所以每节分到的电压约为 V_stack / 节数 × (1 ± 0.2)，不超过约 4.4V。这低于 LVC 的绝对最大值 7V，也低于 C15008 的 6.3V ✅。
  - **没有 CB 时**（原方案），分压只能靠 CD 100nF（±10%），再加上半桥体二极管和 LVC 内部结构，结果不可预测。这是需要 CB 的第二个理由。
- 各 CF 经体二极管充电，初始状态为全低，所以 Xk = VBk。
- **浪涌**：每节 CB 加 CF 约 300µF（标称），I²t ≈ ½CV² / R_loop = 0.5 × 300µ × 3.65² / 0.05 ≈ 0.04 A²s，小于 FUSE p.12 给的 0.933 A²s × 0.35（10 万次浪涌降额，p.11–12）= 0.33 A²s ✅。

### 1.5 质疑③：本地储能与线束电感（**docs/03 和 BOM 都缺了这一项**）

- 相位 1 时，节点 VBk 经 Q30(k+1) 向 CFk 供电；相位 2 时，改为经 Q31k 向 CFk 供电。这两个电流相互之间不抵消，所以 VBk 节点有一个 75kHz、幅度为安培级的方波电流分量。
- **没有 CB 时**，这个电流只能先由 C30k（100nF）供给，然后来自线束。线束回路（两根导线，每根约 0.5m）的电感 L 约 0.5–1µH，与 100nF 构成谐振：
  - f0 = 1 / (2π√(0.7µH × 0.1µF)) ≈ 600kHz，Z0 = √(L/C) ≈ 2.6Ω。
  - 0.4A 的阶跃会在本节电源上激起约 **±1V** 的振铃。阻尼只有线阻加保险丝，约 0.1Ω，Q ≈ 26，几乎不衰减。
  - 后果：U30k 的 VCC 跟着跳动，阈值随之漂移；线束上有 75kHz 的强辐射；飞电容的电压也被这个振铃调制。
- **加 C31k 100µF 后**（3.3V 偏置下有效约 50µF）：Z0 = √(0.7µ / 50µ) ≈ 0.12Ω，f0 ≈ 27kHz。0.4A 阶跃只激起约 **±50mV**，阻尼比 ζ ≈ 0.08 / (2 × 0.12) ≈ 0.33 ✅。75kHz 时线束的阻抗（0.33Ω）是 CB（0.04Ω）的 8 倍，交流分量基本由 CB 就地供给，线束只流直流均衡电流。
- **代价**：8 颗 C15008，基础库，同一个料号，约 $0.59 / 块。**推荐加**（U-4）。

### 1.6 质疑④：各节静态电流差会不会造成均衡偏差

| 项 | 每节电流 | 各节是否一致 | 依据 |
|---|---|---|---|
| U30k ICC | ≤ 1µA（25°C），≤ 10µA（−40–125°C） | 一致（同型号） | LVC p.7 |
| R30k 下拉 | 0（空闲时输入就在 0V） | — | 旧方案的中点偏置每节 1.6µA，第 1 节只有 1 只下拉，偏置电流也不同 |
| MOS IDSS | ≤ 1µA @20V；实际加在管上的只有 ≤ 3.65V，远小于此 | 一致 | QN p.1，QP p.3 |
| C30k、C31k 绝缘电阻 | 每节各一颗，各节相同 | 一致 | — |
| **CF 的漏电** | 全低空闲态下，CF1–CF7 分别并在第 2–8 节上，**第 1 节没有 CF** | **第 1 节少一份** | 按 MLCC 常规绝缘电阻规格（50 Ω·F 或 10GΩ，取较小者）估，100µF 最坏 0.5MΩ，3.3V 时 ≤ 6.6µA/颗。实际值通常小一到两个数量级 |
| 均衡运行时的栅极驱动 | 约 0.8mA（Qg × f），在各节之间离散约 ±20% | 差约 ±0.16mA | §6.2 |

- **结论**：空闲时最坏的不一致是第 1 节比其它节少约 13µA（规格上限），一年约 114mAh，相当于 120Ah 的 0.095%。实际值还要小一个数量级。运行时的 ±0.16mA 相当于约 1mV 的残差。**都可以忽略**，MP2797 的被动均衡足以微调。
- 旧方案不加死区时，直通电流的离散（±20mA）才是真正的不均衡源（§1.3 b）。加了死区以后，这一项消失。

### 1.7 失效分析（逐项看保险丝能不能兜住）

| 故障 | 后果 | 保护 |
|---|---|---|
| CF 或 CB 裂片短路（MLCC 的典型失效） | CB 短路时，第 k 节经两根线束、两只 F 短路，I ≈ 3.65V / 50–90mΩ ≈ 40–73A | F30(k−1) 或 F30k 在约 1ms 内熔断（I²t 0.933 A²s ÷ 50² ≈ 0.4ms）✅ |
| CF 短路（X 节点之间） | 只在相应管子导通时有电流，约 23A 脉冲，占空比 50% | 同上。F 在约 3ms 内熔断，SOT-23 在这段时间内温升估计 < 50°C（QN 的 IDM 为 30A）✅；QP 的 IDM 只有 15.6A，脉冲超过额定值，Q31k 可能随 F 一起损坏，属于可接受的二次损坏 |
| QN 或 QP 的 D-S 击穿短路 | 对管导通时，本节被短路 | 同上 |
| U30k 失效，输出卡死 | 该节不再切换。时钟链在该节中断，上面各节衰减为全低；下面各节仍在切换，相邻的 CF 会承受混相 | 可能使一颗 CF 长期承受两节电压。**固件要监测**：均衡开着但压差不收敛时告警（X-5） |
| BALk 断线或 F30k 熔断 | VBk 浮空，被相邻两节的半桥拉到中间。如果第 k 或第 k+1 节因此掉电，时钟链中断 | 板子安全。**但固件读 CELL 电压看不出这个故障**（采样线是另一套），只能看到「均衡无效」。同上，由固件告警 |
| 线束磨破，BALk 与相邻导线短路 | 电芯直接经线束短路，**板上的 F 不在这个回路里** | **需要线束侧、电芯端的保险丝**（U-6）。docs/03 §2.4 的理由不成立（§5.3） |
| 压差很大（坏电芯，例如 2.0V 对 3.3V） | I ≈ 1.3 / 0.63 ≈ 2A，BAL 线电流 2I ≈ 4A，超过 3A | 固件在压差 > 300mV 时禁止均衡（`BAL_MAX_DIFF_MV`）。如果 MCU 死机、时钟卡死，会在 100µs 级别的时间内停振（§1.4）；即便没停住，F 也会在分钟级熔断 |

---

## 2. 完整器件表（03 页）

### 2.1 位号规则

- 本页位号一律用 **3xx 三位数**，形式为「前缀 + 纯数字」。像 `C219B` 这种带尾随字母的位号会导致 annotation 报错（知识库《KiCad 原理图自检要点》）。
- **末位数字 = 节号 k**（k = 1..8）；保险丝的末位数字 = 节点号 k（k = 0..8）；飞电容的末位数字 = 级号 k（k = 1..7）。这样画图方和复核方一眼就能看出某个器件属于哪一节。
- J6 沿用原位号（与 02 页的 J5 保持一致，不改名）。
- 与其它页不冲突：01 页是 Q1–12、RG、R_PUP 等；02 页是 2xx；04 页是 C40–45、R40–42、U4、F11、D7、L1；05 页是 5x。

### 2.2 器件表（推荐方案）

符号和封装都来自 `hardware/lib/jlc/jlc.kicad_sym`，是按 `LCSC Part` 字段 grep 出来的，**全部已有**。库存和价格按 300+ 档（不足 300 的按实际档）。

| 位号 | 数量 | 值 / 型号 | LCSC | 库 | 嘉立创库存 / 单价 | 符号名（jlc.kicad_sym） | 封装 | 备注 |
|---|---|---|---|---|---|---|---|---|
| U301–U308 | 8 | SN74LVC1G17DBVR（UMW）施密特缓冲 | C7394021 | 扩 | 11 579 / $0.0272 | `SN74LVC1G17DBVR` | `jlc:SOT-23-5_L2.9-W1.6-P0.95-LS2.8-BR` | 1 脚 NC 要放无连接标志 |
| Q301–Q308 | 8 | AO3416 N 管（PUOLOP） | C479060 | 扩 | 9 222 / $0.0316 | `AO3416_C479060` | `jlc:SOT-23-3_L2.9-W1.3-P1.90-LS2.4-BR` | 1 = G，2 = S，3 = D |
| Q311–Q318 | 8 | AO3415A P 管（ElecSuper） | C5350990 | 扩 | 5 293 / $0.0311 | `AO3415A_C5350990` | `jlc:SOT-23-3_L2.9-W1.6-P1.90-LS2.8-BR` | 1 = G，2 = S，3 = D。⚠ 与 Q30x 的封装**不是同一个**（本体宽 1.3 与 1.6），不要混用 |
| C301–C308 | 8 | 100nF 16V X7R 0402 | C1525 | 基 | 2 471 万 / $0.0034 | `CL05B104KO5NNNC` | `jlc:C0402` | U30k 的 VCC 去耦，只承受一节电压（最坏热插拔约 4.4V），16V 够用 |
| **C311–C318** | 8 | **100µF 6.3V X5R 1206**（本地储能，**新增**） | C15008 | 基 | 206 万 / $0.0738 | `CL31A107MQHNNNE` | `jlc:C1206` | U-4 |
| **C321** | 1 | **1nF 50V X7R 0402**（首级耦合，**新增**） | C1523 | 基 | 376 万 / $0.0033 | `0402B102K500NT` | `jlc:C0402` | U-3 |
| C322–C328 | 7 | 1nF 50V X7R 0402 | C1523 | 基 | 同上 | `0402B102K500NT` | `jlc:C0402` | 级间耦合 |
| C331–C337、C341–C347 | 14 | 100µF 6.3V X5R 1206（飞电容，每级 2 颗） | C15008 | 基 | 同上 | `CL31A107MQHNNNE` | `jlc:C1206` | 第 k 级为 C33k ∥ C34k |
| **R301–R308** | 8 | **100kΩ 1% 0402**（输入下拉，**取代 15 只 1M**） | C25741 | 基 | 977 万 / $0.0016 | `0402WGF1003TCE` | `jlc:R0402` | U-2 |
| **R311–R318** | 8 | **330Ω 1% 0402**（N 管栅极，慢开，**新增**） | C25104 | 基 | 130 万 / $0.0027 | `0402WGF3300TCE` | `jlc:R0402` | U-1 |
| **R321–R328** | 8 | **330Ω 1% 0402**（P 管栅极，慢开，**新增**） | C25104 | 基 | 同上 | `0402WGF3300TCE` | `jlc:R0402` | U-1 |
| R300 | 1 | 1kΩ 1% 0402（时钟串阻） | C11702 | 基 | 860 万 / $0.0014 | `0402WGF1001TCE` | `jlc:R0402` | — |
| **D301–D308** | 8 | **1N5819WS**（N 管快关，**新增**） | C191023 | 基 | 508 万 / $0.0116 | `1N5819WS` | `jlc:SOD-323_L1.8-W1.3-LS2.5-RD` | 1 = K，2 = A |
| **D311–D318** | 8 | **1N5819WS**（P 管快关，**新增**） | C191023 | 基 | 同上 | `1N5819WS` | 同上 | 1 = K，2 = A |
| F300–F308 | 9 | 3A 32V 快熔 1206，冷阻 23mΩ（大毅 TA-I CFS12V3T3R00） | C163126 | 扩 | 11 220 / $0.0288 | `CFS12V3T3R0` | `jlc:F1206` | F30k 接 BALk（k = 0..8） |
| J6 | 1 | 连欣 XDWF-C3030WV-2*5P，2×5，3.00mm，立式 | C18202166 | 扩 | 2 915 / $0.2061（150+） | `XDWF-C3030WV-2*5P` | `jlc:CONN-TH_XDWF-C3030WV-2-5P` | §4 |

- 合计 **113 个器件**：8×（U、QN、QP、CD、CB、CC、RB、RN、RP、DN、DP）= 88，加 CF 14、R300 1、F 9、J6 1（C321 已含在 CC 的 8 颗里）。按原方案（BOM 现状）是 8+8+8+8+14+7+15+1+9+1 = 79 个，推荐方案多 34 个（R/D +32、CB +8、C321 +1、RB 由 15 减到 8 即 −7）。
- **库风险**：知识库记录过，easyeda2kicad 的共享封装名（`R1206`、`F1206`、`C0402` 等）会被最后取的那颗料覆盖。`jlc:F1206` 目前属于 C163126，正好是本页要用的那颗。**PCB 阶段仍要按料号逐个核对焊盘**（规则 0e）。
- **以下几颗料没有进 BOM 的均衡段，但 BOM 其它段已经在用**：C191023（D4/D5）、C25104（05 页 R60）、C25741（05 页 R51/R52）。主代理改 BOM 时，要把它们作为本页新行加进均衡段（X-3）。

### 2.3 BOM 旧位号 → 新位号对照（供主代理改 `docs/02-BOM.csv`）

| BOM 旧位号 | 新位号 | 变化 |
|---|---|---|
| QN1–QN8 | Q301–Q308 | 只改名 |
| QP1–QP8 | Q311–Q318 | 只改名 |
| UD1–UD8 | U301–U308 | 只改名 |
| CD1–CD8 | C301–C308 | 只改名 |
| CF1–CF14 | C331–C337（CF1、CF3…CF13）、C341–C347（CF2、CF4…CF14） | 只改名。第 k 级：CF(2k−1) → C33k，CF(2k) → C34k |
| CC2–CC8 | C322–C328 | 只改名 |
| — | **C321** | 新增（首级交流耦合，U-3） |
| RB1–RB15（1M，C26083） | **R301–R308（100k，C25741）** | 改值、改数量（U-2）；BOM 里的 C26083 行删掉 |
| R_CLK | R300 | 只改名 |
| — | **R311–R318、R321–R328**（330Ω，C25104） | 新增（U-1） |
| — | **D301–D308、D311–D318**（C191023） | 新增（U-1） |
| — | **C311–C318**（C15008） | 新增（U-4） |
| F2–F10 | F300–F308（F2 → F300 = BAL0 … F10 → F308 = BAL8） | 只改名 |
| J6 | J6 | 不变 |

### 2.4 成本增量（10 块档 / 单板，美元按 300+ 档）

| 项 | 数量 | 单价 | 小计 |
|---|---|---|---|
| C15008（CB） | +8 | $0.0738 | +$0.590 |
| C191023 | +16 | $0.0116 | +$0.186 |
| C25104 | +16 | $0.0027 | +$0.043 |
| C25741 | +8 | $0.0016 | +$0.013 |
| C1523（C321） | +1 | $0.0033 | +$0.003 |
| C26083（1M） | −15 | $0.0017 | −$0.026 |
| **合计** | | | **+$0.81/块 ≈ ¥5.9/块**（另加 SMT 焊点费：净增 34 颗、约 68 个焊点，按嘉立创实际报价计） |

上料费：新增和删除的都是基础库料，**增量为 ¥0**。

---

## 3. 逐节连接表（画图方逐行照画）

### 3.1 每节通用连接（k = 1..8）

这一张表是第 k 节的「模板」。**§3.2 已经把 k = 1..8 全部展开**，画图方照 §3.2 画，本表只用来说明规律。

| 器件.引脚（引脚名） | 网络 |
|---|---|
| U30k.1（NC） | **无连接标志** |
| U30k.2（INA） | `INk` |
| U30k.3（GND） | `VB(k−1)` |
| U30k.4（OUTY） | `DRVk` |
| U30k.5（VCC） | `VBk` |
| C30k.1 / C30k.2 | `VBk` / `VB(k−1)`（紧贴 U30k 的 5、3 脚） |
| C31k.1 / C31k.2 | `VBk` / `VB(k−1)`（紧贴 Q31k 的 S 与 Q30k 的 S） |
| R30k.1 / R30k.2 | `INk` / `VB(k−1)` |
| C32k.1 / C32k.2 | k = 1 时为 `CLK_R`；k ≥ 2 时为 `DRV(k−1)`。另一端接 `INk` |
| R31k.1 / R31k.2 | `DRVk` / `GNk` |
| D30k.1（K） / D30k.2（A） | `DRVk` / `GNk` |
| R32k.1 / R32k.2 | `DRVk` / `GPk` |
| D31k.1（K） / D31k.2（A） | `GPk` / `DRVk` |
| Q30k.1（G） / .2（S） / .3（D） | `GNk` / `VB(k−1)` / `Xk` |
| Q31k.1（G） / .2（S） / .3（D） | `GPk` / `VBk` / `Xk` |

另外：

- R300.1 / R300.2 = `BAL_CLK`（全局）/ `CLK_R`
- F30k.1 / F30k.2 = `BALk`（全局）/ `VBk`（k = 0..8）
- C33k.1、C34k.1 = `Xk`；C33k.2、C34k.2 = `X(k+1)`（k = 1..7）
- J6：焊盘 n 接 `BAL(n−1)`（n = 1..9），焊盘 10 放**无连接标志**（§4）
- 两脚无极性件（R、C、F）1、2 脚对调都可以，表里的写法只是为了方便核对。**二极管的极性不可对调**：D30k 的 K 接 DRVk，D31k 的 K 接 GPk。

### 3.2 逐节展开（每个网络的全部成员）

| 网络 | 成员（器件.脚） | 网络类 |
|---|---|---|
| `BAL0` | J6.1、F300.1 | BAL_3A |
| `BAL1` | J6.2、F301.1 | BAL_3A |
| `BAL2` | J6.3、F302.1 | BAL_3A |
| `BAL3` | J6.4、F303.1 | BAL_3A |
| `BAL4` | J6.5、F304.1 | BAL_3A |
| `BAL5` | J6.6、F305.1 | BAL_3A |
| `BAL6` | J6.7、F306.1 | BAL_3A |
| `BAL7` | J6.8、F307.1 | BAL_3A |
| `BAL8` | J6.9、F308.1 | BAL_3A |
| （空） | J6.10：无连接标志 | — |
| `VB0` | F300.2、U301.3、C301.2、C311.2、R301.2、Q301.2 | BAL_3A（改模式后） |
| `VB1` | F301.2、U301.5、C301.1、C311.1、Q311.2；U302.3、C302.2、C312.2、R302.2、Q302.2 | BAL_3A |
| `VB2` | F302.2、U302.5、C302.1、C312.1、Q312.2；U303.3、C303.2、C313.2、R303.2、Q303.2 | BAL_3A |
| `VB3` | F303.2、U303.5、C303.1、C313.1、Q313.2；U304.3、C304.2、C314.2、R304.2、Q304.2 | BAL_3A |
| `VB4` | F304.2、U304.5、C304.1、C314.1、Q314.2；U305.3、C305.2、C315.2、R305.2、Q305.2 | BAL_3A |
| `VB5` | F305.2、U305.5、C305.1、C315.1、Q315.2；U306.3、C306.2、C316.2、R306.2、Q306.2 | BAL_3A |
| `VB6` | F306.2、U306.5、C306.1、C316.1、Q316.2；U307.3、C307.2、C317.2、R307.2、Q307.2 | BAL_3A |
| `VB7` | F307.2、U307.5、C307.1、C317.1、Q317.2；U308.3、C308.2、C318.2、R308.2、Q308.2 | BAL_3A |
| `VB8` | F308.2、U308.5、C308.1、C318.1、Q318.2 | BAL_3A |
| `X1` | Q301.3、Q311.3、C331.1、C341.1 | BAL_3A（改模式后） |
| `X2` | Q302.3、Q312.3、C331.2、C341.2、C332.1、C342.1 | BAL_3A |
| `X3` | Q303.3、Q313.3、C332.2、C342.2、C333.1、C343.1 | BAL_3A |
| `X4` | Q304.3、Q314.3、C333.2、C343.2、C334.1、C344.1 | BAL_3A |
| `X5` | Q305.3、Q315.3、C334.2、C344.2、C335.1、C345.1 | BAL_3A |
| `X6` | Q306.3、Q316.3、C335.2、C345.2、C336.1、C346.1 | BAL_3A |
| `X7` | Q307.3、Q317.3、C336.2、C346.2、C337.1、C347.1 | BAL_3A |
| `X8` | Q308.3、Q318.3、C337.2、C347.2 | BAL_3A |
| `BAL_CLK` | R300.1 | Default（全局，05 页 PA8 驱动） |
| `CLK_R` | R300.2、C321.1 | Default |
| `IN1` | C321.2、U301.2、R301.1 | Default |
| `INk`（k = 2..8） | C32k.2、U30k.2、R30k.1 | Default |
| `DRVk`（k = 1..7） | U30k.4、R31k.1、D30k.1、R32k.1、D31k.2、C32(k+1).1 | Default |
| `DRV8` | U308.4、R318.1、D308.1、R328.1、D318.2（**没有下一级耦合**） | Default |
| `GNk`（k = 1..8） | R31k.2、D30k.2、Q30k.1 | Default |
| `GPk`（k = 1..8） | R32k.2、D31k.1、Q31k.1 | Default |
| U301.1 … U308.1 | 无连接标志 | — |

逐脚核对数（给复核方用）：
- U 8×5 = 40，Q 16×3 = 48，两脚件 (8+8+8+8+8+8+8+8+14+1+9)×2 = 176，J6 10 个焊盘（另有 2 个无编号定位孔）。
- **合计 274 个编号引脚**。
- 网络数：BAL 9 + VB 9 + X 8 + IN 8 + DRV 8 + GN 8 + GP 8 + CLK_R 1 + BAL_CLK 1 = **60 个**。另有 NC 9 处（U30x.1 共 8 处、J6.10）。
- 电源符号：**0 个**。本页不放 GND、+3V3 或任何电源符号，VBk 全部用局部标签。

### 3.3 网络类（`hardware/mp2645a-bms.kicad_pro` 的 netclass_patterns）

- 现有模式是 `BAL_3A: ["BAL?", "/03_balancer/X*"]`。
- 本页局部网络在网表里的名字形如 `/开关电容主动均衡/X1`。KiCad 用**图纸名**（Sheetname）作为路径，而不是文件名。已用 `review/05-r4/netlist.xml` 核实：05 页的局部网络是 `/MCU 与通讯/BOOT0`。所以 `/03_balancer/X*` **一个都匹配不上**。
- **应改为**（X-2，由主代理或工具角色改 `.kicad_pro`，并同步 `gen_kicad_skeleton.py` 的 NETCLASSES）：

```
BAL_3A: "BAL?"                        → BAL0..BAL8（J6 侧，全局）
        "/开关电容主动均衡/VB?"         → VB0..VB8（保险丝之后的板内节点）
        "/开关电容主动均衡/X?"          → X1..X8（半桥输出，飞电容回路）
```

- **不要写成** `*/X?` 这种不带页名的形式，免得将来别的页出现 `X1` 这类局部网络时被误匹配。
- **不要写成** `BAL*`，否则 `BAL_CLK` 会被划进 3A 类，时钟线就变成 1.2mm 宽了。`BAL?` 只匹配一个字符，所以 BAL_CLK 不会被匹配 ✅。
- 线宽：BAL_3A 的 1.2mm 对 VB、X 两类网络偏宽。SOT-23 的焊盘只有 0.6–0.9mm 宽，走线在焊盘处要缩颈。实际电流不超过 1.2A（§5.2），**布局时可以考虑给 VB/X 单独建一个 0.6mm 的类**（P2，布局阶段再定）。

---

## 4. J6 针脚（C18202166）

### 4.1 封装实测（`jlc:CONN-TH_XDWF-C3030WV-2-5P`，按焊盘绝对坐标）

| 物理位置 | 焊盘 | 坐标 (x, y) mm | 网络 | 与相邻针的压差 |
|---|---|---|---|---|
| A1 | 1（方焊盘） | (−6.00, −1.50) | `BAL0` | B1：1 节；A2：2 节 |
| B1 | 2 | (−6.00, +1.50) | `BAL1` | A1：1 节；B2：2 节 |
| A2 | 3 | (−3.00, −1.50) | `BAL2` | B2：1 节；A3：2 节 |
| B2 | 4 | (−3.00, +1.50) | `BAL3` | A2：1 节；B3：2 节 |
| A3 | 5 | (0.00, −1.50) | `BAL4` | B3：1 节；A4：2 节 |
| B3 | 6 | (0.00, +1.50) | `BAL5` | A3：1 节；B4：2 节 |
| A4 | 7 | (3.00, −1.50) | `BAL6` | B4：1 节；A5：2 节 |
| B4 | 8 | (3.00, +1.50) | `BAL7` | A4：1 节；B5：— |
| A5 | 9 | (6.00, −1.50) | `BAL8` | B5：— |
| B5 | 10 | (6.00, +1.50) | **空（NC）** | — |
| 定位柱 ×2 | 无编号，`thru_hole`，孔径 1.10，焊盘 1.10（环宽为 0） | (±9.00, −2.44) | — | — |

- **A 行**（y = −1.5，奇数焊盘）靠近定位柱一侧：定位柱在 A 行外侧 0.94mm 处，与手册 P.C.B LAYOUT 标注的「0.94±0.05」一致。**B 行**（y = +1.5）是偶数焊盘。
- **之字形编号**：同一列是 (1,2)、(3,4)……所以**焊盘 n 就接 BAL(n−1)**。这个关系最容易记，也最不容易画错。
- **为什么这样排**：
  - 直线相邻（3.00mm）的两针之间最多差 2 节（≤ 7.3V），对角相邻（4.24mm）最多差 3 节。
  - 如果做蛇形排列（A1 BAL0 → B1 BAL1 → B2 BAL2 → A2 BAL3……），A1–A2 会差 3 节。
  - 2×5 排列里，「行内差 2、列内差 1」已经是能做到的最小最大压差。
  - 端子额定 250V（J6 手册 SPECIFICATIONS），压差完全不是问题。这样排主要是为了**相邻针短路时只短一到两节**，降低线束装配出错的后果。
- 空针放在 B5，与 BAL8 相邻。**这个空位也用作物理定向标记**（§4.2）。
- **手册核对**：
  - 连欣 C18202166 的 1 页图纸：3.00mm 间距，孔径 ⌀1.02±0.05，定位柱在两端、与引脚列偏开 3.00，距一侧那一行 0.94。封装的焊盘孔径 1.02 与手册一致 ✅。
  - **图纸没有标任何针号**，所以「之字形」只是 EasyEDA 封装自己的编号。
  - 额定 6A AC/DC（图纸 SPECIFICATIONS）；嘉立创参数栏写的是 5A。本页最大单针直流 2I ≈ 1A ✅。
  - 接触电阻 ≤ 10mΩ（图纸），已计入 §6.1 的 R_w。
- **P2（DFM）**：两颗定位柱的封装是「`thru_hole`，焊盘 = 孔 = 1.10」，环宽为 0，嘉立创会按金属化孔处理，而手册没有给定位柱孔径。布局阶段用 `fp_compare.py` 核一遍，并对照实物样品，决定改成 NPTH 还是保留（规则 0d ②）。

### 4.2 线束对针（线束件，非嘉立创件）

- 板端是 Micro-Fit 3.0 兼容的 2×5 立式针座。线束侧用 Micro-Fit 3.0 的 2×5 母胶壳（Molex 43025-1000 或兼容件），配 43030 系列端子，线规 18–20AWG。
- **Molex 胶壳是按行编号的**（一排 1–5、另一排 6–10），**与板端封装的之字形编号不同**。所以线束**一律按物理位置对针，不按针号对**：
  1. 把板端针座的**卡扣侧定为 A 行**。手册顶视图里，卡扣凸台和定位柱都在同一侧，即 A 行这一侧。**样品到手后先核对这一条**（docs/03 §2.4 已要求先买样品试插）。
  2. **空位 B5 定义为「BAL8 那一端」**。线束胶壳上对应的孔位不插端子，作为防错标记。
  3. 线束对针表（从胶壳**插合面**看，卡扣朝上时，左右与板端是镜像关系。线束图必须画成插合面视图，并标出卡扣）：

| 物理位置 | 线色建议 | 接电芯 |
|---|---|---|
| A1 | 黑 | 电芯 1 负极（BAT−，BAL0） |
| B1 | 棕 | 电芯 1 正极 = 电芯 2 负极（BAL1） |
| A2 | 红 | BAL2 |
| B2 | 橙 | BAL3 |
| A3 | 黄 | BAL4 |
| B3 | 绿 | BAL5 |
| A4 | 蓝 | BAL6 |
| B4 | 紫 | BAL7 |
| A5 | 白 | 电芯 8 正极（BAT+，BAL8） |
| B5 | — | 空孔 |

- 线色只是建议，由用户在线束图里定。
- **均衡线要单独接到电芯极柱上**，不与 J5 的采样线共用端子螺钉下的同一个线鼻（docs/03 §2.4）。
- 线束每根线在电芯端都要加保险丝（U-6，§5.3）。

---

## 5. 保险丝 F300–F308（C163126，大毅 TA-I CFS12V3T3R00）

### 5.1 参数（FUSE 手册）

| 参数 | 值 | 出处 |
|---|---|---|
| 额定电流 | 3.00A；250% 额定电流时 5s 内熔断 | p.3 表 |
| 冷阻 | **23mΩ ±25%**（17.25–28.75mΩ），在小于 10% 额定电流下测得 | p.3 |
| 额定电压 / 分断能力 | DC 32V / **50A** | p.3 |
| I²t（10 倍额定电流时的典型值） | **0.933 A²s** | p.12 |
| 温升 | 额定电流下小于 75°C | p.3、p.4 |
| 温度降额 | 25°C 为 100%，60°C 约 95%，85°C 约 91%，105°C 约 87% | p.4 曲线 |
| 选型规则 | 工作电流 < 额定电流 × 0.7 × 降额系数 | p.10 |
| 工作温度 | −20 ~ +105°C | p.4（用户 2026-09-26 已接受 −20°C 这个下限） |

### 5.2 工作电流 vs 额定值

- §6.1 推导过：相邻两节压差为 ΔV 时，中间那根 BALk 线流过 **2I**，两侧的线各流 I。
- 固件把压差限制在 ≤ 300mV：典型 I = 0.48A，所以 2I = 0.96A。线束极短（R_w 只算保险丝本身）时的上限是 0.84A，2I = 1.67A。
- 允许值：3A × 0.7 × 0.91（85°C）= **1.91A**。0.96A 和 1.67A 都在允许范围内 ✅。1.67A 这个上限情况余量只有 1.14 倍，不过它要求线束电阻为 0，实际达不到。
- 自身耗散：1A² × 23mΩ = 23mW，可以忽略。
- 有了 C31k 以后，75kHz 的交流分量基本不走保险丝（§1.5），所以用直流值核算即可。

### 5.3 保护的是什么：只保护板上，不保护线束（**docs/03 §2.4 的理由不成立**）

- F30k 串在 J6 与 VBk 之间，所以**它能保护的是板上的故障**：CB/CD/CF 裂片、MOS 击穿、U30k 击穿（§1.7）。
- **线束磨破、相邻导线短路**时，短路电流从电芯出来，经线束到短路点再回到电芯，**根本不经过板子**，F30k 起不了任何作用。
- docs/03 §2.4 写的「线束磨破短路时，单节电芯能提供上千安电流，没有保险丝就会起火」这句话，推不出「所以板上放保险丝」这个结论。02 页的采样线已经这样处理：采样线的线束侧在电芯端加保险丝（用户 2026-09-27）。**均衡线也要同样处理**（U-6）：每根 BAL 线在电芯极柱端串一只线束保险丝。
  - 额定电流要大于 3A，保证板上故障时由板上的 F30k 先熔断，线束保险丝只管线束本身。例如用 5A。
  - 做法可以是带保险丝的端子线鼻、线内串小型片式保险丝座，或者 ATO 迷你片。由用户选。

### 5.4 分断能力 vs 单节短路电流

- 板上一节被短路（例如 C31k 裂片）时，回路包括：电芯内阻约 0.5mΩ、两根线束各 5–17mΩ、两个端子接触各 2–10mΩ、两只 F 各 17–29mΩ、PCB 约 2mΩ。
- 回路电阻最小约 **50mΩ**（极短的粗线束、最小冷阻），此时 I_max ≈ 3.65 / 0.05 ≈ **73A**。常见情况（0.5m、20AWG）约 90mΩ，**约 40A**。
- **73A 超过手册给的 50A @ 32V**，但这里电源电压只有 3.65V，两节短路时也只有 7.3V：
  - 薄膜保险丝熔断后形成的间隙，需要十几伏以上才能维持电弧，3.65–7.3V 维持不住。
  - 分断能力是在额定电压 32V 下考核的，电压越低越容易分断。
  - 熔断前冷阻随温度升高，本身也会限流。
- **判定**：可以接受，**不过手册没有给低压下的分断数据，属于工程判断**。如果用户要求严格符合手册，线束长度和线规应满足「回路电阻 ≥ 75mΩ」（即 ≤ 48A），或者改用 50A 以上分断能力的保险丝（P2）。
- **熔断时间**：40A 时 t ≈ I²t / I² = 0.933 / 1600 ≈ 0.6ms，远短于 MLCC 裂片后引燃所需的时间 ✅。

### 5.5 额定电压

- 保险丝熔断后，两端电压 = BALk（电芯端）与 VBk（浮空的板内节点）之差。VBk 会被相邻两节的半桥和 CB 拉到 VB(k−1)–VB(k+1) 之间，所以差值不超过约 1–2 节，即 ≤ 7.3V。
- 即使在最极端的情况下，这个差值也不会超过整组电压 29.2V，**仍低于 32V 额定值** ✅。

### 5.6 冷阻对均衡电流的影响

- 冷阻计入 R_w。每根线的 R_w = F（23mΩ）+ 导线 + 端子接触 + PCB。
- 按 §6.1，每一对相邻电芯的均衡回路总共要串入约 **6·R_w**，其中保险丝的贡献是 6 × 23 = **138mΩ**，约占总等效电阻（0.63Ω）的 22%。
- 可选项 **U-7：换成 0603 规格的 CFS06V3T3R00（C163117，扩展库，库存 19 430，$0.0202）**：
  - 同系列 3A、32V、50A 分断，冷阻 **16mΩ**（FUSE p.3）。6 × 7mΩ = 42mΩ，**均衡电流约 +7%**，单价还便宜 30%，扩展库换扩展库，上料费不变。
  - 代价：I²t 为 0.21 A²s（p.12），浪涌余量从 8 倍降到约 1.8 倍（0.21 × 0.35 = 0.074 对 0.04）。另外需要**取库 C163117**，还要核对 `F0603` 这个共享封装名有没有被别的料覆盖。
  - 属于规则 00 ② 的封装下探。**由用户定**，默认保持 C163126（用户 2026-09-26 选定）。

---

## 6. 性能与功耗核算

### 6.1 均衡电流（75kHz，每级 2×100µF）

**模型**（`tools/bms_calc.py` 的 `sc_equalizer` 加上线束修正）：

- 板上每一相的回路：R_phase = R_N + R_P + R_ESR+走线。取 R_ESR+走线 = 0.015Ω（2 颗 100µF 并联后 ESR 约 2mΩ，走线约 2 × 5mΩ）。
- R_FSL = 4·R_phase × 1.08。其中 1.08 是死区和慢开通带来的修正（§1.3 b）。
- R_SSL = 1 / (f·C_eff) = 1 / (75kHz × 100µF) = 0.133Ω。C_eff 取 2 × 100µF 在 3.3V 偏置下的约 50%，**Samsung 总目录里没有这颗料的直流偏压曲线，需要样板实测**。
- R_eq,板 = √(R_SSL² + R_FSL²)。
- **线束项**：有 CB 时，线束只流直流。设第 k+1 节比第 k 节高 ΔV，均衡电流为 I（从第 k+1 节搬到第 k 节）：
  - 线 k+1 流 I（流出电池），线 k 流 **2I**（流入电池的公共节点 k），线 k−1 流 I。
  - 板上看到的压差 ΔV' = ΔV − I·(R_{k+1} + 4R_k + R_{k−1}) = ΔV − **6·R_w**·I。
  - 所以 **I = ΔV / (R_eq,板 + 6·R_w)**。
  - R_w = F 冷阻 23mΩ + 导线 + 端子 + PCB。0.5m、20AWG（约 17mΩ）加端子（典型 3、最大 10mΩ）加 PCB 2mΩ，约 45mΩ。
- docs/03 的算法是把 2 只保险丝的冷阻放进 R_FSL（×4 后再与 R_SSL 取平方和），没有计入导线和端子，也没有 CB。**两种模型都是近似**，但本文的模型把线束电阻作为直流串联项，与有 CB 时的物理过程一致。

| 工况 | R_N / R_P（mΩ） | R_w | C_eff | R_eq,板 | 总等效电阻 | 10mV | 100mV | 300mV |
|---|---|---|---|---|---|---|---|---|
| docs/03 原算法（参照） | 22 / 42 | （2F 放在 FSL 里） | 100µF | — | 0.517Ω | 19mA | 0.193A | 0.58A |
| **典型 25°C** | 20 / 42 | 45mΩ | 100µF | 0.358Ω | 0.628Ω | 16mA | **0.159A** | 0.477A |
| 热态 60°C | 23 / 48 | 50mΩ | 100µF | 0.395Ω | 0.695Ω | 14mA | 0.144A | 0.432A |
| 最坏（最大 Rds、85°C、C 偏低） | 30 / 60 | 55mΩ | 80µF | 0.483Ω | 0.813Ω | 12mA | 0.123A | 0.369A |
| 线束为 0（上限） | 20 / 42 | 0 | 100µF | 0.358Ω | 0.358Ω | 28mA | 0.279A | 0.837A |

- 这张表用上面的公式由 python 复算（与 `sc_equalizer(dv, r_extra=0.015)` 相同，再加 6·R_w）。
- **结论**：100mV 时典型值约 **0.16A**，不是 0.19A。120Ah 电芯有 5% 偏差（6Ah）时，如果压差一直保持 100mV，需要约 **38h**（docs/03 写的是 33h）。实际压差会随均衡推进而收窄，时间更长。
- **线束是可以优化的一项**：如果用 18AWG、0.3m 以内的线（导线约 6mΩ），R_w 降到约 33mΩ，100mV 时约 0.18A。线规和长度要写进线束图（U-6）。
- **均衡电导**：约 1.6A/V（典型）。

### 6.2 损耗（每节 / 整板）

| 项 | 算式 | 100mV（I = 0.16A） | 300mV（I = 0.48A） |
|---|---|---|---|
| 基本损耗（全部电阻上的总和） | P = ΔV·I | 16mW | 143mW |
| 其中单只 MOS 的导通损耗 | 相内平均电流 2I，形状系数约 1.1，占空 50%，所以 I_rms ≈ 1.56·I；P = I_rms²·R_ds | QP 约 3mW，QN 约 1.5mW | QP 约 27mW，QN 约 13mW（SOT-23，RθJA 90°C/W，温升 +2.4°C）✅ |
| 其中线束加保险丝 | 6·R_w·I² | 7mW | 62mW |
| 栅极驱动（每节，只在均衡时） | (Qg_N + Qg_P)·V_cell·f = 10.5nC × 3.3V × 75kHz | **2.6mW/节**（取自本节电芯 0.8mA），8 节合计 21mW | 同左 |
| 死区期间体二极管续流（每个正在工作的节对） | 2 × I_相 × V_SD × t_d × f ≈ 2 × 0.45A × 0.8V × 0.1µs × 75kHz | 约 5mW | 约 15mW |
| 直通（**推荐方案**，加了死区） | 最坏角点只有阈值附近的重叠 | < 5mW/节（估算，样板实测） | 同左 |
| 直通（**原方案**，共栅直驱） | §1.3 b | **0.1–0.2W/节，8 节合计 0.8–1.6W** | 同左 |
| 74LVC 自身 | C_PD·V²·f + I_CC·V = 9pF × 3.3² × 75kHz + 1µA × 3.3V | 约 10µW/节（LVC p.7–8） | 同左 |
| 保险丝（最重的那根线 2I） | (2I)²·23mΩ | 2.4mW | 21mW |
| CF 纹波 | 每颗 I_rms ≈ 0.27A（300mV），ESR 约 4mΩ | 可以忽略 | 约 0.3mW/颗 |

- **整板**：100mV 时约 50mW，300mV 时约 0.2W，没有热问题。
- 原方案仅直通一项就是 0.8–1.6W，而且**各节不相等**，会反过来造成节间偏差（§1.3 b）。这是推荐 U-1 的理由。
- **空闲时**（不均衡）：每节约 1µA（LVC 的 I_CC），加上 MLCC 和 MOS 的漏电。各节差异不超过约 13µA（规格上限，§1.6）。

---

## 7. 规则 00 ① 电容完备性、①a 拓扑完备性、② 封装下探、版面建议

### 7.1 电容完备性（逐 IC、逐电源脚）

| IC | 电源脚 | 去耦 / 储能 | 跨接的两个网络 | 状态 |
|---|---|---|---|---|
| U30k（k = 1..8） | 5 脚 VCC（3 脚 GND） | C30k 100nF 0402，**紧贴 5 脚与 3 脚** | VBk ↔ VB(k−1)（跨本节） | ✅ 8/8 |
| 第 k 节半桥（Q30k 与 Q31k 的源极） | Q31k.S = VBk，Q30k.S = VB(k−1) | C31k 100µF 1206，**紧贴两管的源极** | VBk ↔ VB(k−1) | ✅ 8/8（新增，U-4） |
| 飞电容 | — | C33k ∥ C34k | Xk ↔ X(k+1) | ✅ 7/7 |

- 74LVC1G17 手册没有典型应用图，只有一个 VCC 脚。100nF 是逻辑器件的惯例值。本页驱动的是约 3nF 的栅极负载，每次边沿约 10nC：只靠 100nF 时 ΔV ≈ 0.1V ✅；有 CB 时更小。
- 电容耐压：
  - C30k（16V）：稳态 3.65V，热插拔最坏约 4.4V ✅。
  - C31k 和 CF（6.3V）：稳态 3.65V ✅。在时钟卡死、各节先后衰减的约 30µs 窗口里，CF 可能短暂承受两节电压（7.3V），属于瞬态。MLCC 出厂耐压测试通常按 150–250% 额定电压做，可以接受（P2）。
  - C32k（50V）：≤ 4V ✅。

### 7.2 拓扑完备性（规则 00 ①a：按「电荷泵 / 开关电容」逐项点名）

| 必需件 | 本页 | 状态 |
|---|---|---|
| 飞电容 | C331–C337 / C341–C347 | ✅ |
| 每个开关的栅极驱动 | U301–U308，一节一个，由本节电芯供电 | ✅ |
| 上下管互锁 / 死区 | R31k/R32k + D30k/D31k | ✅（新增，原方案缺） |
| 输入/输出储能（这里是每节的本地储能） | C311–C318 | ✅（新增，原方案缺） |
| 时钟源与跨电位传递 | R300 + C321–C328 + R301–R308 | ✅ |
| 故障隔离（每个节点一只熔断器） | F300–F308 | ✅ |
| 未用脚处理 | U30k.1 NC → 无连接标志；J6.10 → 无连接标志 | ✅ |

- **同构比对**（知识库给出的免费交叉检查）：8 节电路完全同构。复核时把 8 节的网表按 §3.2 并排列出来，任何一节少一颗件都能一眼看出来。
- 仅有两处**合理的不对称**：第 1 节的耦合来自 CLK_R，而不是 DRV0；第 8 节的 DRV8 没有下一级耦合电容。

### 7.3 封装下探（规则 00 ②，逐颗问「能不能再小一号」）

| 器件 | 现封装 | 最坏功耗 / 应力 | 能否再小 | 结论 |
|---|---|---|---|---|
| R301–R308（100k） | 0402 | < 1µW | 0201 没必要，嘉立创 0201 也不是基础库 | 0402 ✅ |
| R311–R328（330Ω） | 0402 | 栅极充放电约 1.3mW | 同上 | 0402 ✅ |
| R300（1k） | 0402 | 瞬态钳位时 50V × 50mA，持续 ns 级 | — | 0402 ✅ |
| C301–C308（100nF） | 0402 | — | — | 0402 ✅ |
| C321–C328（1nF） | 0402 | — | — | 0402 ✅ |
| C331–C347、C311–C318（100µF） | 1206 | 要容量 | 0805 的 100µF/6.3V 是扩展库，而且 3.3V 偏置下容量更低（docs/03 §8） | 1206 ✅ |
| D301–D318 | SOD-323 | 峰值约 0.19A，持续 50ns | SOD-523 不是基础库 | SOD-323 ✅ |
| F300–F308 | 1206 | 最大 1.67A | **0603 的 C163117（3A、16mΩ）可以用，而且冷阻更低**（U-7） | 由用户定（§5.6） |
| Q30x / Q31x | SOT-23 | ≤ 27mW | — | ✅ |

### 7.4 版面建议（原理图，A3 横放 420×297mm）

- **分两栏，每栏 4 节，自下而上排列**：
  - 左栏由下往上是第 1–4 节，右栏由下往上是第 5–8 节。
  - 电位从下往上升高，与电池组的实际顺序一致，读图时一眼就能对上「第几节」。
  - 最左边一竖列放 J6 和 F300–F308。F30k 摆在与 VBk 同一高度的位置，出线用 `VBk` 局部标签送到各节。
- **每节一个横条**（高约 30mm），从左到右依次为：
  1. 输入：C32k、R30k（R30k 竖放，下端接 `VB(k−1)` 标签）；
  2. U30k（5 脚朝上接 `VBk`、3 脚朝下接 `VB(k−1)`，C30k 贴在旁边竖放）；
  3. R-D 网络：R31k ∥ D30k 在上、R32k ∥ D31k 在下，或者反过来，但 8 节要统一；
  4. 半桥：Q31k（P 管）在上、Q30k（N 管）在下，漏极相对接到 `Xk`，C31k 竖放在两管源极之间；
  5. 最右边是 `Xk` 标签。
- 飞电容 C33k/C34k 摆在第 k 节与第 k+1 节两个横条**之间**的右侧，两端分别用 `Xk`、`X(k+1)` 标签。第 4 节与第 5 节跨栏，那一级（C334/C344）放在右栏最下面，同样用标签相连。
- 时钟链：DRVk 的标签从第 k 节右侧引出，接到第 k+1 节最左边的 C32(k+1)。**跨节一律用局部标签**，不要画长导线跨越各节，以免画面上出现大量交叉。
- **各节电位不同，相邻两节之间只能有两处相连：飞电容，以及 1nF 耦合电容**。复核时逐节核对，除了这两类器件和同名的 VB 标签以外，不能有任何导线跨节。
- 标签规范：`VBk`、`Xk` 等标签的文字朝远离器件的方向生长。左侧标签用 `justify right`，右侧用 `justify left`（规则 00 ⓪c）。
- 骨架文字要更新：「AO3400A/AO3401A」「3x100µF」是旧方案，画图方要把这两处说明文字改成 AO3416/AO3415A、2×100µF，或者直接删掉（规则 00 ③「多余文字」）。
- **不放任何 GND 或电源符号**（§3.2）。

### 7.5 PCB 布局要点（供布局阶段）

1. **8 节排成一列**，与电池组的电位顺序一致：J6 在板边，F300–F308 靠近 J6，然后是第 1 到第 8 节依次排开。每节的 Q30k、Q31k、C31k、U30k、C30k、R-D 网络围成一小块，**本节的回路面积要尽量小**：C31k 的两端直接连到 Q31k.S 与 Q30k.S。
2. 飞电容 C33k/C34k 放在第 k 节与第 k+1 节之间，**Xk 到 X(k+1) 的回路要短而宽**（≥ 0.6mm，最大约 1A）。
3. **均衡区不接板级 GND**。In1 的 GND 平面可以在这一区完整保留（X 节点对平面的耦合只有 4pF 量级，8 个节点同相，共模电流约 1mA，可以忽略），但**这一区不许打 GND 过孔，也不许把 VB0 接到 GND**。
4. 时钟耦合线（DRVk → C32(k+1) → IN(k+1)）要短，远离功率 MOSFET 和分流器的开尔文线（docs/03 §4.5）。
5. **CELL 线（02 页）和 BAL 线在板上完全分开走**（02 规格书 X-8）。
6. 均衡区与 AFE 区之间留出间距，避免 75kHz 的开关边沿耦合到 VC 采样线上。
7. 建议给 VB0–VB8 各留一个测试焊盘（P2，不增加器件），样板阶段用来测每节的纹波和直通。

---

## 8. 待用户定清单与跨页事项

### 8.1 待用户定（推荐项已作为本规格书的默认画法）

| 编号 | 事项 | 选项 | 推荐 | 依据 |
|---|---|---|---|---|
| **U-1** | 半桥驱动加死区 | A：共栅直驱（原方案，每节直通约 0.1–0.2W，还会造成节间偏差）；**B：每节 2R + 2D 慢开快关**（+32 颗基础库件，约 +$0.23/块） | **B** | §1.3 b |
| **U-2** | 输入偏置 | A：2 × 1M 中点偏置（原方案，停时钟后状态不确定，CF 可能长期承受两节电压）；**B：只接 100k 下拉**（15 → 8 颗） | **B** | §1.4 b |
| **U-3** | 首级时钟耦合 / VB0 与 GND 的关系 | A：R_CLK 直连 IN1，VB0 接 GND（原方案，BAL0 线会分走主回路电流）；**B：交流耦合（+C321），VB0 不接 GND，本页不用 GND** | **B** | §1.4 c |
| **U-4** | 每节加本地储能 C31k 100µF | A：不加（原方案，每节约 ±1V 振铃）；**B：加 8 颗 C15008**（约 +$0.59/块） | **B** | §1.5 |
| **U-5** | 均衡电流口径 | docs/03 写的 0.19A@100mV **改为** 0.16A（典型）/ 0.12A（最坏），120Ah 偏差 5% 约 38h | 改 | §6.1 |
| **U-6** | 线束（非嘉立创件） | ① 每根 BAL 线在**电芯端**加保险丝（建议 5A，大于板上 3A）；② 线规与长度（建议 18–20AWG，≤ 0.5m，越短越好）；③ 线束对针按 §4.2 的物理位置表；④ Micro-Fit 2×5 母胶壳加端子 | 按 §4.2、§5.3 | §5.3 |
| **U-7** | F300–F308 换 0603 的 C163117（16mΩ） | A：保持 C163126（默认）；B：换料（均衡电流约 +7%，每颗便宜约 $0.009，I²t 余量降到约 1.8 倍，需要取库） | A 或 B 皆可，由用户定 | §5.6 |
| U-8 | 保险丝低压分断 | 接受「3.65–7.3V 下形成不了电弧」这个工程判断，或者要求线束回路电阻 ≥ 75mΩ | 接受 | §5.4 |

**如果用户否决 U-1 到 U-4 中的某一项**，画图方按**附录 A**里对应的原方案画法执行。（已由 §8.1b 用户决定取代，附录 A 作废）

### 8.1b 用户决定（2026-09-27/28，画图方照此画）

| 编号 | 用户决定 | 画法 / 落实 |
|---|---|---|
| U-1 | **采纳 B**：加死区 R-D 网络 | R311–R318、R321–R328（330Ω C25104）+ D301–D308、D311–D318（C191023），按 §3 |
| U-2 | **采纳 B**：只接 100k 下拉 | R301–R308（100k C25741），取代 RB1–RB15 |
| U-3 | **采纳 B**：首级交流耦合，VB0 不接 GND，本页不用 GND | 新增 C321；本页不放 GND 符号；契约删 GND（docs/03 §1、`gen_kicad_skeleton.py` SHEETS 已改） |
| U-4 | **采纳 B**：每节加本地储能 | C311–C318（C15008） |
| U-5 | **接受**：均衡电流口径 0.16A@100mV（典型），120Ah 偏差 5% 约 38h（计 95% 效率约 39.5h） | `tools/bms_calc.py` 的 `sc_equalizer` 已加线束参数 `r_wire`（X-8 已完成），docs/03 §4 已改 |
| U-6 | **暂不加**线束电芯端保险丝 | ⚠ **已知风险（用户决定）**：线束磨破、相邻导线短路时，短路电流不经过板上 F300–F308，**没有任何保护**，单节电芯可提供上千安电流，存在线束烧毁/起火风险。线规与长度、对针表仍按 §4.2 执行，防磨护套与固定在线束图里写明。已记入 docs/03 §2.4 |
| U-7 | **保持 C163126**（1206，23mΩ） | 不换 C163117，不取库 |
| U-8 | **接受**低压分断的工程判断 | §5.4 |

- **附录 A（原方案画法）作废**。画图方只按本规格书 §2–§4 的推荐方案画。
- 同时落实的文件：`docs/02-BOM.csv` 均衡段（§2.3 对照）、`docs/03-详细设计.md` §1/§2.4/§4/§9、`hardware/mp2645a-bms.kicad_pro` netclass_patterns（BAL_3A = `BAL?`、`/开关电容主动均衡/X?`、`/开关电容主动均衡/VB?`）、`tools/gen_kicad_skeleton.py` SHEETS（03 页删 GND、改说明文字；NETCLASSES 未同步，工具不再运行）、`tools/bms_calc.py` 与 `tests/test_bms_calc.py`。
- 仍未落实：X-5 固件（只在本规格书列出，未改代码）、X-9 知识库。

### 8.2 跨页事项（交主代理、其它页、工具、固件）

| 编号 | 对象 | 事项 | 级别 |
|---|---|---|---|
| **X-1** | `tools/gen_kicad_skeleton.py` SHEETS、docs/03 §1 | 03 页的对外网络改为 `BAL0..BAL8 BAL_CLK`（**删掉 GND**）；说明文字改成 AO3416/AO3415A、2×100µF、75kHz、「死区 R-D、本地储能」 | P1（文档/骨架） |
| **X-2** | `hardware/mp2645a-bms.kicad_pro` netclass_patterns，以及 `gen_kicad_skeleton.py` NETCLASSES | `/03_balancer/X*` 改为 `/开关电容主动均衡/X?`，再加一条 `/开关电容主动均衡/VB?`（§3.3） | P1 |
| **X-3** | `docs/02-BOM.csv` 均衡段 | 按 §2.3 改位号，新增 C311–C318、C321、R311–R328、D301–D318，RB 改为 R301–R308（100k C25741），删除 C26083 行 | P1（用户确认后） |
| X-4 | docs/03 §4.1–§4.3、§2.4、§7；docs/00 §2 表 | ① §4.3「边沿约 3ns」「偏置中点 + 迟滞保持」「可直连」三处前提改正；② §4.1 电流表改为 §6.1 的数值；③ §2.4 保险丝理由改为「保护板上故障，线束另在电芯端加保险丝」；④ §7 电容表 74LVC1G17 行加上本地储能 C31k；⑤ docs/00 §2 表里「AO3400A、50kHz、3×100µF、0.18A」是旧数据 | P2（文档） |
| **X-5** | 固件 `firmware/` | ① BAL_CLK 保持 **50–100kHz、50% 占空比**（100k × 1nF 下垂的限制，§1.4 b）；② **停时钟时要停在低电平**：TIM1 输出空闲电平 OIS1 = 0，关 MOE 或把 CCR 置 0，不要让引脚停在高电平；③ 保持 IWDG（时钟卡在高电平时靠 100µs 衰减可以自停，但会有短暂混相）；④ 新增「均衡有效性」判定：均衡会话持续 N 分钟后，相邻压差仍不下降，就告警「均衡通道故障」，因为 BAL 线断开、F 熔断、U30k 失效都只能这样发现（§1.7）；⑤ 现有的 300mV、3.0V 禁止条件保持不变 | P1（固件） |
| X-6 | 05 页 | BAL_CLK 的 R52 100k 下拉**保留**。首级改成交流耦合后，05 规格书里「PA8 漏电 3µA × 03 页 1M」那条分析就不成立了，R52 只用来保证复位时是低电平。05 页**不需要改图** | 提醒 |
| X-7 | 02 页 | CELL0..8 与 BAL0..8 严禁在板上相连（02 规格书 X-8），本页遵守：没有 CELL 标签。VB0 与 CELL0、GND 都不相连 | 提醒 |
| X-8 | `tools/bms_calc.py` 的 `sc_equalizer` | 加一个线束参数 `r_wire`：I = ΔV / (R_eq + 6·r_wire)，r_extra 里去掉保险丝，只保留 ESR 和走线 0.015Ω；对应的单元测试也要更新（`tests/`） | P2（工具） |
| X-9 | 知识库 | 写入「74LVC 的 tpd 是 15–50pF 条件下的数，驱动 MOS 栅极时要按 Qg 算边沿」「交流耦合时用下拉加钳位二极管做直流恢复，不要用中点偏置去依赖迟滞」「板上保险丝保护不了线束」 | 由主代理写 |

### 8.3 样板实测清单（推荐方案仍需实测确认的前提）

1. C15008 在 3.3V 偏置下的实际容量（决定 R_SSL）。
2. 每节的直通：用电流探头测 BALk 线束，或者拆掉 CF 后，比较开关时钟与不开时钟时本节电流的差值。目标每节 < 5mW。
3. DRVk、GNk、GPk 三处波形：死区不能为负（不能出现两管同时导通）。
4. 各节 VBk 上的纹波：有 CB 时应小于 100mVpp。
5. 停时钟、MCU 复位、时钟卡在高电平三种情况下，各 Xk 最终都等于 VBk（全低）。
6. 100mV 压差下的实际均衡电流，与 §6.1 的 0.16A 比对。
7. J6 样品：定位柱孔径，以及卡扣与 A 行的对应关系（§4.1–4.2）。

---

## 附录 A：用户否决某项推荐时的原方案画法（**已作废**：用户 2026-09-27 采纳 U-1～U-4，仅作记录）

| 否决的项 | 画法 |
|---|---|
| U-1（不加死区） | 删除 R311–R328、D301–D318。GNk、GPk 并入 DRVk（Q30k.1、Q31k.1 直接接 DRVk） |
| U-2（中点偏置） | R30k 保持接 INk → VB(k−1)，每节再加 1 只 1M 接 INk → VBk（k = 2..8）。R301 只接下拉。阻值用 1M（C26083），位号 R331–R337（k = 2..8 → R33k，只用于上拉）。**不推荐**，停时钟后的状态得不到保证（§1.4 b） |
| U-3（首级直连） | 删除 C321，R300.2 直接接 IN1。VB0 仍然**不要**接 GND（这一条不属于可选项，§1.4 c） |
| U-4（不加 CB） | 删除 C311–C318 |

## 附录 B：画图方自检清单（画完逐条打勾，复核方逐条复核）

1. 本页的器件共 113 个（推荐方案），位号全部是「前缀 + 纯数字」（3xx 段，以及 J6）。
2. 网表逐网核对 §3.2 的 60 个网络，成员一一对应：274 个编号引脚，9 处无连接标志（U301–U308 的 1 脚、J6.10）。
3. 8 节同构：把 8 节的网表并排列出来比对，除了 §7.2 所说的两处以外，没有其它不对称。
4. 每个 Q30k 的 2 脚（S）接 VB(k−1)，每个 Q31k 的 2 脚（S）接 VBk。**N 管、P 管的源极没有接反**：接反的话体二极管会直接短路本节。
5. D30k 的 1 脚（K）接 DRVk，D31k 的 1 脚（K）接 GPk。**二极管方向没有画反**：画反的话死区会变成「快开慢关」，直通反而更严重。
6. 本页没有 GND、+3V3 或任何电源符号，也没有 CELLn 标签。全局标签只有 BAL0–BAL8 和 BAL_CLK。
7. 跨节的连接只有 CF（Xk–X(k+1)）和 C32k（DRV(k−1)–INk）两类。
8. J6：焊盘 n 接 BAL(n−1)，焊盘 10 为 NC。F30k 的 1 脚接 BALk，2 脚接 VBk。
9. 嵌入符号与 `jlc.kicad_sym` 逐节点一致（知识库验收三件套）。U30x 的 1 脚 NC 使用库里原有的引脚，不要删除。
10. 根图 ERC：本页 0 条。BAL_CLK 与 05 页 PA8 相连，不应再报 `isolated_pin_label`；BAL0–8 只在本页出现，但每个都连着 J6 与 F30k 两个引脚，也不应报。
11. 规则 00 ③：骨架里的旧说明文字已更新；标签朝向正确；没有重叠、越界或多余交叉。

### §8.1c 用户决定（2026-09-28，Opus 复核 r1 的两条 P1）
- **D301–D308、D311–D318 改 BAT54WS（C22629，符号 `jlc:BAT54WSL9`，同 SOD-323 封装）**：1N5819WS 结电容约 110pF@4V，翻转时经分压把待开通管栅极抬高 0.26–0.9V（阈值 0.45–1.0V），死区失效；BAT54WS ≤10pF。
- **R302–R308 改 330k（C25778，`jlc:0402WGF3303TCE`），R301 保持 100k**：时钟卡高/MCU 慢掉电时第 1 级最先翻低（≤133µs），其下降沿同步带低后续各级（最早约 169µs），消除约 50µs 混相。

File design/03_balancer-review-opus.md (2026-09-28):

# 03_balancer 独立复核报告（Opus，复核方）

> 时间戳：2026-09-28 11:45 JST（`TZ=Asia/Tokyo date` 实查）　复核方：Claude Opus（画图方 DeepSeek，不同厂商）
> 快照：`review/03-r1/`（`03_balancer.kicad_sch` md5 `9caa8c53…c59`，与 `hardware/03_balancer.kicad_sch` 相同）、`erc.json`、`netlist.xml`、`sch.pdf` 第 4 页。
> 没有读画图方报告和 `*-draw-*.out`，以下结论全部独立重推。没有改工程文件。kicad-cli ERC 的输出写在 scratchpad。
> 说明：有一次误跑了只读的 `git status`（没有写操作），特此说明。
>
> 分级口径：**P0** = 接错或会损坏器件，改完才能往下走；**P1** = 设计前提不成立或可靠性风险，布局或下单前要处理（本轮的 P1 都只改 BOM 里的值或料号，不动拓扑和封装）；**P2** = 改进、文档、可读性，或留到样板阶段实测。

## 结论速览

- **P0：0 条。** 274 个编号引脚逐一对照规格书 §3.2 的期望网络（程序比对 265 个连接加 9 处 NC），**0 处不符**，也没有多余连接。极性和引脚全部正确：N/P 管的 S/D/G、二极管 K/A、74LVC 的 VCC/GND、J6 的焊盘、F 的方向都对。
- **P1：2 条。** 都是「推导链上游前提」的问题，拓扑本身不用改：
  1. 1N5819WS 的结电容会把栅极直接「踢」过阈值，死区被吃掉。
  2. 时钟卡高或 MCU 掉电时，各级异步衰减造成混相。规格书只按「瞬态可接受」处理，没有算浪涌电流。实际峰值会超过 AO3415A 的 IDM。
- **P2：8 条。**

---

## P0

无。

---

## P1

### P1-1　D301–D308、D311–D318（1N5819WS）的结电容会吃掉死区，「慢开」失效

- **位置**：D30k（K = DRVk，A = GNk）、D31k（A = DRVk，K = GPk），以及 Q30k.1、Q31k.1。
- **机理**：DRVk 翻转的瞬间，**正要开通的那只管子**的二极管被反偏。二极管的 Cj 与该管栅极电容构成电容分压，DRV 的阶跃会**不经过 330Ω**，直接瞬时耦合到栅极：
  - 上升沿时 D30k 反偏，GNk 被上踢；
  - 下降沿时 D31k 反偏，GPk 被下踢。
- **数据**：
  - 1N5819WS 的 Cj 典型值为 **110pF @ VR = 4V**（Hottech 手册 p.1，C191023；手册不在 `datasheets/`，本次下载到 scratchpad 读的）。0–3.3V 偏置下更大，按电荷平均估计约 150–250pF。
  - 阈值以下的栅极电容取 Ciss：AO3416 为 660pF @ Vds = 10V（QN p.2），3V 时约 750pF（QN p.4 Fig 10）；按 Fig 11 初段斜率则约 1.3nF。AO3415A 为 750pF（QP p.3）。
- **计算**：踢量 = V_cell × Cj / (Cj + Cg) = 3.3 × (110–250) / (110–250 + 660–1300) ≈ **0.26–0.9V**。
  - 对比：AO3416 的 Vth 为 0.45 / 0.7 / 1.0V（min / typ / max，QN p.2），AO3415A 的 |Vth| 为 0.5 / 0.7 / 0.9V（QP p.3）。
  - 所以在低 Vth 的器件上，开通管在 t = 0 就已经越过阈值。规格书 §1.3(b) 按 1.35nF（大信号 Qg/V）算出「只踢 0.2V」和「N 管开通延迟 79–131ns」，这个前提不成立。
- **后果**：
  - 在「另一只管经二极管关断」的约 110–165ns 内，开通管以 Vgs ≈ 0.5–1.0V 导通。按 QN p.4 Fig 7 读，25°C 时 < 0.5A，125°C 时约 1–2A。
  - 估算每节每个边沿 20–50nC，乘以 3.3V、再乘 2 × 75kHz，约 **10–25mW/节**。规格书 §6.2 的目标是 < 5mW，而且这部分耗电在各节之间离散，重新带回了 U-1 想消除的节间偏差。
  - 程度远小于无死区时的 0.1–0.2W，所以定为 P1，不是 P0。
- **建议**（任选其一，封装都不变，SOD-323 焊盘兼容，只改 BOM）：
  - (a) 把 16 只二极管换成**低 Cj 的小信号肖特基**，例如 BAT54WS（C22629，CJ 手册在 `datasheets/`）：CT ≤ 10pF @ 1V，踢量约 0.04V。VF 为 0.24V @ 0.1mA、0.32V @ 1mA，能把栅压拉到低于 Vth,min。IFRM 300mA，IFSM 600mA，可以承受 0.1–0.19A 的关断脉冲。**是否基础库、库存多少，要用 `jlc_api.py` 查**。另外它的引脚要按 CJ 手册核：SOD-323，带色环的一端是 K。
  - (b) 保留 1N5819WS，把「DRV/GN/GP 波形 + 本节直通电流」作为样板的必测项（规格书 §8.3 第 2、3 条），并事先把 (a) 列为预案。
  - 规格书 §1.3(b)、docs/03 §4.3「典型死区 20–50ns」的说法要按上面的结果改正。

### P1-2　时钟卡高 / MCU 掉电时各级异步衰减：混相浪涌超过 AO3415A 的 IDM，规格书只说「可接受的瞬态」

- **位置**：R301–R308、C321–C328，IN1–IN8；影响 X1–X8、Q30k/Q31k、C33k/C34k。
- **触发条件**：
  - BAL_CLK 停在高电平：MCU 死机、IWDG 还没动作，或者 TIM 停在高电平；
  - **MCU 失电**：PA8 随 VDD 缓慢下降，是 ms 级斜坡，经 C321 高通后几乎不产生边沿，效果等同于卡高。
  - MCU 复位时 PA8 变为高阻、R52 下拉。这是**瞬时边沿**：C321 两端的节点只有 pF 级对地电容，IN1 会立刻跳到约 −0.15V，所以复位是安全的，已核。
- **机理**：
  - 每一级的输入以 τk = R30k·C32k 独立衰减，到 VT− 时翻低。第 j 级先翻时，它的下降沿立即把 j..8 级全部带低，但 1..j−1 级仍为高。
  - 于是 CF(j−1) 一端是 X(j−1) = VB(j−2)（经 N 管），另一端是 Xj = VBj（经 P 管），**跨在两节上**，要从 V_cell 被充到 2V_cell。
  - 等上游某一级翻低时，CF(j−1) 又要从 2V_cell 放回单节。
- **窗口长度**：各级的翻转时间 t = τ·ln(V_hi / VT−)。
  - VT− 在 VCC = 3.0V 时为 0.89–1.20V，在 3.65V 时插值为 1.16–1.53V（LVC p.6）；C1523 的容差为 ±10%。
  - 算下来窗口最长约 **50µs**。规格书写的是 30µs。
- **浪涌**：
  - 回路电阻 R_on,N + R_on,P + ESR ≈ 0.08Ω，ΔV = 3.3V。P 管经 330Ω 约 0.3–1µs 进入强导通，电流先受 P 管饱和电流限制，AO3415A 在 −2.5V 时约 30A、−3V 时约 37A（QP p.4 Fig 1）。
  - 两节本地 CB 串联（有效约 25µF）先供电荷，时间常数 τ ≈ 0.08Ω × 20µF ≈ 1.6µs。
  - 峰值约 **20–40A**，超过 AO3415A 的 **IDM 15.6A**（QP p.2），也接近 AO3416 的 IDM 30A（QN p.1）。每次事件的能量约 ½·C·ΔV² ≈ 0.5mJ，进入和退出各一次。
  - **本地电源**：进入时相邻两节的本地轨共下陷约 2.6V（CB 与 CF 电荷分享：3.3 × 100/125）。退出时 CF 以约 6.6V 对单节 CB 放电，本节轨瞬时冲到约 (100 × 6.6 + 50 × 3.3) / 150 ≈ **5.5V**。这个值没超过 LVC 的绝对最大值 7V，但已顶到推荐上限 5.5V（LVC p.4、p.5）。
  - 此外 CF 在窗口内承受 6.6–7.3V，高于额定 6.3V。
- **判定**：单次大概率不会损坏，但属于「超出手册额定」的重复性应力。每次死机或非正常掉电都会发生一次，与规格书 §1.4(b)「可以接受的瞬态」的定性不符。
- **建议（只改阻值，不改拓扑）**：**让第 1 级永远最先衰减**。第 1 级一翻低，它的下降沿会在 ns 级内把 2..8 级同步带低，混相就被消除了。
  - **推荐**：R302–R308 由 100k 改为 **330k**，R301 保持 100k。
    - 第 1 级最晚翻转时间：110µs × ln(3.0 / 0.89) ≈ **133µs**。
    - 其余各级最早翻转时间：297µs × ln(2.7 / 1.53) ≈ **169µs**，余量足够。
    - 330k 的漏电偏移：±1µA × 330k = ±0.33V，仍低于 VT−,min 0.89V。
    - 下垂变小，对阈值余量更有利。
    - 需要取 330k 0402 的料（嘉立创 C 编号用 `jlc_api.py` 查，不要凭记忆写）。
  - **备选**：R301 改为 33–39k，或 C321 改为 330pF，但这样 75kHz 下第 1 级的下垂会增大到约 18%。第 1 节为 3.65V 时，高电平约 2.4V，VT+,max 约 2.28V，余量只剩约 0.1V，而且把时钟下限抬到约 60kHz，**不推荐**。
  - 固件 X-5 的第 ② 条（停时钟停在低电平）仍然要做（见 P2-6）。

---

## P2

1. **P2-1　U301–U308 的手册自相矛盾（C7394021 UMW）**：p.2「Pin Function」表写 SOT23-5 为 **4 = VCC、5 = OUT**，DFN6 表也把 VCC 和 OUT 对调了。p.1 Figure 1 的引脚图写的是 **4 = OUTY、5 = VCC**。
   - 原理图与嵌入符号取 4 = OUTY、5 = VCC，与 p.1 图、TI 原版 DBV 封装以及嘉立创符号一致，**判定原理图正确**。p.2 表格应是手册的笔误。
   - 建议写进知识库，样板到货后用万用表的二极管档核对一颗（VCC 与 GND 之间有 ESD 结构）。
2. **P2-2　IN1 正向瞬态没有钳位**：规格书 §1.4(c) 只核了 VB0 与 GND 之间的**负向**地电位瞬变（IIK −50mA，LVC p.4）。
   - 74LVC 输入端**没有到 VCC 的钳位二极管**，VI 的绝对最大值是 7V，与 VCC 无关（p.4）。GND 相对 VB0 的正向瞬变（短路关断时的 L·di/dt，规格书自己估的是「几伏到几十伏」）会经 C321 几乎原样加到 IN1 上，只由 R300 1k 限流。
   - 建议评估：给 IN1 加一只到 VB1 的低 Cj 肖特基（A = IN1，K = VB1），正常工作时高电平约 3.0V，低于 VB1 + Vf，不会导通；或者给 R300 留一个可调位。
   - k ≥ 2 的各级没有这个问题：它们的节点 dv/dt 受 100µF 的 CB 限制，而且 LVC 有 Ioff 部分掉电保护（p.7，IOFF ≤ 10µA）。
3. **P2-3　级间传播延迟带来的「跨级重叠」没有计入**：DRVk 带着约 1.8nF 的栅极负载（经二极管），边沿约 45ns，经 C32(k+1) 到下一级约有 40ns 延迟。
   - 上升沿时，Q30k 开始导通，而 Q31(k+1) 还没关断，CFk 会短暂跨接两节。下降沿时，Q31k 已经开通，而 Q30(k+1) 还没关断，CFk 会被短接。
   - 这部分电流同样受「开通管刚过阈值」限制，量级估计在 mA 到 A 之间，与 P1-1 叠加。
   - 建议列入 §8.3 样板实测：同时测相邻两级的 DRV 和 CFk 电流探头波形。
4. **P2-4　原理图可读性（PDF 第 4 页目视）**：
   - C301–C308 的位号「C30k」与 `VBk` 标签文字、值「100nF 16V」互相重叠（每节都有）；
   - Q311–Q318 的 P 管符号镜像后，「AO3415A」「Q31k」两段文字倒置显示；
   - 标题栏为 Rev `v0.3-draw-r1a`、Date 2026-09-26，与快照 r1 和实际日期不一致。
   - 均属规则 00 ③，不影响网表。
5. **P2-5　手册缺件**：任务书列出的 1N5819WS（C191023）手册**不在 `datasheets/`**，本次是下载到 scratchpad 核的：SOD-323，带色环的一端是负极，与封装丝印的阴极条在焊盘 1 一侧一致。建议主代理用 `tools/fetch_datasheets.py C191023` 补进来。
6. **P2-6　硬件的安全态依赖固件 X-5 ②③，而固件没有实现**：`firmware/src` 里只有 `bal_clk` 逻辑标志，没有 TIM1/PA8 的空闲电平配置。规格书已列为 X-5（P1、固件），这里只提醒：P1-2 改完后仍要保证「停时钟停在低电平」。
7. **P2-7　均衡电流口径 0.16A@100mV 复核**：
   - 独立重推 6·R_w：边线各 I，中线 2I，折算为 ΔV' = ΔV − I(R + 4R + R)，✅。
   - R_FSL = 4·(R_N + R_P + ESR)：每相两只同型管，占空比 50%，按 Σ a²R/D 推导一致 ✅。
   - 我另外做了时域仿真：两节，CB 为 50µF 有效，CF 为 100µF 有效，R_w 45mΩ，N/P 为 20/42mΩ，75kHz。结果 **I ≈ 0.164A @ 100mV**，与公式的 0.159A 吻合，公式略偏保守。
   - 前提提醒：这是「单独一对相邻节」的口径。8 节同时工作时，各 CF 通过共用的半桥耦合，单个高节会同时向两侧放电，此时的电流不能直接套这个口径。C_eff = 100µF 仍待样板实测。
8. **P2-8　既有 P2 确认**（规格书已列，这里只确认数值）：
   - 74LVC 关断方向的峰值电流 0.1–0.19A，超过 IO ±50mA 和 ICC ±100mA 这两个直流绝对最大值（LVC p.4），瞬态属于常见用法，样板看温升。
   - BAL_3A 的 1.2mm 线宽对 SOT-23 焊盘偏宽，布局时再建 0.6mm 的类。
   - J6 定位柱是环宽为 0 的 PTH。

---

## 覆盖清单

| 项 | 结果 | 依据 |
|---|---|---|
| ⓪ 断线 / 死头 / 悬空 | ✅ 本页 ERC 0 条：快照 `erc.json`，以及我在 `hardware/` 下重跑 `kicad-cli sch erc`，`/开关电容主动均衡/` 都是 0；根页 6 条 `isolated_pin_label` 属 01/02 页的契约，与本页无关。局部标签没有只出现一次的；NC 共 9 处（U30x.1 ×8、J6.10） | netlist、erc |
| ⓪b 同网多名 | ✅ 每个网络只有一个名字；本页**没有 GND、没有电源符号、没有 CELL\***；全局标签只有 BAL0–8 和 BAL_CLK | netlist，sch 标签统计 |
| 器件数 / 位号 / LCSC | ✅ 113 个，与 §2.2 和 `docs/02-BOM.csv` 第 49–60、99 行逐项一致（C 编号、封装、数量） | netlist 对 BOM |
| 逐节 k = 1..8：UDk 的 VCC/GND | ✅ U30k.5 = VBk，.3 = VB(k−1)；.2 = INk，.4 = DRVk | 程序比对，LVC p.1 Fig 1 |
| 半桥 S/D/G | ✅ Q30k：G = GNk，S = VB(k−1)，D = Xk；Q31k：G = GPk，S = VBk，D = Xk。没有接反，体二极管不会短路本节 | QN p.1 图、QP p.1 Table-2 |
| 死区网络方向 | ✅ D30k：K = DRV，A = GN（N 管经二极管快关，经 R 慢开）；D31k：A = DRV，K = GP（P 管经二极管快关，经 R 慢开）。极性正确，但结电容问题见 **P1-1** | netlist、1N5819WS 手册 p.1 |
| 输入耦合与 100k 下拉 | ✅ C321：CLK_R → IN1；C32k：DRV(k−1) → INk；R30k：INk → VB(k−1) | netlist |
| 飞电容 Xk–X(k+1) | ✅ C33k ∥ C34k，k = 1..7；X1 和 X8 各只接一端 | netlist |
| 本地储能与去耦跨本节 | ✅ C30k、C31k 都跨 VBk 与 VB(k−1) | netlist |
| 时钟链与各种状态 | 停时钟（停在低电平）✅；MCU 复位（PA8 高阻 + R52，netlist 确认 R52 接在 BAL_CLK 与 GND 之间）✅，是瞬时边沿；上电 ✅（输入经 100k 为 0，全低）；**时钟卡高 / MCU 失电 → P1-2**。飞电容稳态只承受一节（≤ 3.65V）✅，混相窗口内为 6.6–7.3V，超过 6.3V（P1-2） | LVC p.6–7 |
| Rds / 电流 / 耐压 | Vgs 2.5V：AO3416 ≤ 26mΩ（p.2），AO3415A ≤ 47mΩ（p.3），125°C 约 ×1.45–1.5（QN Fig 8、QP Fig 4）✅。300mV 时正常相峰值约 2–3.4A，低于 ID 4.9/6A ✅。每管 Vds、Vgs ≤ 一节（热插拔 ≤ 4.4V），额定 20V、±10/±12V ✅。混相时超过 IDM（P1-2） | QN、QP |
| 直通与死区 | 规格书的单节估算方法可以，但 Cj 前提有误（P1-1），跨级重叠没有计入（P2-3） | — |
| J6 焊盘 | ✅ 焊盘 n ↔ BAL(n−1)，焊盘 10 为 NC。实测封装坐标：1 为 (−6, −1.5) 方焊盘……9 为 (6, −1.5)，10 为 (6, +1.5)；孔径 1.02 与手册 ⌀1.02 一致；定位柱偏 3.00 / 0.94 与手册 P.C.B LAYOUT 一致 | `CONN-TH_XDWF-C3030WV-2-5P.kicad_mod`，C18202166 |
| F300–F308 | ✅ F30k.1 = BALk，.2 = VBk（k = 0..8）；3A、23mΩ、32V/50A、I²t 0.933（FUSE p.3、p.12） | netlist、FUSE |
| 网络类 | ✅ netlist 里 X1–X8、VB0–VB8、BAL0–8 都属 BAL_3A；BAL_CLK 为 Default（`BAL?` 不匹配） | netlist 的 class 字段，`.kicad_pro` |
| 0.16A 口径 | ✅ 算式与前提已复推，并做了时域仿真（P2-7） | `tools/bms_calc.py` 第 115 行 |
| ① 电容完备性 | ✅ 每颗 U 一只 100nF；每节一只 100µF；飞电容 7 级 × 2 | — |
| ② 封装下探 | ✅ 同意规格书 §7.3。P1-1 换料不动封装 | — |
| ③ 可读性 | P2-4 | PDF 第 4 页 |
| 嵌入符号对库 | ✅ 12 个符号的引脚号、名称与 `jlc.kicad_sym` 逐一一致；Footprint、LCSC 字段一致 | 程序比对 |
| 规格书本身的质疑 | P1-1（Cj 前提）、P1-2（混相定性）、P2-2（只核了负向瞬态）、P2-1（UMW 手册矛盾没有指出）、P2-7（口径适用范围） | — |

### 交主代理 / 知识库（复核方没有写入）

- 「R-D 死区网络里，二极管的 Cj 与栅极 Ciss 分压会把阶跃直接踢到栅极上，要用低 Cj 的二极管（≤ 10pF）」
- 「交流耦合链上，第 1 级的 τ 必须明显小于其余各级，这样时钟卡高或掉电时各级才会同步回到安全态」
- 「UMW 版 74LVC1G17 手册 p.2 的引脚表把 VCC 和 OUT 写反了，以 p.1 图为准」

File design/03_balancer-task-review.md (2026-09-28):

# 独立复核任务书：子图 03_balancer（开关电容主动均衡）

你是**复核方**（与画图方 DeepSeek 不同厂商）。只读不改工程文件；报告写到本任务指定的文件（**必须落盘，开工先建报告骨架、边查边写**）。
工作目录 `/home/user/MP2645A-BMS`，全部中文。**KiCad 封装与原理图坐标 y 轴向下**（y 为正 = 下方）。

## 纪律
- **不要读**画图方报告（`design/03_balancer-draw-report.md`、`*-draw-*.out`）与生成/自检脚本注释；独立重推。
- 输入：快照 `review/03-r1/`（`03_balancer.kicad_sch`、`erc.json`、`netlist.xml`、`sch.pdf`：03 页在 PDF 第 4 页）、
  规格书 `design/03_balancer-spec.md`（**它本身也要被质疑**，含 §8.1b 用户决定：死区网络、只接 100k 下拉、首级交流耦合 VB0 不接 GND、每节 100µF 本地储能、线束保险丝暂不加=已知风险、BAL 保险丝保持 C163126 1206）、
  `docs/03-详细设计.md` 第 1、2.4、4 节、`docs/02-BOM.csv` 均衡段、手册（AO3416 C479060、AO3415A C5350990、74LVC1G17 C7394021、1N5819WS C191023、C15008、C163126、C18202166 J6 等，在 `datasheets/`）、05 页 BAL_CLK 源（`hardware/05_mcu_comm.kicad_sch`：PA8 + R52 100k 下拉）。
- 可自己跑 `kicad-cli`（在 `hardware/` 下对 `mp2645a-bms.kicad_sch`，输出写 /tmp）。
- 核约束要问「串在哪、并在哪、电流走哪条路」，算最坏工况；推导链上游前提也要核。

## 必查
- ⓪ 断线/死头/悬空；⓪b 同网多名；本页无 GND、无 CELL* 网络。
- 逐节（k=1..8）推一遍：UDk 的 VCC/GND 接哪两个节点；半桥 QN/QP 的 S/D/G；死区网络方向（慢开快关，二极管极性、谁开谁关）；输入耦合电容与 100k 下拉；飞电容 Xk–X(k+1)；本地储能与去耦跨本节。
- 时钟链：BAL_CLK → R300/C321 → 第 1 级 → 逐级耦合；**停时钟、MCU 复位（PA8 高阻 + R52）、上电、时钟卡高**时各级最终状态，飞电容最大承受电压是否 ≤ 6.3V。
- 每管 Vgs 在 2.5–3.65V 驱动下的导通电阻与电流能力；直通与死区估算；器件耐压（每管只承受一节）。
- J6（C18202166）焊盘 n ↔ BAL(n−1)、焊盘 10 空；按封装焊盘实测坐标核；F300–F308 各接对应 BAL 节点。
- 网络类：网表里 `Xk`、`VBk`、`BALk` 是否属 BAL_3A（`hardware/mp2645a-bms.kicad_pro`）。
- 均衡电流 0.16A@100mV 口径（`tools/bms_calc.py sc_equalizer`）的前提与算式。
- ① 电容完备性、② 封装下探、③ 可读性（目视 PDF 第 4 页）；LCSC 与 BOM 一致。

## 输出
`P0 / P1 / P2`，每条：位号 + 引脚/网络 + 依据（手册页码或算式）；附覆盖清单。时间不够按上面顺序，后面的写「未核」。

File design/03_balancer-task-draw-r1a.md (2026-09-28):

# 画图任务书：子图 03_balancer（开关电容主动均衡），第 1 轮 · 分段 A（共 3 段，每段限时 30 分钟）

你是**画图方**。工作目录 `/home/user/MP2645A-BMS`，全部中文。画 `hardware/03_balancer.kicad_sch`。
**设计依据：规格书 `design/03_balancer-spec.md`（含 §8.1b 用户决定，附录 A 已作废），逐条照画。**

## 0. 纪律（与 02/04/05 页相同，先读样板）
- 样板：`hardware/gen/gen_02_afe.py` 与 `hardware/gen/check_02_layout.py`（13 项自检：几何、跨器件不相交、PDF 原始文字 span 不重叠、网表逐脚核对规格书、标签压引脚/叠标签/字段离位/越框），
  以及 `design/02_afe-task-draw-r1a.md`（纪律全文）。**先读这三个文件**，照它们写 `hardware/gen/gen_03_balancer.py` 与 `hardware/gen/check_03_layout.py`
  （可复制 02 的通用函数；**不许改 02/04/05 的生成器与产物**）。
- 器件只用 `hardware/lib/jlc/jlc.kicad_sym` 的符号（原样复制，顶层名改 `jlc:NAME`）；实例带 Reference/Value/Footprint/Datasheet/LCSC；位号用规格书的 3xx 段（纯数字结尾）。
- 层次路径：根图 uuid `632f74a5-cd8f-58d8-9ac1-1bfbb611d555`，03 页 sheet uuid 从 `hardware/mp2645a-bms.kicad_sch` 里 `Sheetfile "03_balancer.kicad_sch"` 的 sheet 取；03 页文件自身 uuid 保持现值。
- 只改：`hardware/03_balancer.kicad_sch`、`hardware/gen/gen_03_balancer.py`、`hardware/gen/check_03_layout.py`、报告 `design/03_balancer-draw-report.md`（以及知识库写回）。不改库/BOM/docs/根图/其它子图；不跑 `tools/gen_kicad_skeleton.py`、git。
- KiCad 坐标 y 轴向下；端点落 1.27mm 栅格；导线不穿本体、不经过非端点引脚；T 接点放 junction；局部网络名严格照规格书（`VBk`、`Xk`、`DRVk`、`GNk`、`GPk`、`INk`、`CLK_R` 等），网络类要能匹配 `/开关电容主动均衡/X?`、`/开关电容主动均衡/VB?`。
- 接口全局标签：`BAL0..BAL8`、`BAL_CLK`（**本页不用 GND**）。

## 本段（A）要做
1. 生成器框架与自检脚本（从 02 移植，网表逐脚核对表按规格书 §3.2 的 60 个网络写）。
2. 画**第 1–4 节**（k=1..4）的全部器件：半桥 QN/QP、U30k、去耦 C30k、储能 C31k、耦合 C32k、下拉 R30k、死区 R31k/R32k + D30k/D31k、飞电容（k=1..3 的 C33k/C34k，以及跨到第 4 节的一级），以及首级时钟输入（R300、C321、`CLK_R`）。
   版面按规格书 §7 的建议（A3 分两栏，自下而上）预留第 5–8 节位置。
3. 跑 ERC 与自检到已画部分干净；未画部分的标签单脚告警列明。报告写「分段 A 完成情况」与留给 B/C 的清单。

最后一行回复 `DONE`。

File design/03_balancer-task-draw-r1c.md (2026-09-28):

# 画图任务书：03_balancer 第 1 轮 · 分段 C（限时 30 分钟，收尾）

工作目录 `/home/user/MP2645A-BMS`。纪律与依据同 `design/03_balancer-task-draw-r1a.md`。
**先读报告里给 C 的清单，先跑生成器确认幂等**再改。

## 本段（C）要做
1. 标题「开关电容主动均衡（8 级半桥 + 飞电容，75kHz）」与说明文字（死区、全级交流耦合、停时钟收敛到全低、线束保险丝未加为用户决定的已知风险）放左上角；全页无重叠、无越界。
2. **全页验收**：自检全过（逐脚核对覆盖全部器件，规格书 §3.2 的 60 个网络逐一核对）；ERC 本页 0 条，跨页单脚只允许 `BAL0..8`（J6 为唯一来源时应已多脚）；
   网表每个器件 Footprint/LCSC 非空；网络类核对：`Xk`、`VBk` 在网表里属 BAL_3A；本页无 GND、无 CELL* 网络；规格书 §7 自检清单逐条打勾；PDF 渲 PNG 目视；幂等。
3. 跑 `python3 -m unittest discover -s tests` 与 `make -C firmware test`。
4. 报告追加「分段 C / 第 1 轮完成」：位号总表（新 ↔ BOM）、外围点名、逐节核对结论、自检结果、建议。

最后一行回复 `DONE`。

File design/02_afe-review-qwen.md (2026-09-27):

# 02_afe（MP2797 AFE）第二复核报告 · review2（阿里云 qwen3.8-27b）

> 时间戳：2026-09-27 17:38 JST 开工；**报告完成 2026-09-27 19:1x JST**（逐条以 `TZ=Asia/Tokyo date` 实查为准）
> 纪律：独立重推；未读画图方报告（`02_afe-draw-report.md`、`*-draw-*.out`）与生成/自检脚本注释。
> 输入：快照 `review/02-r1/`（02_afe.kicad_sch / erc.json / netlist.xml / sch.pdf 第 3 页）、
> `design/02_afe-spec.md`（含 §12.1b 用户决定，本身被质疑）、`docs/03-详细设计.md` §1–3（已读）、
> `docs/02-BOM.csv` AFE 段、手册 `datasheets/C18198873_MPS_MP2797DFP-0000-T.pdf`（Fig 26/27/28、Table 18/22/23、p.6–7 引脚表、电气特性）、
> `datasheets/C19626224_Tokmas_IPT012N08N5_TOKMAS.pdf`（Ciss/Qg/VGS 绝限）。
> 坐标系：KiCad 封装与原理图 y 轴向下（y 为正 = 下方）。
>
> **快照取证**：复核对象 = `review/02-r1/02_afe.kicad_sch`，MD5 `2edd200d19fc3adc0ca4ba8d5560984f`（与任务指定一致）；
> 当前 `hardware/02_afe.kicad_sch` 已前进到 02-r2（MD5 `3ee64cc3bd6982abc188506395bb2604`）。
> J5 实例两树逐字一致；本报告 P2-12 / P2-13 两条 r1 缺陷已在 r2 树修复（本复核方对 r2 树做过抽查确认）。

## 0. 结论速览

| 级别 | 数量 | 摘要 |
|---|---|---|
| **P0** | **0** | 无致命缺陷：48 脚全对、无极性反接、无断线、J5 正确、跨页接口齐备 |
| **P1** | **1** | CVCP/ΣCiss 双依据矛盾：87nF（手册条件，→C219 100nF 合规）vs BOM 注释"Qg 等效 144nF"（超 Table 22 最大行）；若 144nF 为真则 100nF 不足 → **样板实测 VCP 跌落后再定**（C226 DNP 100nF 为预留对冲） |
| **P2** | **14** | 见 §12 清单（1 条已修复类：r1 可读性 2 处；1 条已修复类：C209-211 Value 字段；余 11 条为注记/样板验证项） |

一句话结论：**02-r1 快照电路拓扑与全部 48 个 MP2797 引脚接法正确，无 P0；唯一 P1 是 CVCP 取值的双依据矛盾，需样板实测裁决；其余为文档/降额/命名类 P2。**
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

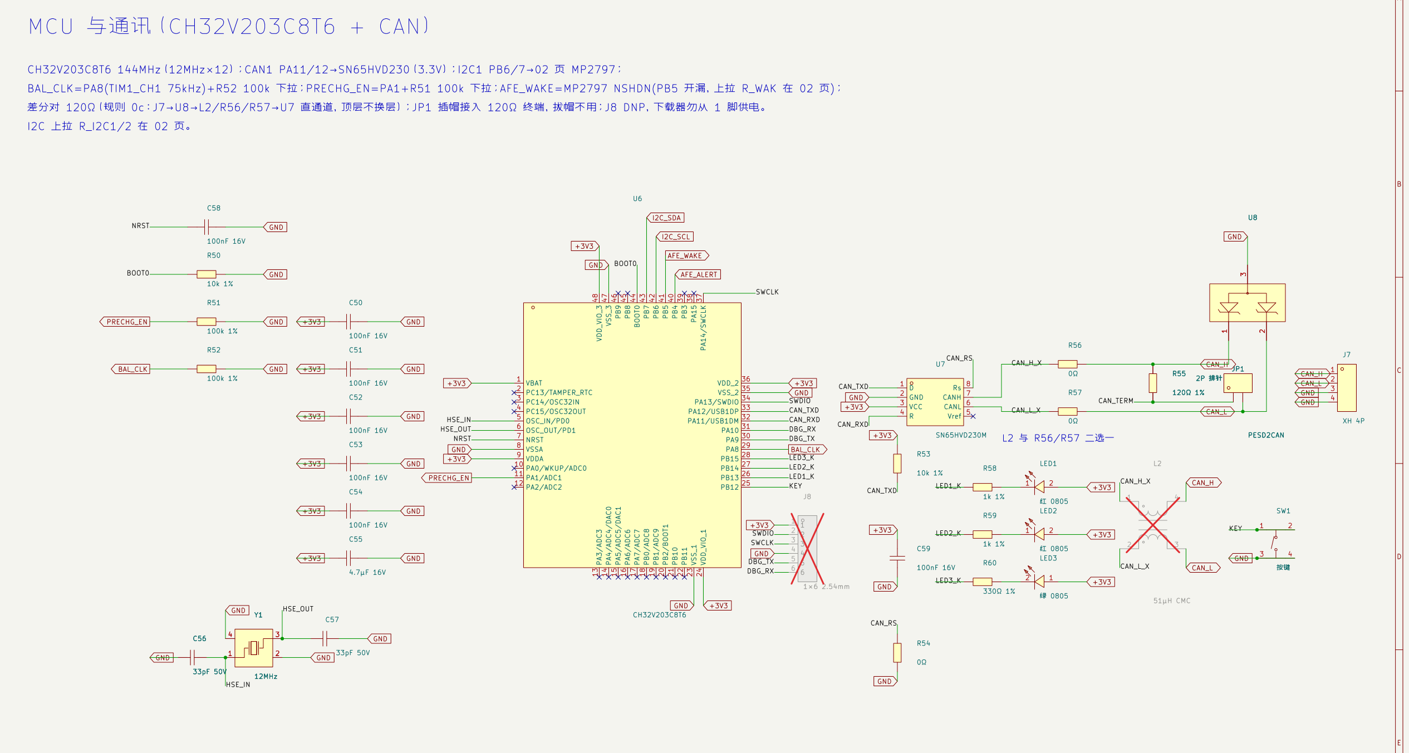
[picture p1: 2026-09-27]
design/05_mcu_comm.png

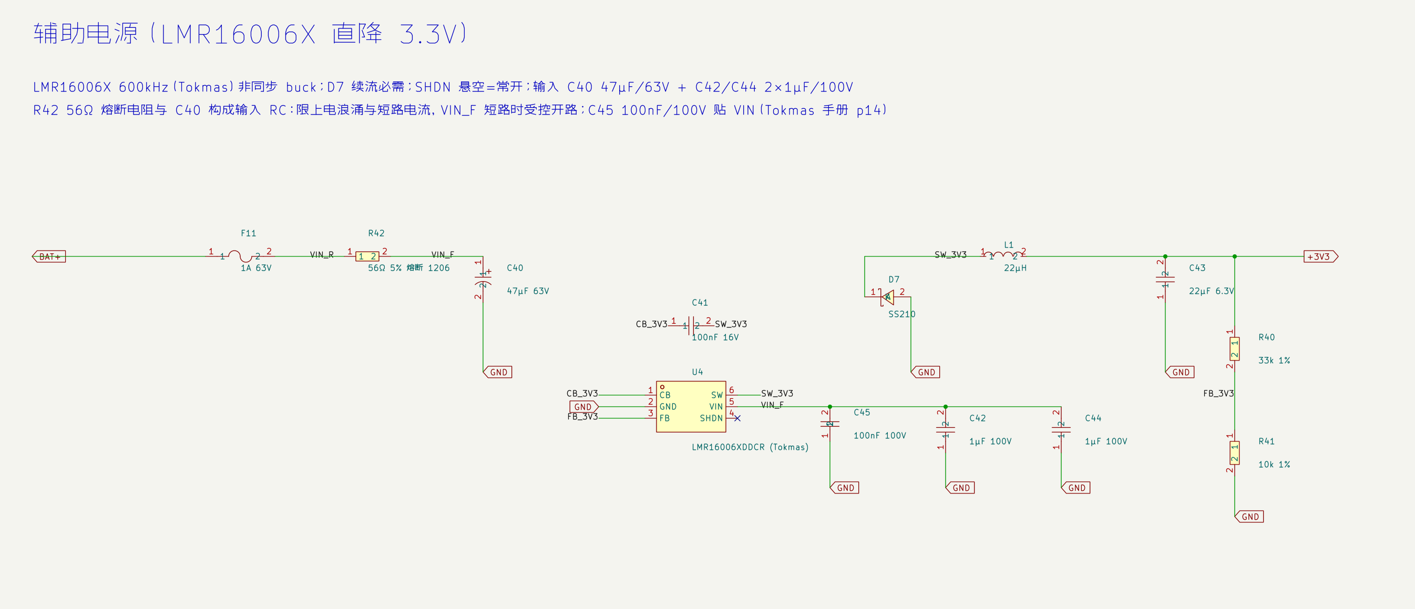
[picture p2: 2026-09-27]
design/04_power_supply.png

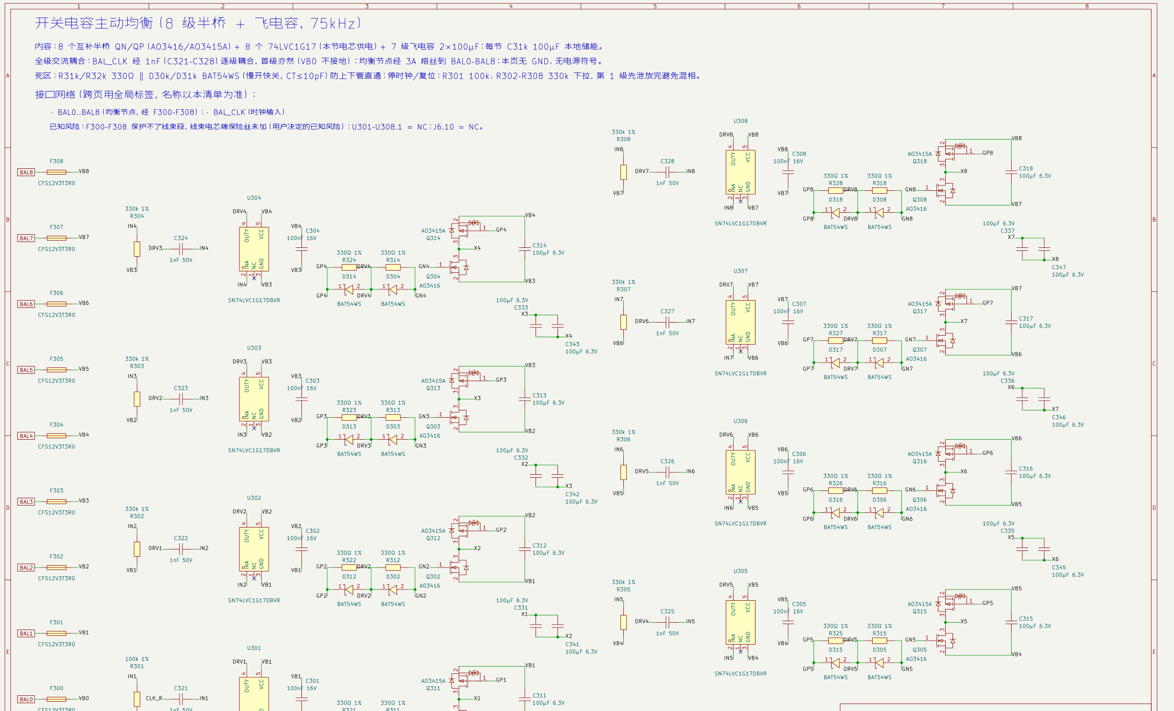
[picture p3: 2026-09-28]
design/03_balancer.png

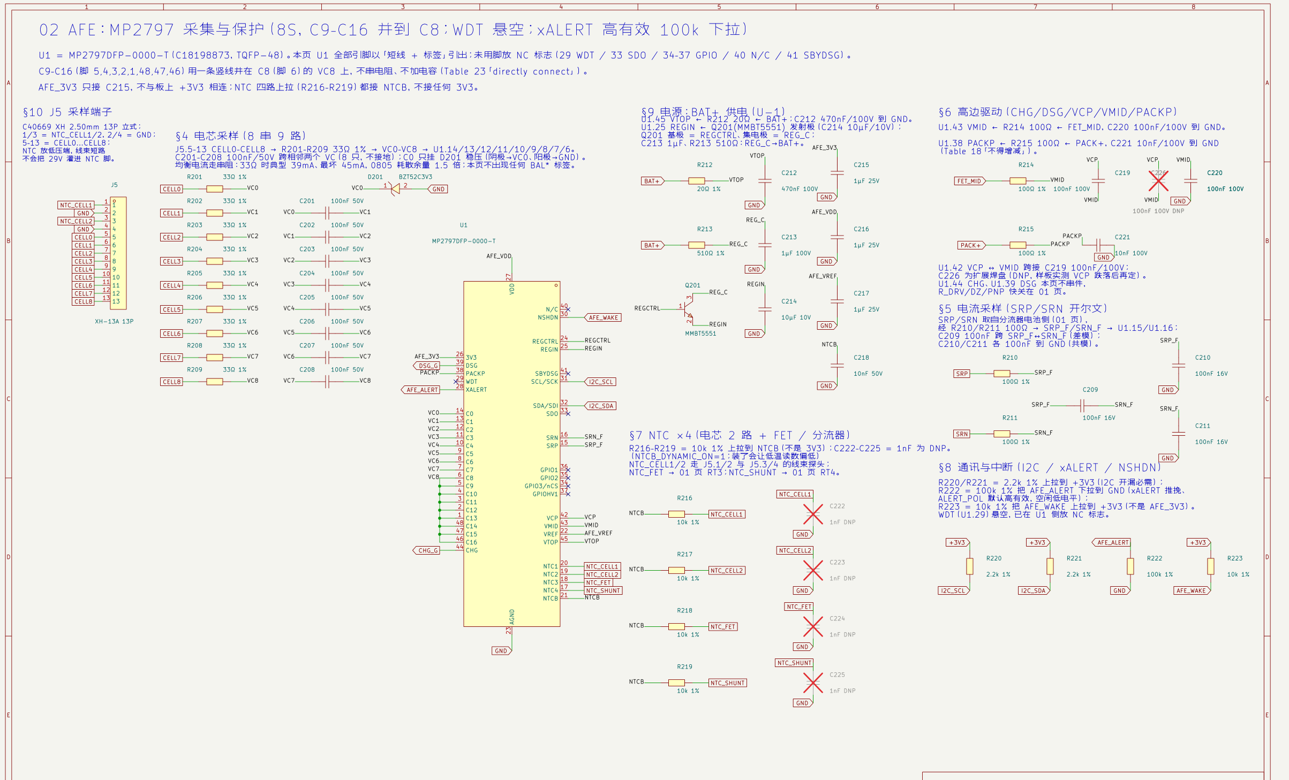
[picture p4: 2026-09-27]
design/02_afe.png

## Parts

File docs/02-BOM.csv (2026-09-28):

模块 | 位号 | 数量 | 器件 | 制造商型号 | 立创编号 | 封装 | 规格 | 来源 | 备注
功率 | Q1-Q12 | 12 | N-MOSFET | Tokmas IPT012N08N5(TOKMAS) | C19626224 | TOLL | 85V 300A 0.9/1.2mΩ Qg240nC Tj150 | JLC | CHG×6+DSG×6（降本）；用户 2026-09-27：改为 MP2797 手册共漏拓扑（Fig 26/27）：Q7–Q12 CHG 组在电池侧（S 朝 BAT+，D 朝 FET_MID），Q1–Q6 DSG 组在 PACK 侧（D 朝 FET_MID，S 朝 PACK+）；FET_MID=漏极公共点。01 页画图时按此编号
功率 | RG1-RG12 | 12 | 栅极电阻（手册 RMG） | UNI-ROYAL 0402WGF1000TCE | C25076 | 0402 | 100Ω 1% | JLC | 手册 RMG 100Ω Required；原 10Ω
功率 | R_PUP1 R_PUP2 | 2 | 栅极 G-S 电阻（手册 RCHG_PUP/RDSG_PUP） | UNI-ROYAL 0603WAF1005T5E | C7250 | 0603 | 10MΩ 1% | JLC | 手册 Table 18 补全（用户 2026-09-26 同意）；取代 RGS1–12 100k×12（每组 16.7k 与驱动导通电阻 2.6kΩ 分压会把 Vgs 拉低约 14%）；用户 2026-09-27：共漏拓扑参考点：R_PUP1 接 CHG 栅极母线↔CHG 源极（BAT+ 侧），R_PUP2 接 DSG 栅极母线↔PACK+
功率 | DZ1 DZ2 | 2 | 栅极钳位稳压管 | MM3Z15 | C65676 | SOD-323 | 15V | JLC | 用户 2026-09-27：共漏：DZ1 阴极接 CHG 栅极母线、阳极接 CHG 源极（BAT+ 侧）；DZ2 同理接 DSG 栅极母线↔PACK+
功率 | Q17 Q18 | 2 | PNP快关 | CJ SS8550 Y2 | C8542 | SOT-23 | PNP -25V -1.5A | JLC | 降本推荐项；基础库；用户 2026-09-27：共漏：Q17 E→CHG 栅极母线、C→CHG 源极（BAT+ 侧）；Q18 E→DSG 栅极母线、C→PACK+
功率 | D4 D5 | 2 | 驱动隔离肖特基 | 1N5819WS | C191023 | SOD-323 | 40V 1A 肖特基 | JLC | 降本推荐项；基础库；用户 2026-09-27：R_DRV1/2 与 D4/D5 布局时靠近 U1 的 44/39 脚
功率 | RQB1 RQB2 | 2 | PNP基极电阻 | UNI-ROYAL 0402WGF1001TCE | C11702 | 0402 | 1k 1% | JLC | 位号由 RB1/RB2 改名，避免与均衡 RB1–15 重号
功率 | RS1 | 1 | 分流器 | 业展 ASR-S-7-0.1F | C6075508 | 5930 | 0.1mΩ 1% 15W TCR±200ppm | JLC | 降本推荐项（2026-09-26 采用）；2 端子 焊盘切分开尔文；用户 2026-09-27：SRP 取电池侧（=GND 单点，Net-Tie），SRN 取 PACK− 侧（手册 Fig 26）
功率 | D1 D2 D3 | 3 | TVS | DOWO SMDJ33A | C2976503 | SMC | 3000W Vrwm33V | JLC | 第 1 轮可选项（用户 2026-09-26 14:46 采用）：参数同晶导微 C438163；库存 725（够 240 块）
功率 | C1-C6 | 6 | MLCC | CCTC TCC1206X7R105K101HT | C282823 | 1206 | 1µF 100V X7R | JLC | 第 1 轮可选项（用户 2026-09-26 14:46 采用）：14→6 颗（PACK 侧 4、BAT 侧 2）；**短路关断实测必须确认 PACK+ 峰值 < 64V**，超了补回；用户 2026-09-27：另加 C_PACK_E 47µF/63V 电解（手册 CPACK_E 典型 47µF）
功率 | Q19 | 1 | 预充P-MOS | Vishay SQ2361ES-T1_GE3 | C727403 | SOT-23 | -60V -2.8A | DNP | 可选预充
功率 | Q20 | 1 | 预充电平转换 | MMBT3904 | C20526 | SOT-23 | NPN 40V | DNP | 可选预充
功率 | DZ3 | 1 | PMOS栅极钳位 | BZT52C12S | C173449 | SOD-323 | 12V | DNP | 可选预充
功率 | RP1 RP2 | 2 | 预充电阻 | CCO CR-L5W-15RJ | C334293 | THT | 15Ω 5W | DNP | 可选预充
功率 | F1 | 1 | 主熔断器 | ANL/MEGA 300A |  | 螺栓 | 300A | 非嘉立创 | 线束侧件
功率 | BUS | 1 | 紫铜排+M8螺柱 | 20x2mm |  |  |  | 非嘉立创 | 机械件
功率 | HS | 1 | 铝散热器+导热垫 |  |  |  |  | 非嘉立创 | 机械件
功率 | C_PACK_E | 1 | PACK+ 电解（手册 CPACK_E） | jieerrui RV63V47M6X8 | C48971005 | SMD D6.3x7.7 | 47µF 63V 105℃ 2000h | JLC | 用户 2026-09-27：X-4 采用；Table 18 CPACK_E 典型 47µF/最大 200µF；PACK+→PACK−；与 04 页 C40 同料；01 页画图时再编号
功率 | RT3 RT4 | 2 | NTC（MOSFET / 分流器） | APV ANTC1608-103F3380FB | C52155402 | 0603 | 10k B25/50=3380 | JLC | 用户 2026-09-27：由 AFE 段 RT1–RT4 拆出，画在 01 页；RT3→NTC_FET 贴 MOSFET，RT4→NTC_SHUNT 贴 RS1，另一端接 GND；上拉 R218/R219 在 02 页
AFE | U1 | 1 | AFE | MPS MP2797DFP-0000-T | C18198873 | TQFP-48 | 7~16S 监测保护 | JLC | 用户 2026-09-27：逐脚分配见 design/02_afe-spec.md §1.3；C9–C16 并到 C8（Table 23）；WDT/SDO/GPIO1–3/GPIOHV1/SBYDSG/N/C 悬空
AFE | R201-R209 | 9 | 电芯采样串阻（RCELL_FLT） | UNI-ROYAL 0805W8F330JT5E | C17634 | 0805 | 33Ω 1% 125mW | JLC | 用户 2026-09-27：原 R_CELL1–9；R201=CELL0…R209=CELL8；被动均衡流经串阻（Fig 28，情况 B），最坏 45mA/67mW，0805 在 85°C 余量 1.5×
AFE | C201-C208 | 8 | 电芯采样电容（CCELL_FLT，相邻 VC 间阶梯） | Samsung CL05B104KB54PNC | C307331 | 0402 | 100nF 50V X7R | JLC | 用户 2026-09-27：原 C_CELL1–9（9 只错，8S 为 8 只）；0603 C14663 → 0402 C307331 基础库
AFE | D201 | 1 | AGND-C0 钳位（DAGND-C0） | 晶导微 BZT52C3V3 | C353528 | SOD-123 | 3.3V 500mW | JLC | 用户 2026-09-27：原 D_C0；K→VC0，A→GND；扩展库
AFE | R210 R211 | 2 | 电流采样串阻（RSRP/RSRN_FLT） | UNI-ROYAL 0402WGF1000TCE | C25076 | 0402 | 100Ω 1% | JLC | 用户 2026-09-27：原 R_SNS1/2；R210←SRP（分流器电池侧），R211←SRN（PACK− 侧）
AFE | C209 | 1 | SRP/SRN 差模（CSRN_SRP） | Samsung CL05B104KO5NNNC | C1525 | 0402 | 100nF 16V X7R | JLC | 用户 2026-09-27：原 C_SNSD；0603 C14663 → 0402 C1525（SRP/SRN ≤6V）
AFE | C210 C211 | 2 | SRP/SRN 对地（CSRP_GND/CSRN_GND） | Samsung CL05B104KO5NNNC | C1525 | 0402 | 100nF 16V X7R | JLC | 用户 2026-09-27：原 C_SNSC1/2；0603 C14663 → 0402 C1525
AFE | R212 | 1 | VTOP 滤波电阻（RVTOP_FLT） | UNI-ROYAL 0603WAF200JT5E | C22950 | 0603 | 20Ω | JLC | 用户 2026-09-27：原 R_VTOP；上端接 BAT+（02 页契约加 BAT+）
AFE | C212 | 1 | VTOP 滤波电容（CVTOP_FLT） | CCTC TCC0805X7R474K101FT | C5375914 | 0805 | 470nF 100V X7R | JLC | 用户 2026-09-27：原 C_VTOP；扩展库
AFE | R213 | 1 | NPN 集电极限流（RREG 500Ω） | UNI-ROYAL 0603WAF5100T5E | C23193 | 0603 | 510Ω | JLC | 用户 2026-09-27：原 R_REG；上端接 BAT+
AFE | C213 | 1 | NPN 集电极电容（CREG） | CCTC TCC1206X7R105K101HT | C282823 | 1206 | 1µF 100V X7R | JLC | 用户 2026-09-27：原 C_REG
AFE | Q201 | 1 | REGIN 外置 NPN（NPN_REGIN） | CJ MMBT5551 | C2145 | SOT-23 | NPN 160V 600mA 300mW | JLC | 用户 2026-09-27：原 Q_REG；1=B→REGCTRL 2=E→REGIN 3=C；5mA 时 0.11W；样板实测 REGIN 电流 >5mA 换 BCX56 C24280
AFE | C214 | 1 | REGIN 电容（CREGIN 3.3µF Required） | Samsung CL10A106KP8NNNC | C19702 | 0603 | 10µF 10V X5R | JLC | 用户 2026-09-27：原 C_REGIN C19666 4.7µF（5V 偏压剩约 2.7µF <3.3µF）→ C19702（5V 下约 4.5µF）；基础库，已取库
AFE | C215 C216 | 2 | 3V3/VDD 旁路（C3V3、CVDD） | Samsung CL05A105KA5NQNC | C52923 | 0402 | 1µF 25V X5R | JLC | 用户 2026-09-27：原 C_LDO1/2；C215→3V3（局部 AFE_3V3，不接 +3V3），C216→VDD
AFE | C217 | 1 | VREF 旁路（CVREF） | Samsung CL05A105KA5NQNC | C52923 | 0402 | 1µF 25V X5R | JLC | 用户 2026-09-27：原 C_VREF；本版照原值（P2：可改 0603 C15849）
AFE | C218 | 1 | NTCB 旁路（CNTCB ≤10nF） | Samsung CL05B103KB5NNNC | C15195 | 0402 | 10nF 50V | JLC | 用户 2026-09-27：原 C_NTCB；本版照原值
AFE | C219 | 1 | VCP-VMID 电容（CVCP） | Samsung CL21B104KCFNNNE | C28233 | 0805 | 100nF 100V X7R | JLC | 用户 2026-09-27：原 C_VCP C14663 50V 0603（15V 偏压下可能 <ΣCiss 87nF）→ C28233；Table 22
AFE | C226 | 1 | VCP-VMID 扩展电容（预留） | Samsung CL21B104KCFNNNE | C28233 | 0805 | 100nF 100V X7R | DNP | 用户 2026-09-27：U-7 预留焊盘；Qg 等效 144nF 超 Table 22 范围，样板实测 VCP 跌落后再定
AFE | R214 | 1 | VMID 电阻（RVMID） | UNI-ROYAL 0402WGF1000TCE | C25076 | 0402 | 100Ω | JLC | 用户 2026-09-27：原 R_VMID；FET_MID（共漏=漏极公共点）→ VMID
AFE | C220 | 1 | VMID 旁路（CVMID） | Samsung CL21B104KCFNNNE | C28233 | 0805 | 100nF 100V X7R | JLC | 用户 2026-09-27：原 C_VMID
AFE | R215 | 1 | PACKP 滤波电阻（RPACK_FLT） | UNI-ROYAL 0402WGF1000TCE | C25076 | 0402 | 100Ω | JLC | 用户 2026-09-27：原 R_PACK；本版不做 PACK 反接保护（U-8）
AFE | C221 | 1 | PACKP 滤波电容（CPACK_FLT，不得增减） | CCTC TCC0603X7R103K101CT | C282516 | 0603 | 10nF 100V X7R | JLC | 用户 2026-09-27：原 C_PACK；扩展库
AFE | R216-R219 | 4 | NTC上拉（接 NTCB） | UNI-ROYAL 0402WGF1002TCE | C25744 | 0402 | 10k 1% | JLC | 用户 2026-09-27：原 R_NTC1–4；R216→NTC1(NTC_CELL1) R217→NTC2 R218→NTC3(NTC_FET) R219→NTC4(NTC_SHUNT)
AFE | C222-C225 | 4 | NTC滤波（预留） | 0402B102K500NT | C1523 | 0402 | 1nF 50V | DNP | 用户 2026-09-27：原 C_NTC1–4 100nF 删除（NTCB 动态偏置下 τ 0.5–0.9ms 建立不及）；默认 DNP，EMC 需要时贴 1nF
AFE | R220 R221 | 2 | I2C上拉（到 +3V3） | UNI-ROYAL 0402WGF2201TCE | C25879 | 0402 | 2.2k | JLC | 用户 2026-09-27：原 R_I2C1/2；R220→SCL R221→SDA
AFE | R222 | 1 | xALERT 下拉 | UNI-ROYAL 0402WGF1003TCE | C25741 | 0402 | 100k | JLC | 用户 2026-09-27：原 R_ALT；xALERT 推挽高有效；WDT 悬空、严禁上拉（p.24 拉高即复位）
AFE | R223 | 1 | NSHDN 上拉（到本板 +3V3） | UNI-ROYAL 0402WGF1002TCE | C25744 | 0402 | 10k | JLC | 用户 2026-09-27：原 R_WAK；不接 AFE 自身 3V3
AFE | RT_CELL1 RT_CELL2 | 2 | 电芯 NTC 线束探头 | 10kΩ B25/50=3380K 环氧/贴片探头（线束件） |  | 线束 | 10k 1% B3380 | 非嘉立创 | 用户 2026-09-27：U-2 取代板上 RT1/RT2（0603 在板上测不到电芯温度）；经 J5.1–4 双绞接入；B 值须与固件 R-T 表同口径
均衡 | Q301-Q308 | 8 | 半桥下管 N-MOS | PUOLOP AO3416 | C479060 | SOT-23 | 20V 6A 21typ/26max mΩ@2.5V Vth 0.45–1.0V | JLC | 用户 2026-09-27（design/03_balancer-spec.md）：原 QN1–QN8；S 接本节负极 VB(k−1)；第 1 轮可选项（用户 2026-09-26 14:46 采用）
均衡 | Q311-Q318 | 8 | 半桥上管 P-MOS | ElecSuper AO3415A | C5350990 | SOT-23 | -20V 4.9A 36typ/47max mΩ@-2.5V（曲线约 42mΩ@-3V） | JLC | 用户 2026-09-27（design/03_balancer-spec.md）：原 QP1–QP8；S 接本节正极 VBk；封装与 Q30x 不同（体宽 1.6）
均衡 | U301-U308 | 8 | 栅极驱动(施密特缓冲) | SN74LVC1G17DBVR(UMW) | C7394021 | SOT-23-5 | 1.65-5.5V 32mA | JLC | 用户 2026-09-27（design/03_balancer-spec.md）：原 UD1–UD8；本节电芯供电；输出经 R-D 死区网络分别驱动 N/P 栅极；1 脚 NC
均衡 | C301-C308 | 8 | 驱动去耦 | Samsung CL05B104KO5NNNC | C1525 | 0402 | 100nF 16V | JLC | 用户 2026-09-27（design/03_balancer-spec.md）：原 CD1–CD8；跨本节电芯 紧贴 U30k 5/3 脚
均衡 | C311-C318 | 8 | 每节本地储能 | Samsung CL31A107MQHNNNE | C15008 | 1206 | 100µF 6.3V X5R | JLC | 用户 2026-09-27（design/03_balancer-spec.md）：新增（U-4）；跨本节电芯 紧贴半桥两管源极；线束只流直流 抑制 ±1V 振铃 热插拔均压；基础库
均衡 | C321-C328 | 8 | 时钟耦合 | 0402B102K500NT | C1523 | 0402 | 1nF 50V | JLC | 用户 2026-09-27（design/03_balancer-spec.md）：C322–C328 原 CC2–CC8（DRV(k−1)→INk）；C321 新增（U-3）首级交流耦合 CLK_R→IN1
均衡 | C331-C337 C341-C347 | 14 | 飞电容 | Samsung CL31A107MQHNNNE | C15008 | 1206 | 100µF 6.3V X5R | JLC | 用户 2026-09-27（design/03_balancer-spec.md）：原 CF1–CF14（CF(2k−1)→C33k、CF(2k)→C34k）；每级 2 颗接 Xk–X(k+1)；BAL_CLK 75kHz；基础库
均衡 | R301 | 1 | 首级驱动输入下拉 | UNI-ROYAL 0402WGF1003TCE | C25741 | 0402 | 100k 1% | JLC | 用户 2026-09-28（03 Opus 复核 P1）：首级保持 100k，停时钟时最先翻低
均衡 | R302-R308 | 7 | 第 2–8 级驱动输入下拉 | UNI-ROYAL 0402WGF3303TCE | C25778 | 0402 | 330k 1% | JLC | 用户 2026-09-28（03 Opus 复核 P1）：100k→330k，时钟卡高/MCU 慢掉电时由第 1 级下降沿同步带低各级，消除约 50µs 混相；扩展库
均衡 | R311-R318 R321-R328 | 16 | 栅极慢开电阻 | UNI-ROYAL 0402WGF3300TCE | C25104 | 0402 | 330Ω 1% | JLC | 用户 2026-09-27（design/03_balancer-spec.md）：新增（U-1）；R31k DRVk→GNk、R32k DRVk→GPk；与 D30k/D31k 组成死区网络
均衡 | D301-D308 D311-D318 | 16 | 栅极快关肖特基（死区） | CJ BAT54WS L9 | C22629 | SOD-323 | 30V 200mA ≤10pF | JLC | 用户 2026-09-28（03 Opus 复核 P1）：1N5819WS 结电容约 110pF 会使死区失效 → BAT54WS；扩展库
均衡 | R300 | 1 | 时钟输入串阻 | UNI-ROYAL 0402WGF1001TCE | C11702 | 0402 | 1k | JLC | 用户 2026-09-27（design/03_balancer-spec.md）：原 R_CLK；BAL_CLK→CLK_R→C321
均衡 | F300-F308 | 9 | 均衡节点保险丝 | 大毅 TA-I CFS12V3T3R00 | C163126 | 1206 | 3A 32V 50A 快熔 冷阻 23mΩ −20~105℃ | JLC | 用户 2026-09-27（design/03_balancer-spec.md）：原 F2–F10（F30k 接 BALk）；只保护板上故障；线束电芯端保险丝用户决定暂不加（已知风险）；U-7 保持本料
电源 | U4 | 1 | Buck 3.3V | Tokmas LMR16006XDDCR | C54823941 | TSOT-23-6 | 4-60V(abs 65V) 1A 600kHz Iq80µA 非同步 VFB 0.770V | JLC | 第 2 轮降本（用户 2026-09-26 采用）（可选项）：TI C87080 引脚兼容替代；Iq 80µA（TI 28µA），待机 +50µA；33k/10k → 3.31V；EasyEDA 无 C54823941 的库，符号/封装沿用嘉立创 C87080（TI 同名件）的：引脚 1 BOOT/2 GND/3 FB/4 EN/5 VIN/6 SW 一致，封装尺寸 2.92×2.80、体宽 1.60、脚距 0.95 与 Tokmas 手册一致
电源 | D7 | 1 | 续流肖特基 | SS210 | C14996 | SMA | 100V 2A | JLC | 非同步必需；基础库
电源 | L1 | 1 | Buck电感 | Sunlord SWPA5040S220MT | C68434 | SMD 5x5 | 22µH 1.9A | JLC
电源 | C41 | 1 | Buck自举 | Samsung CL05B104KO5NNNC | C1525 | 0402 | 100nF | JLC
电源 | R40 | 1 | FB上 | UNI-ROYAL 0402WGF3302TCE | C25779 | 0402 | 33k 1% | JLC | Tokmas VFB 0.770×(1+33/10)=3.31V
电源 | R41 | 1 | FB下 | UNI-ROYAL 0402WGF1002TCE | C25744 | 0402 | 10k 1% | JLC
电源 | F11 | 1 | 输入保险丝 | JDT JFC1206-1100FS | C136343 | 1206 | 1A 63V 50A 快熔 | JLC | 第 2 轮降本（用户 2026-09-26 采用）（可选项）：冷阻约 0.49Ω
电源 | R42 | 1 | 输入熔断电阻 | Ever Ohms FCR1206J56RP055W | C153337 | 1206 | 56Ω 5% 0.25W 熔断型 200V | JLC | 04 复核 P1：F11 后串联，与 C40 组成输入 RC；VIN_F 短路时 ≥5W 手册保证 <30s 受控开路（F11 为 VIN_R 短路二级保护）；无 10Ω 有货熔断电阻故取 56Ω；阻燃/脉冲需台架验证；扩展库
电源 | C40 | 1 | 输入电解 | jieerrui RV63V47M6X8 | C48971005 | SMD D6.3x7.7 | 47µF 63V 105℃ 2000h | JLC | 第 2 轮降本（用户同意）：原 50V 低于 53V 浪涌；焊盘与原封装一致，高 7.7mm
电源 | C42 C44 | 2 | 输入MLCC | CCTC TCC1206X7R105K101HT | C282823 | 1206 | 1µF 100V X7R | JLC | 第 2 轮降本（用户 2026-09-26 采用）：取代 4.7µF 1210 C381466，少 1 种扩展库；29–53V 偏置有效约 0.8–1.2µF，满足 TI 1–10µF；1µF/100V 1206 统一为 C282823（第 1 轮可选项（用户 2026-09-26 14:46 采用））
电源 | C45 | 1 | VIN 高频旁路 | Samsung CL21B104KCFNNNE | C28233 | 0805 | 100nF 100V X7R | JLC | 04 复核 P1-2：Tokmas 手册 p14 要求 0.1µF 紧贴 VIN；基础库
电源 | C43 | 1 | 3.3V输出 | Samsung CL10A226MQ8NRNC | C59461 | 0603 | 22µF 6.3V X5R | JLC | 第 2 轮降本（用户 2026-09-26 采用）；3.3V 偏置有效约 10µF；基础库
MCU | U6 | 1 | MCU | WCH CH32V203C8T6 | C3001172 | LQFP-48 | RISC-V 144MHz 64K CAN2.0B | JLC | 降本 替代 STM32G0B1
MCU | Y1 | 1 | 晶振 | YXC X322512MSB4SI | C9002 | 3225 | 12MHz ±20ppm CL20pF | JLC | 降本推荐项；基础库；固件 HSE=12MHz PLL×12=144MHz
MCU | C56 C57 | 2 | 晶振负载 | 0402CG330J500NT | C1562 | 0402 | 33pF C0G 50V | JLC | 05 规格书（用户 2026-09-27 确认）：CL20pF+杂散2–7pF → 33pF（原 20pF C1554 频偏约 +34ppm）；基础库
MCU | C50-C54 | 5 | 去耦 | Samsung CL05B104KO5NNNC | C1525 | 0402 | 100nF 16V | JLC
MCU | C55 | 1 | MCU储能 | Samsung CL10A475KO8NNNC | C19666 | 0603 | 4.7µF 16V | JLC
MCU | R50 | 1 | BOOT0下拉 | UNI-ROYAL 0402WGF1002TCE | C25744 | 0402 | 10k | JLC
MCU | U7 | 1 | CAN收发器 | HGSEMI SN65HVD230M/TR-HG | C55259679 | SOIC-8 | 3.3V CAN 5Mbps | JLC | 第 2 轮降本（用户 2026-09-26 采用）（可选项）：TI C12084 引脚兼容；Rs 三模式相同
MCU | C59 | 1 | CAN去耦 | Samsung CL05B104KO5NNNC | C1525 | 0402 | 100nF | JLC
MCU | C58 | 1 | NRST 电容 | Samsung CL05B104KO5NNNC | C1525 | 0402 | 100nF | JLC | 05 规格书（用户 2026-09-27 确认）：手册 Fig 4-7
MCU | R51 R52 | 2 | PRECHG_EN / BAL_CLK 下拉 | UNI-ROYAL 0402WGF1003TCE | C25741 | 0402 | 100k | JLC | 05 规格书（用户 2026-09-27 确认）：MCU 复位即停（BAL_CLK 漏电 3µA×03 页 1M 可能被判高）
MCU | R53 | 1 | CAN TXD 上拉 | UNI-ROYAL 0402WGF1002TCE | C25744 | 0402 | 10k | JLC | 05 规格书（用户 2026-09-27 确认）：复位时总线保持隐性
MCU | R56 R57 | 2 | 共模电感旁路 | UNI-ROYAL 0402WGF0000TCE | C17168 | 0402 | 0Ω | JLC | 05 规格书（用户 2026-09-27 确认）：L2 DNP 时贴
MCU | L2 | 1 | CAN 共模电感 | TDK ACT1210-510-2P-TL00 | C95572 | SMD 3.2x2.5 | 51µH | DNP | 05 规格书（用户 2026-09-27 确认）：预留
MCU | J8 | 1 | 调试口 | PZ254V-11-06P | C492405 | THT 1x6 2.54mm | 3V3/SWDIO/SWCLK/GND/TX/RX | DNP | 05 规格书（用户 2026-09-27 确认）：取代 SWD 2×5 1.27mm；接 WCH-LinkE
MCU | R54 | 1 | Rs 高速模式 | UNI-ROYAL 0402WGF0000TCE | C17168 | 0402 | 0Ω | JLC | Rs 经 0Ω 直接接 GND = 高速模式（原 10k 实为斜率控制）；保留焊盘，需要限斜率时改 10k–47k
MCU | R55 | 1 | CAN终端 | UNI-ROYAL 0603WAF1200T5E | C22787 | 0603 | 120Ω 1% | JLC | 单电阻终端 基础库 跳线可选
MCU | JP1 | 1 | CAN 终端跳线 | PZ254V-11-02P | C492401 | THT 1x2 2.54mm | 2P 排针 | JLC | 用户 2026-09-27：120Ω 终端要做跳线可选不用 → R55 串 JP1，插跳线帽=接入终端；扩展库
MCU | JP1-CAP | 1 | 跳线帽 | 2.54 Short Circuit Cap Closed | C100114 | P=2.54mm | 1x2 2.54mm | 机械件 | 手工装；振动场合打胶固定
MCU | U8 | 1 | CAN ESD | UMW PESD2CAN | C2687131 | SOT-23 | Vrwm 24V Cj 25pF | JLC | 第 2 轮降本（用户 2026-09-26 采用）：Nexperia C75176 同参数替代
MCU | J7 | 1 | CAN端子 | Megastar ZX-XH2.54-4PZZ | C7429634 | THT 2.50mm | XH 2.50mm 4P 立式 | JLC | 降本推荐项；封装实测 2.50mm
MCU | LED1 LED2 | 2 | 状态LED | NCD0805R1 | C84256 | 0805 | 红 | JLC
MCU | LED3 | 1 | 运行LED | KT-0805G | C2297 | 0805 | 绿 | JLC
MCU | R58 R59 | 2 | 红灯限流 | UNI-ROYAL 0402WGF1001TCE | C11702 | 0402 | 1k | JLC
MCU | R60 | 1 | 绿灯限流 | UNI-ROYAL 0402WGF3300TCE | C25104 | 0402 | 330Ω 1% | JLC | 05 规格书（用户 2026-09-27 确认）：绿灯 VF 2.6–3.1V，1k 只有 0.2–0.7mA 太暗；基础库
MCU | SW1 | 1 | 按键 | TS-1187A-B-A-B | C318884 | SMD 5.1x5.1 |  | JLC
连接器 | J5 | 1 | 采样端子 | BOOMELE XH-13A | C40669 | THT 2.50mm | XH 2.50mm 13P 立式 | JLC | 第 1 轮可选项（用户 2026-09-26 14:46 采用）：XH 2.50mm 13P 立式；嘉立创库存 244（够 244 块）；用户 2026-09-27：画在 02 页；针脚 1 NTC_CELL1 / 2 GND / 3 NTC_CELL2 / 4 GND / 5–13 CELL0–CELL8；线束侧电芯端采样线加保险丝（线束件）
连接器 | J6 | 1 | 均衡端子 | 连欣 XDWF-C3030WV-2*5P | C18202166 | THT 3.00mm | 2x5 3.00mm 立式 Micro-Fit 兼容 5A/针 | JLC | 降本推荐项；⚠针号之字形（奇数一排偶数一排），原理图/线束按物理位置对针；先买样品试插；用户 2026-09-27：焊盘 n 接 BAL(n−1) 焊盘 10 空（design/03_balancer-spec.md §4）

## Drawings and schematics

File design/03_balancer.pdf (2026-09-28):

# 100µF 6.3V NC

# VB1 接口网络（跨页用全局标签，名称以本清单为准）：

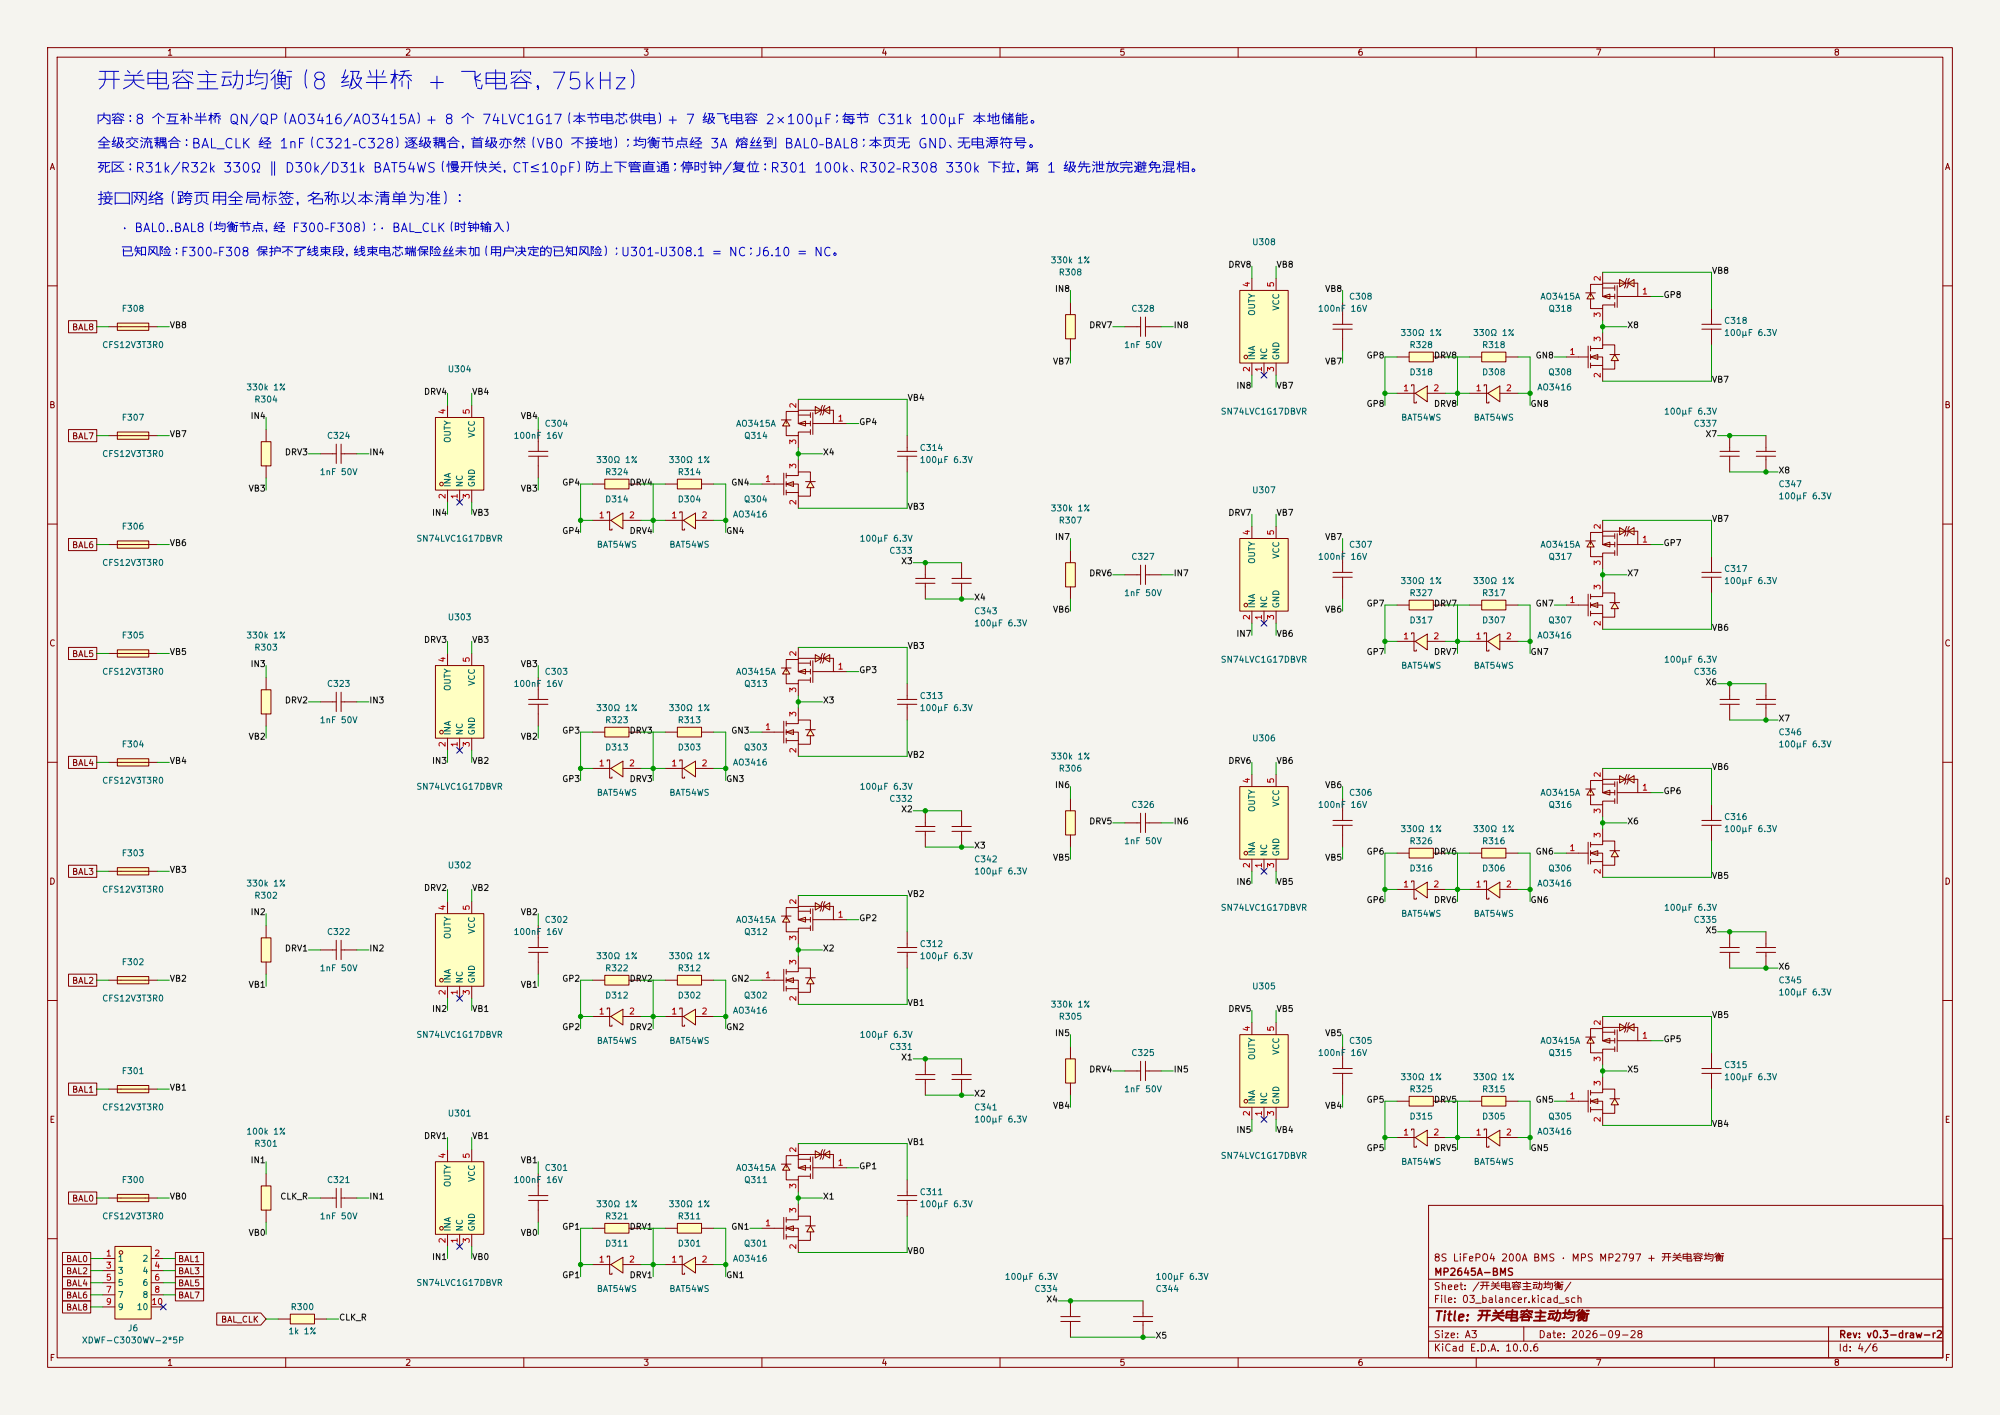
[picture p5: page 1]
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

死区：R31k/R32k 330Ω ∥ D30k/D31k BAT54WS（慢开快关，CT≤10pF）防上下管直通；停时钟/复位：R301 100k、R302⁻R308 330k 下拉，第 1 级先泄放完避免混相。

已知风险：F300⁻F308 保护不了线束段，线束电芯端保险丝未加（用户决定的已知风险）；U301⁻U308.1 = NC；J6.10 = NC。

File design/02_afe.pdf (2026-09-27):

# 02 AFE：MP2797 采集与保护（8S，C9–C16 并到 C8；WDT 悬空；xALERT 高有效 100k 下拉）

### 1/3 = NTC_CELL1/2，2/4 = GND；

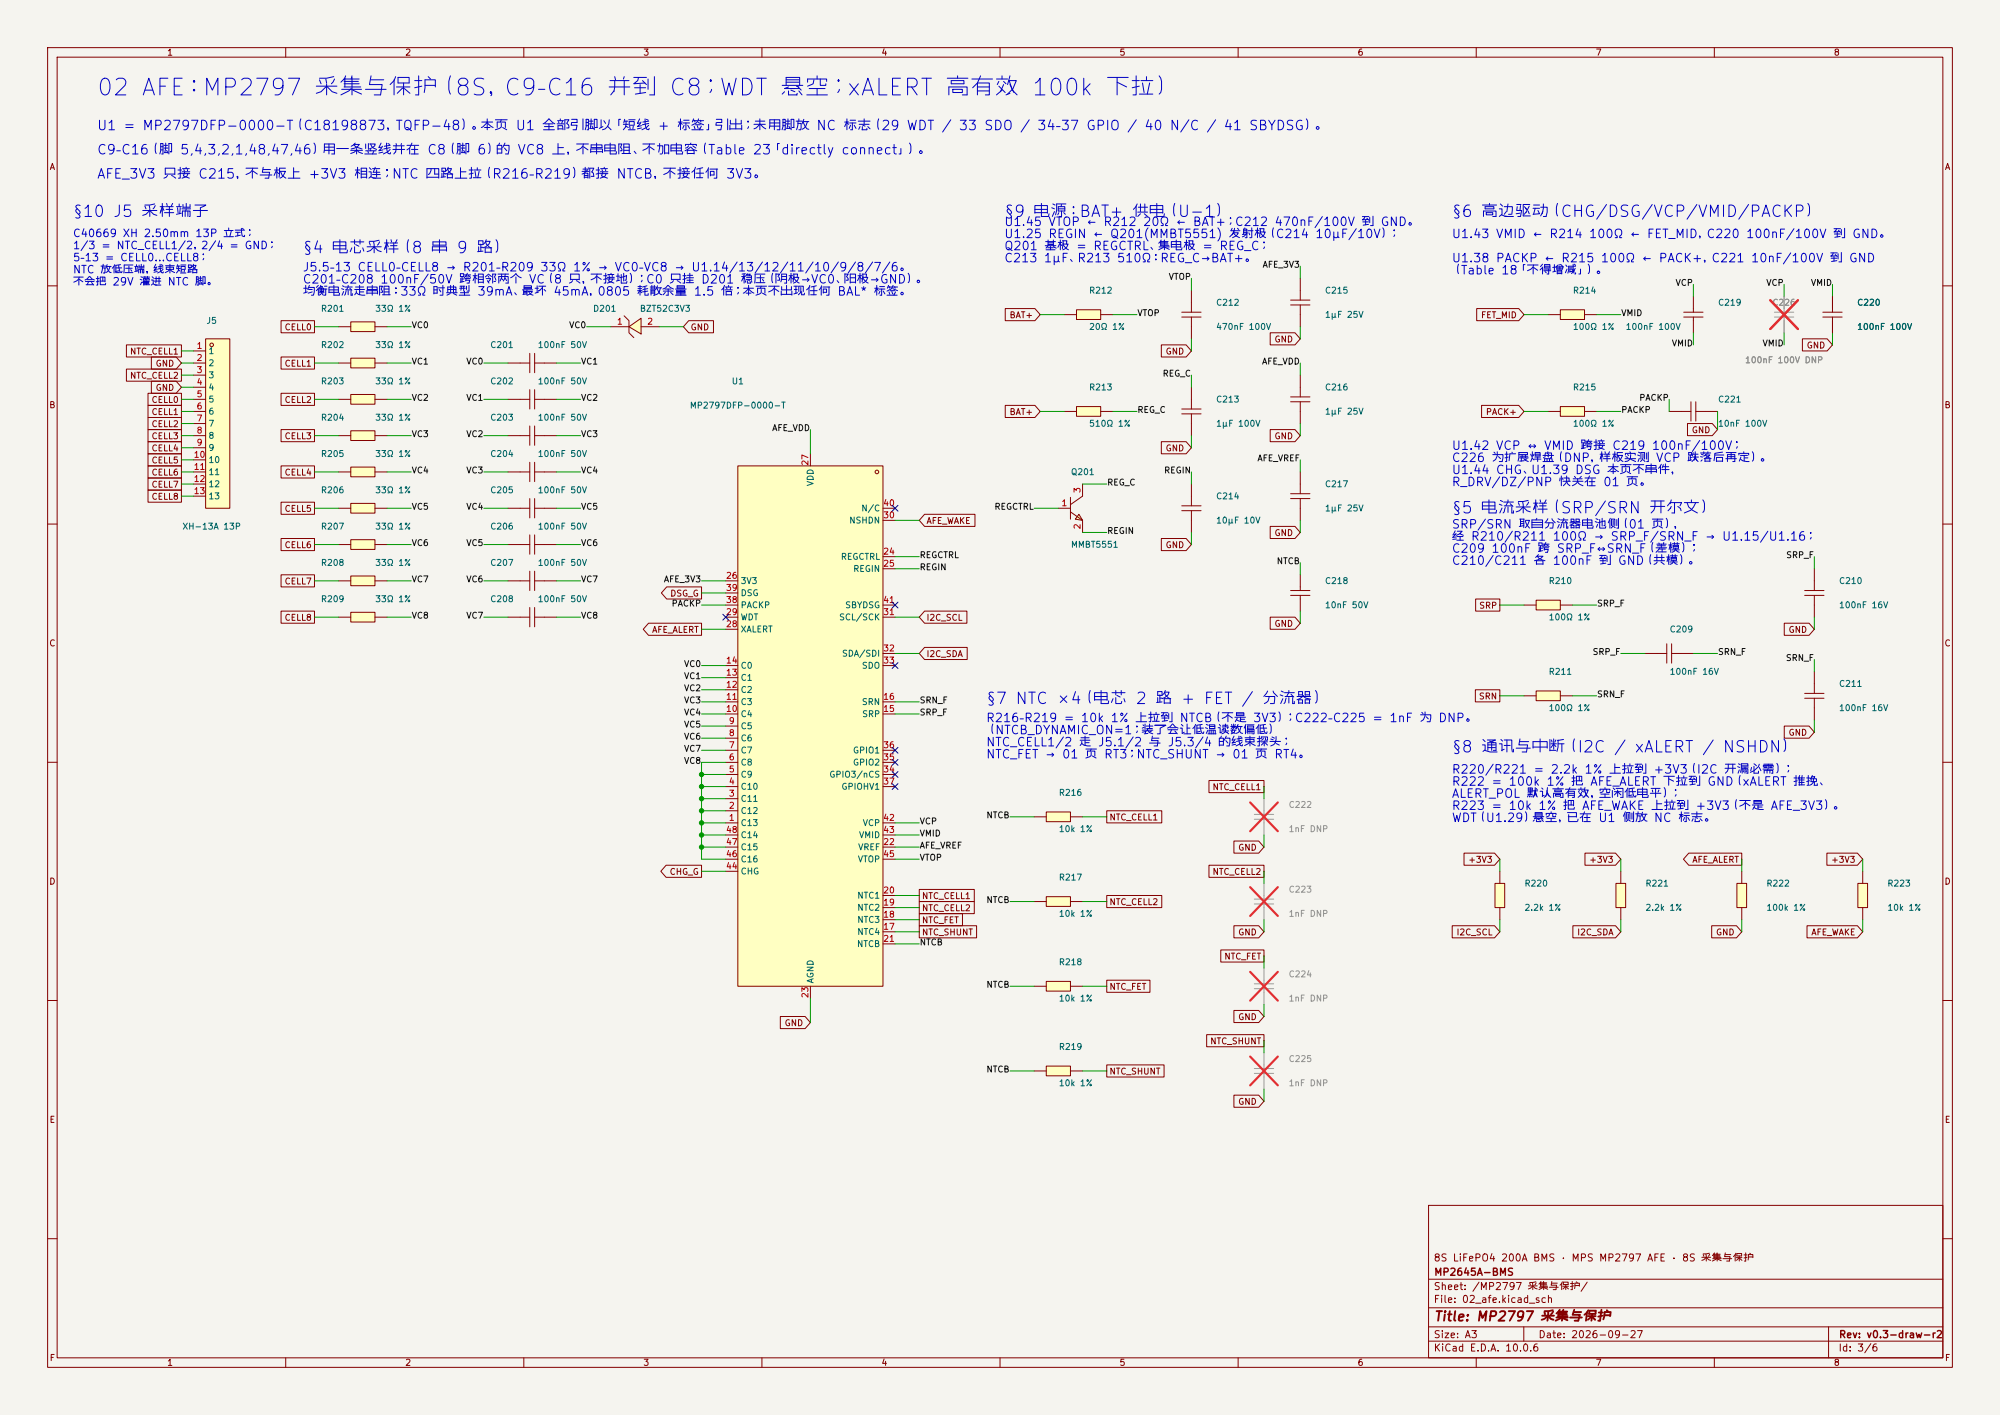
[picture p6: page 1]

U1 = MP2797DFP⁻0000⁻T（C18198873，TQFP⁻48）。本页 U1 全部引脚以「短线 + 标签」引出；未用脚放 NC 标志（29 WDT / 33 SDO / 34⁻37 GPIO / 40 N/C / 41 SBYDSG）。

C9⁻C16（脚 5,4,3,2,1,48,47,46）用一条竖线并在 C8（脚 6）的 VC8 上，不串电阻、不加电容（Table 23「directly connect」）。

AFE_3V3 只接 C215，不与板上 +3V3 相连；NTC 四路上拉（R216⁻R219）都接 NTCB，不接任何 3V3。

§6 高边驱动（CHG/DSG/VCP/VMID/PACKP）

J5.5⁻13 CELL0⁻CELL8 → R201⁻R209 33Ω 1% → VC0⁻VC8 → U1.14/13/12/11/10/9/8/7/6。
C201⁻C208 100nF/50V 跨相邻两个 VC（8 只，不接地）；C0 只挂 D201 稳压（阴极→VC0、阳极→GND）。
均衡电流走串阻：33Ω 时典型 39mA、最坏 45mA，0805 耗散余量 1.5 倍；本页不出现任何 BAL* 标签。

U1.42 VCP ↔ VMID 跨接 C219 100nF/100V；
C226 为扩展焊盘（DNP，样板实测 VCP 跌落后再定）。
U1.44 CHG、U1.39 DSG 本页不串件，
R_DRV/DZ/PNP 快关在 01 页。
§5 电流采样（SRP/SRN 开尔文）
SRP/SRN 取自分流器电池侧（01 页），
经 R210/R211 100Ω → SRP_F/SRN_F → U1.15/U1.16；
C209 100nF 跨 SRP_F↔SRN_F（差模）；
C210/C211 各 100nF 到 GND（共模）。

§7 NTC ×4（电芯 2 路 + FET / 分流器）

R216⁻R219 = 10k 1% 上拉到 NTCB（不是 3V3）；C222⁻C225 = 1nF 为 DNP。
（NTCB_DYNAMIC_ON=1；装了会让低温读数偏低）
NTC_CELL1/2 走 J5.1/2 与 J5.3/4 的线束探头；

R220/R221 = 2.2k 1% 上拉到 +3V3（I2C 开漏必需）；
R222 = 100k 1% 把 AFE_ALERT 下拉到 GND（xALERT 推挽、
ALERT_POL 默认高有效，空闲低电平）；
R223 = 10k 1% 把 AFE_WAKE 上拉到 +3V3（不是 AFE_3V3）。
WDT（U1.29）悬空，已在 U1 侧放 NC 标志。

8S LiFePO4 200A BMS · MPS MP2797 AFE · 8S 采集与保护
MP2645A-BMS
Sheet: /MP2797 采集与保护/
File: 02_afe.kicad_sch
Title: MP2797 采集与保护

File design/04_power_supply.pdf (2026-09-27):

VIN_R | VIN_F 辅助电源（LMR16006X 直降 3.3V）

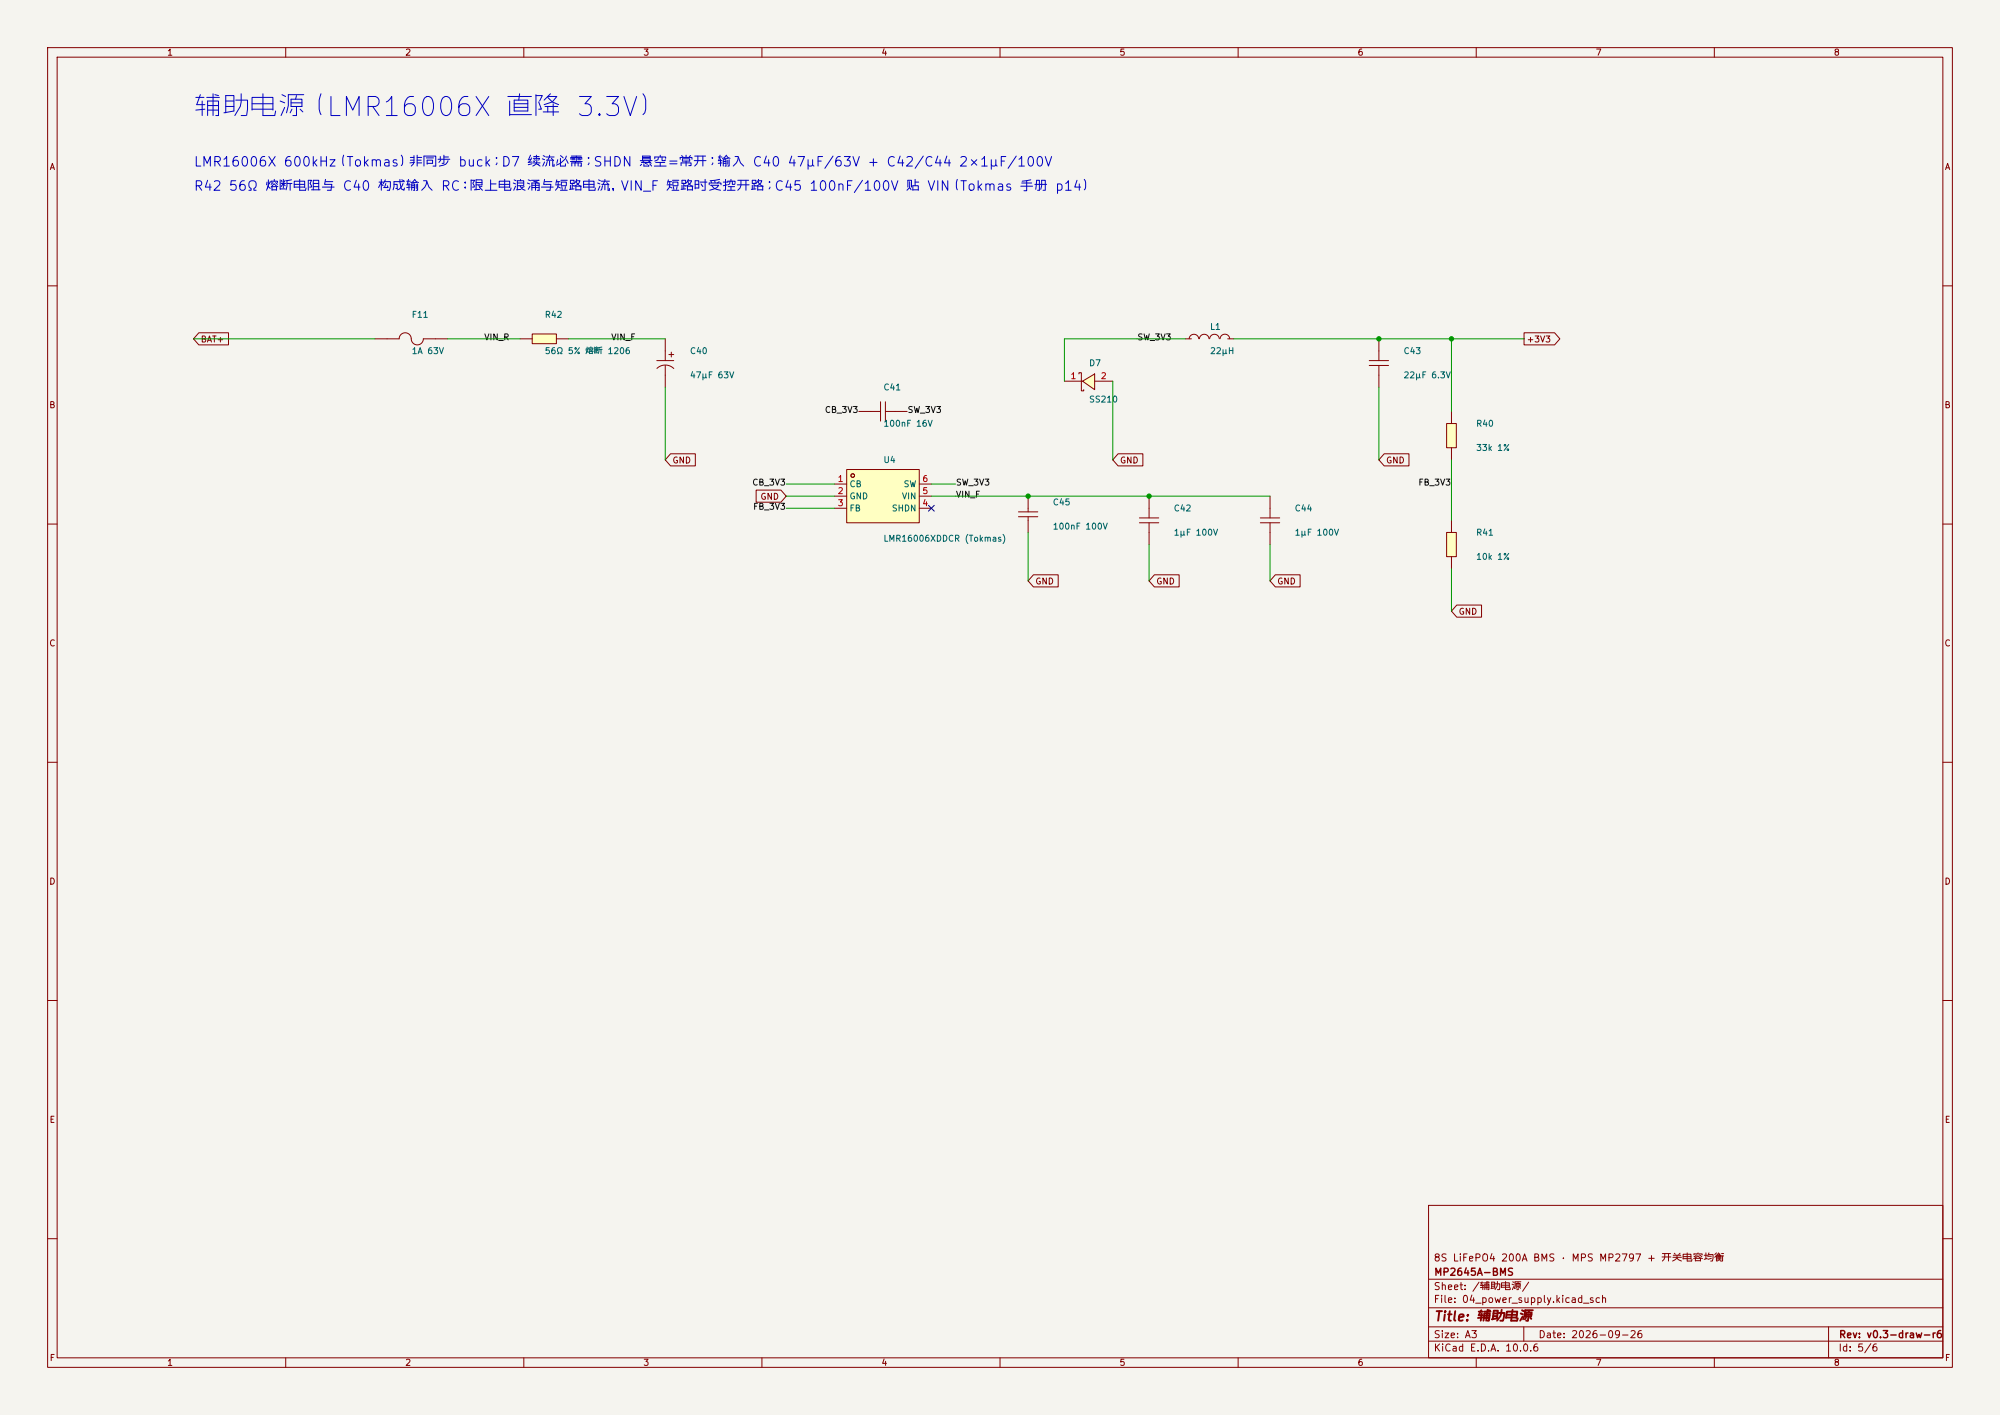
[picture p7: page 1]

LMR16006X 600kHz（Tokmas）非同步 buck；D7 续流必需；SHDN 悬空=常开；输入 C40 47µF/63V + C42/C44 2×1µF/100V

R42 56Ω 熔断电阻与 C40 构成输入 RC：限上电浪涌与短路电流，VIN_F 短路时受控开路；C45 100nF/100V 贴 VIN（Tokmas 手册 p14）

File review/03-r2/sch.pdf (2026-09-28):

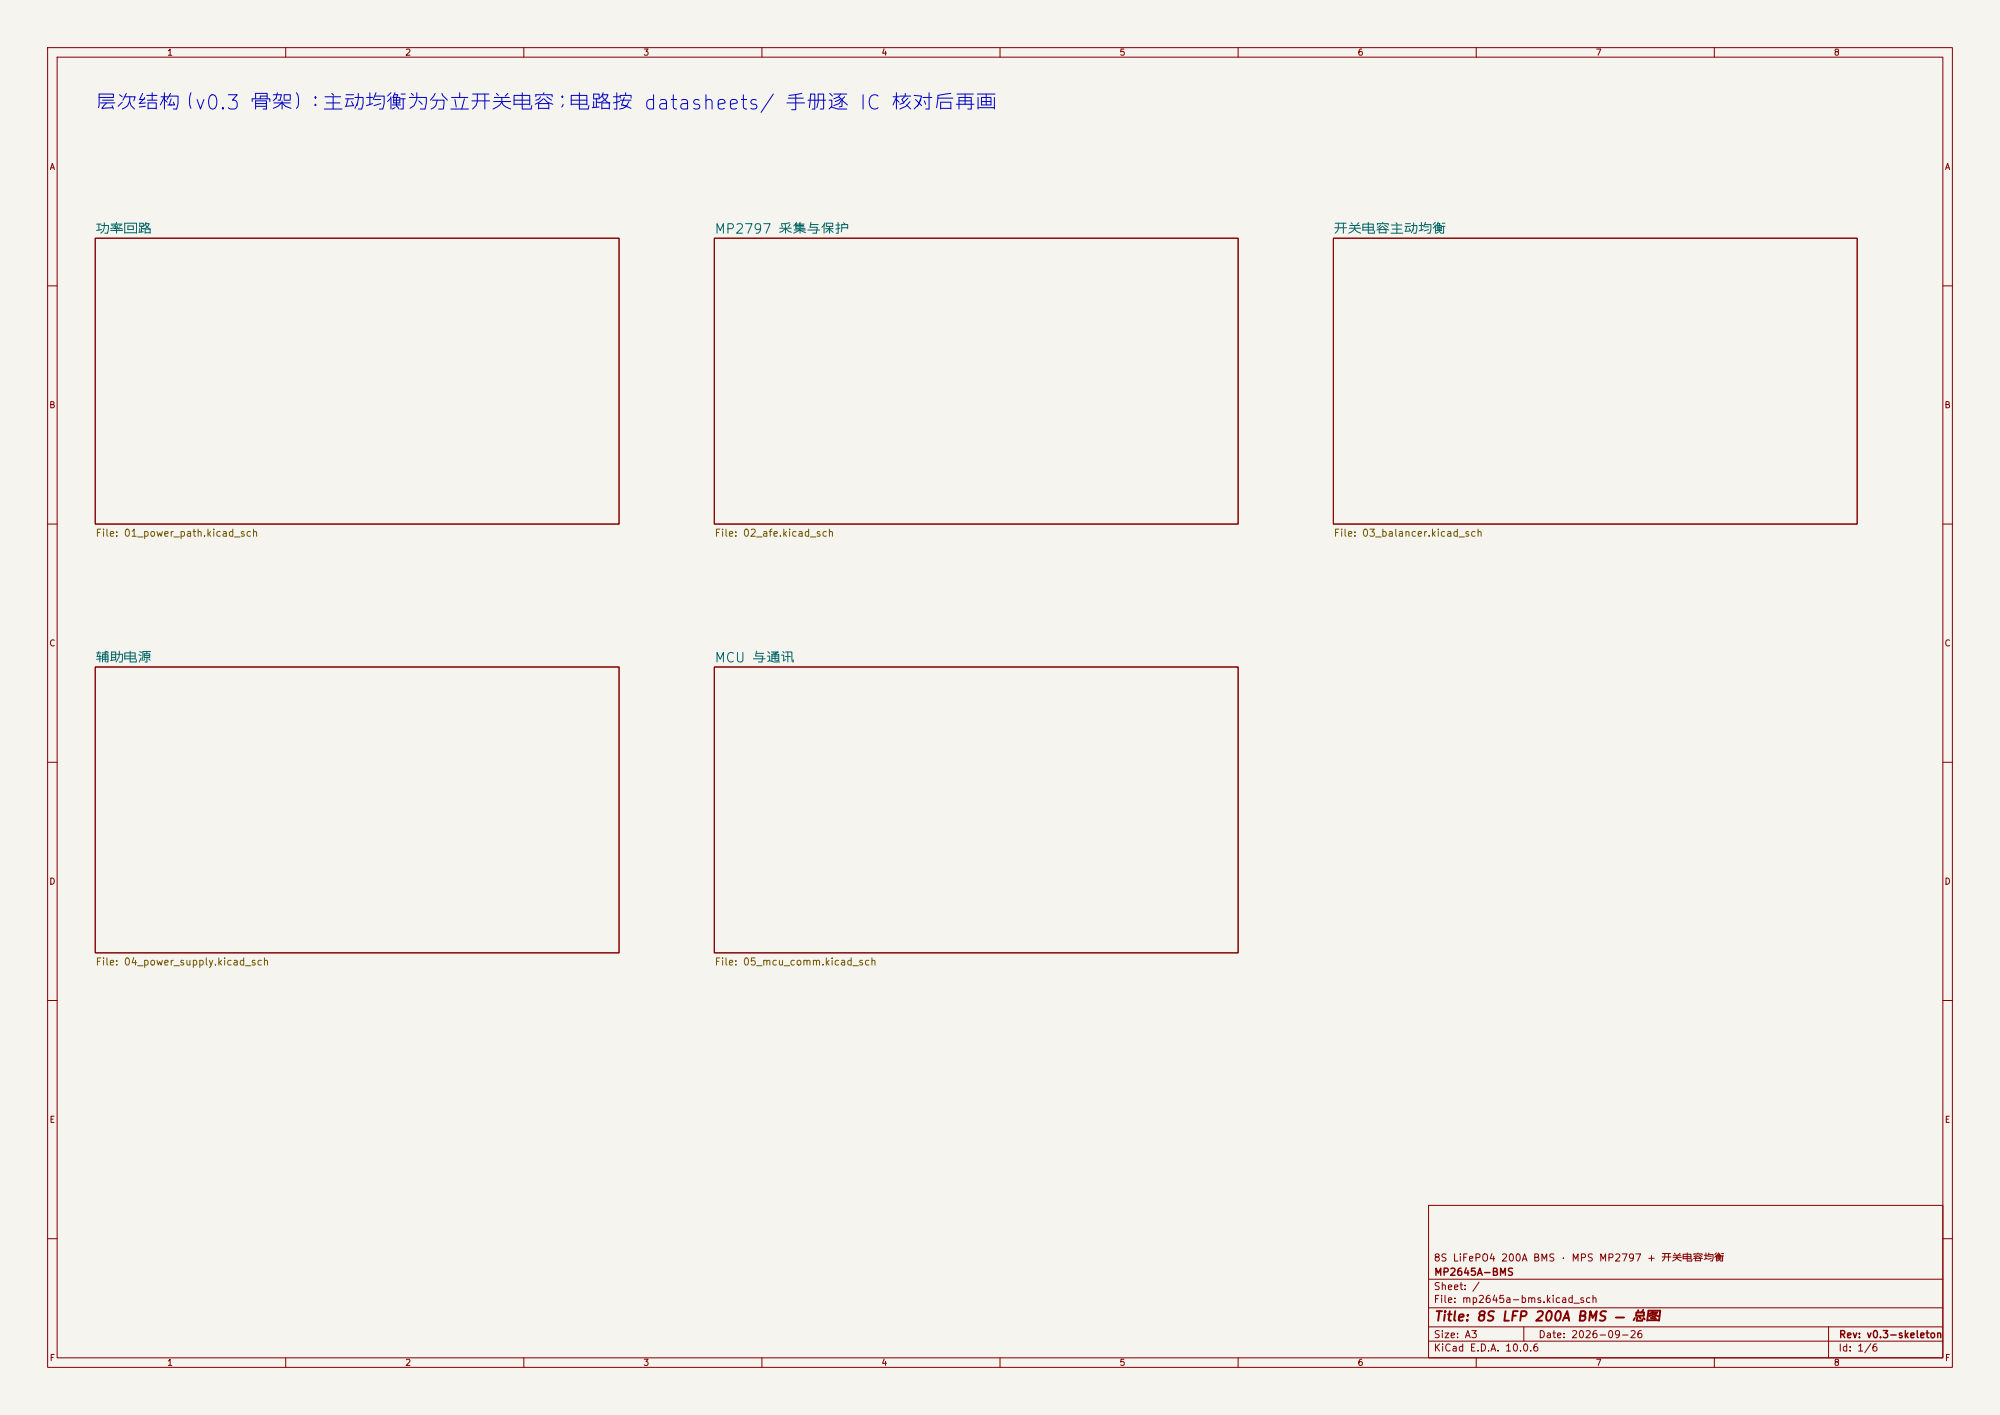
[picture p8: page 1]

层次结构（v0.3 骨架）：主动均衡为分立开关电容；电路按 datasheets/ 手册逐 IC 核对后再画

8S LiFePO4 200A BMS · MPS MP2797 + 开关电容均衡
MP2645A-BMS
Sheet: /
File: mp2645a-bms.kicad_sch
Title: 8S LFP 200A BMS — 总图

Size: A3 | Rev: v0.3-skeleton | F Date: 2026-09-26
KiCad E.D.A. 10.0.6 | Id: 1/6

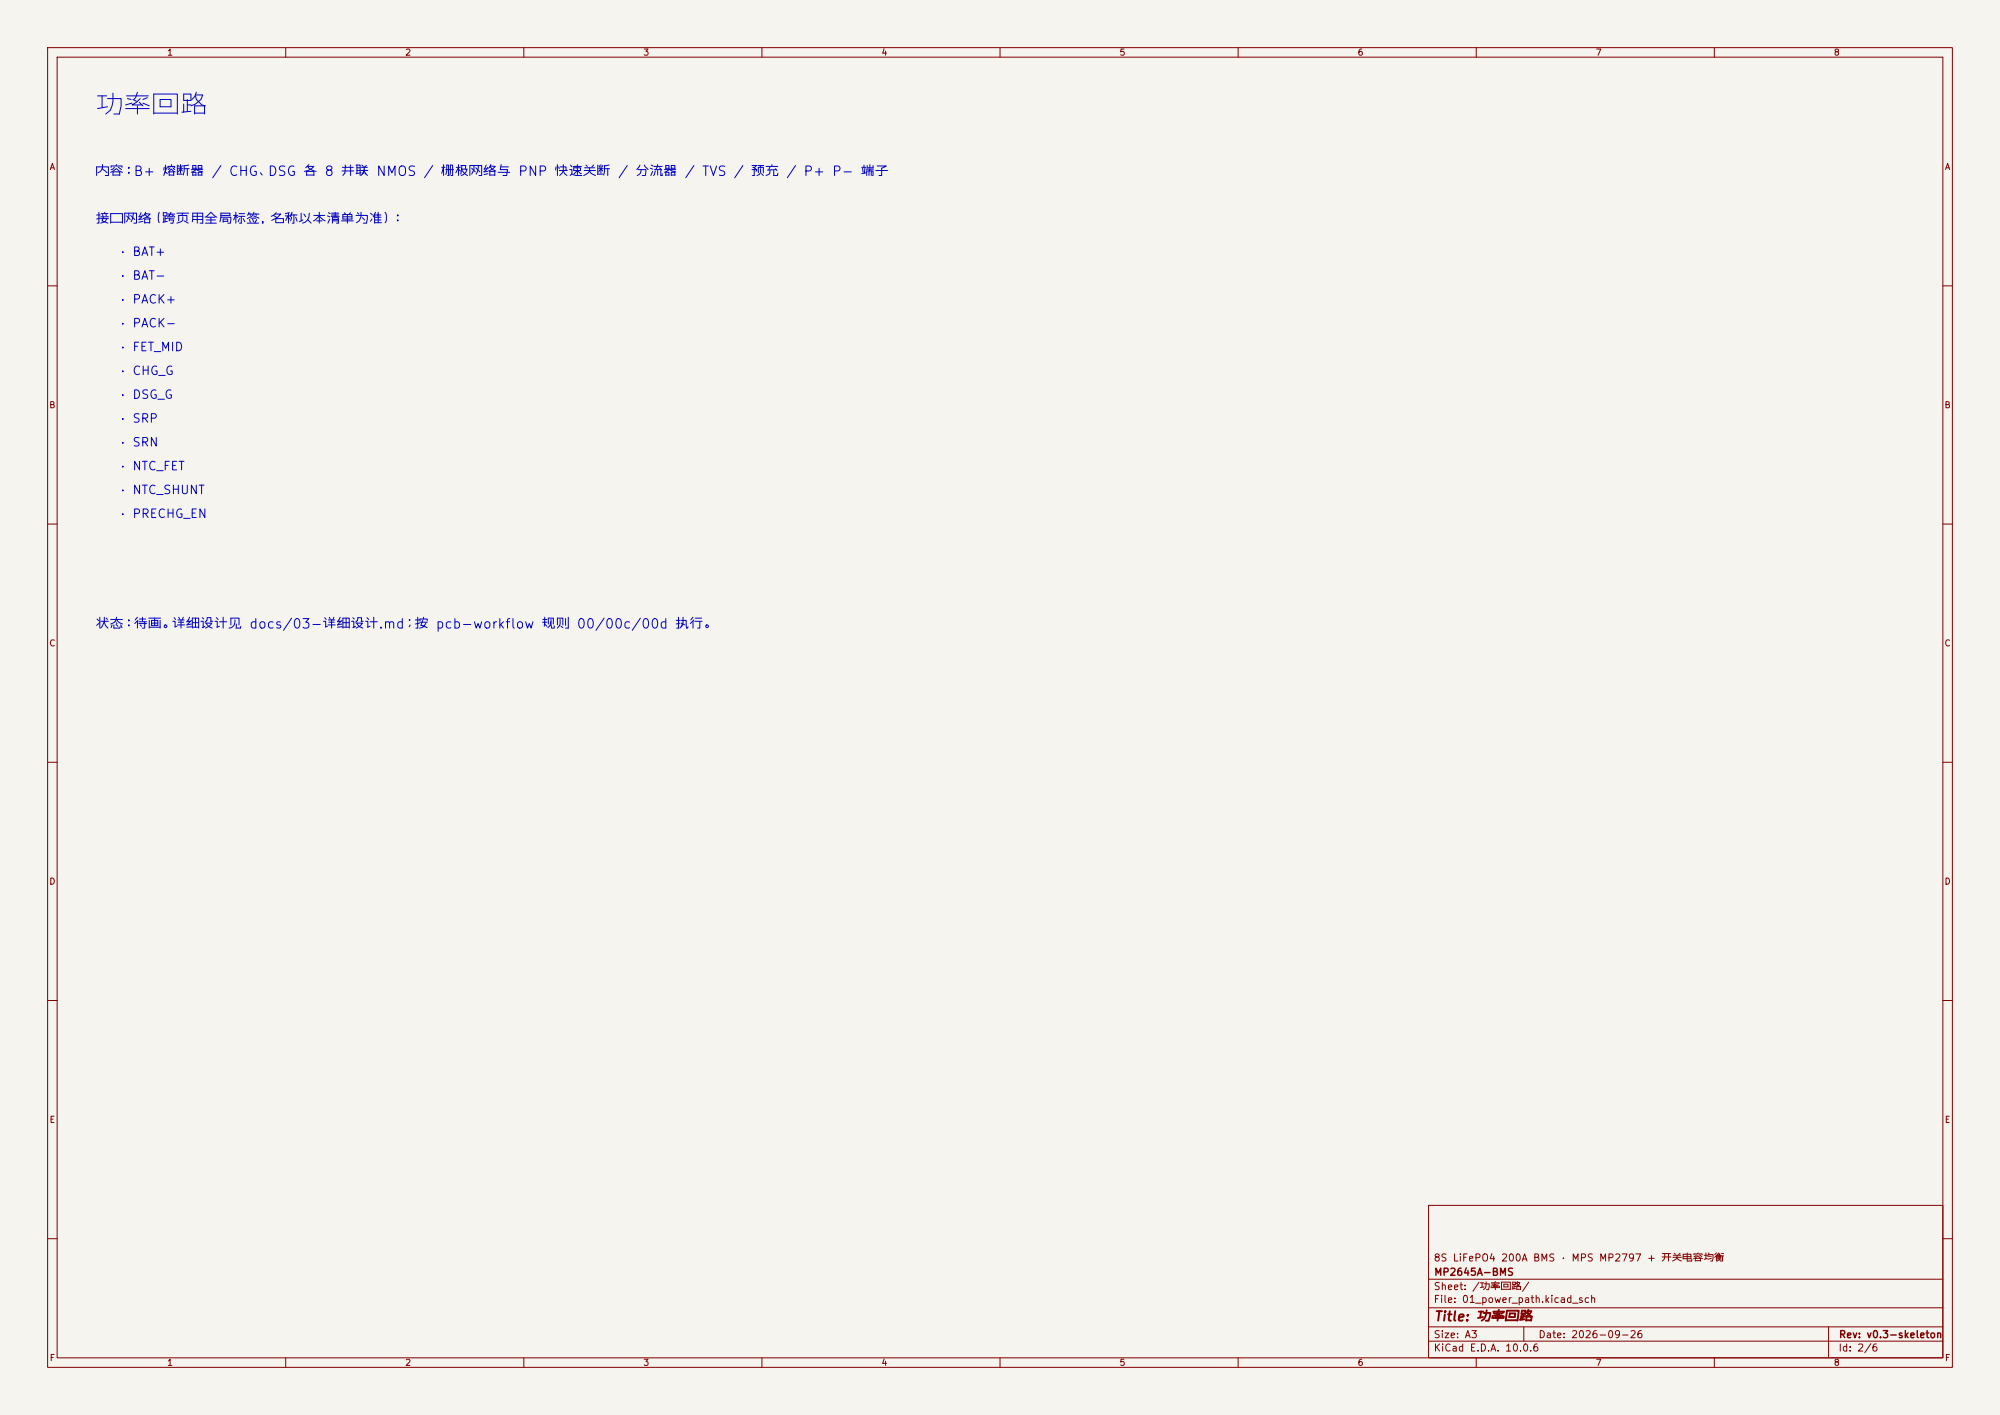
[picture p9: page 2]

内容：B+ 熔断器 / CHG、DSG 各 8 并联 NMOS / 栅极网络与 PNP 快速关断 / 分流器 / TVS / 预充 / P+ P- 端子

状态：待画。详细设计见 docs/03-详细设计.md；按 pcb-workflow 规则 00/00c/00d 执行。


02 AFE：MP2797 采集与保护（8S，C9–C16 并到 C8；WDT 悬空；xALERT 高有效 100k 下拉）

U1 = MP2797DFP-0000-T（C18198873，TQFP-48）。本页 U1 全部引脚以「短线 + 标签」引出；未用脚放 NC 标志（29 WDT / 33 SDO / 34–37 GPIO / 40 N/C / 41 SBYDSG）。

C9–C16（脚 5,4,3,2,1,48,47,46）用一条竖线并在 C8（脚 6）的 VC8 上，不串电阻、不加电容（Table 23「directly connect」）。

AFE_3V3 只接 C215，不与板上 +3V3 相连；NTC 四路上拉（R216–R219）都接 NTCB，不接任何 3V3。

§6 高边驱动（CHG/DSG/VCP/VMID/PACKP）

J5.5–13 CELL0–CELL8 → R201–R209 33Ω 1% → VC0–VC8 → U1.14/13/12/11/10/9/8/7/6。
C201–C208 100nF/50V 跨相邻两个 VC（8 只，不接地）；C0 只挂 D201 稳压（阴极→VC0、阳极→GND）。
均衡电流走串阻：33Ω 时典型 39mA、最坏 45mA，0805 耗散余量 1.5 倍；本页不出现任何 BAL* 标签。

U1.42 VCP ↔ VMID 跨接 C219 100nF/100V；
C226 为扩展焊盘（DNP，样板实测 VCP 跌落后再定）。
U1.44 CHG、U1.39 DSG 本页不串件，
R_DRV/DZ/PNP 快关在 01 页。
§5 电流采样（SRP/SRN 开尔文）
SRP/SRN 取自分流器电池侧（01 页），
经 R210/R211 100Ω → SRP_F/SRN_F → U1.15/U1.16；
C209 100nF 跨 SRP_F↔SRN_F（差模）；
C210/C211 各 100nF 到 GND（共模）。

§7 NTC ×4（电芯 2 路 + FET / 分流器）

R216–R219 = 10k 1% 上拉到 NTCB（不是 3V3）；C222–C225 = 1nF 为 DNP。
（NTCB_DYNAMIC_ON=1；装了会让低温读数偏低）
NTC_CELL1/2 走 J5.1/2 与 J5.3/4 的线束探头；

R220/R221 = 2.2k 1% 上拉到 +3V3（I2C 开漏必需）；
R222 = 100k 1% 把 AFE_ALERT 下拉到 GND（xALERT 推挽、
ALERT_POL 默认高有效，空闲低电平）；
R223 = 10k 1% 把 AFE_WAKE 上拉到 +3V3（不是 AFE_3V3）。
WDT（U1.29）悬空，已在 U1 侧放 NC 标志。

8S LiFePO4 200A BMS · MPS MP2797 AFE · 8S 采集与保护
MP2645A-BMS
Sheet: /MP2797 采集与保护/
File: 02_afe.kicad_sch
Title: MP2797 采集与保护


内容：8 个互补半桥 QN/QP（AO3416/AO3415A）+ 8 个 74LVC1G17（本节电芯供电）+ 7 级飞电容 2×100µF；每节 C31k 100µF 本地储能。

全级交流耦合：BAL_CLK 经 1nF（C321–C328）逐级耦合，首级亦然（VB0 不接地）；均衡节点经 3A 熔丝到 BAL0–BAL8；本页无 GND、无电源符号。

死区：R31k/R32k 330Ω ∥ D30k/D31k BAT54WS（慢开快关，CT≤10pF）防上下管直通；停时钟/复位：R301 100k、R302–R308 330k 下拉，第 1 级先泄放完避免混相。

已知风险：F300–F308 保护不了线束段，线束电芯端保险丝未加（用户决定的已知风险）；U301–U308.1 = NC；J6.10 = NC。


LMR16006X 600kHz（Tokmas）非同步 buck；D7 续流必需；SHDN 悬空=常开；输入 C40 47µF/63V + C42/C44 2×1µF/100V

R42 56Ω 熔断电阻与 C40 构成输入 RC：限上电浪涌与短路电流，VIN_F 短路时受控开路；C45 100nF/100V 贴 VIN（Tokmas 手册 p14）

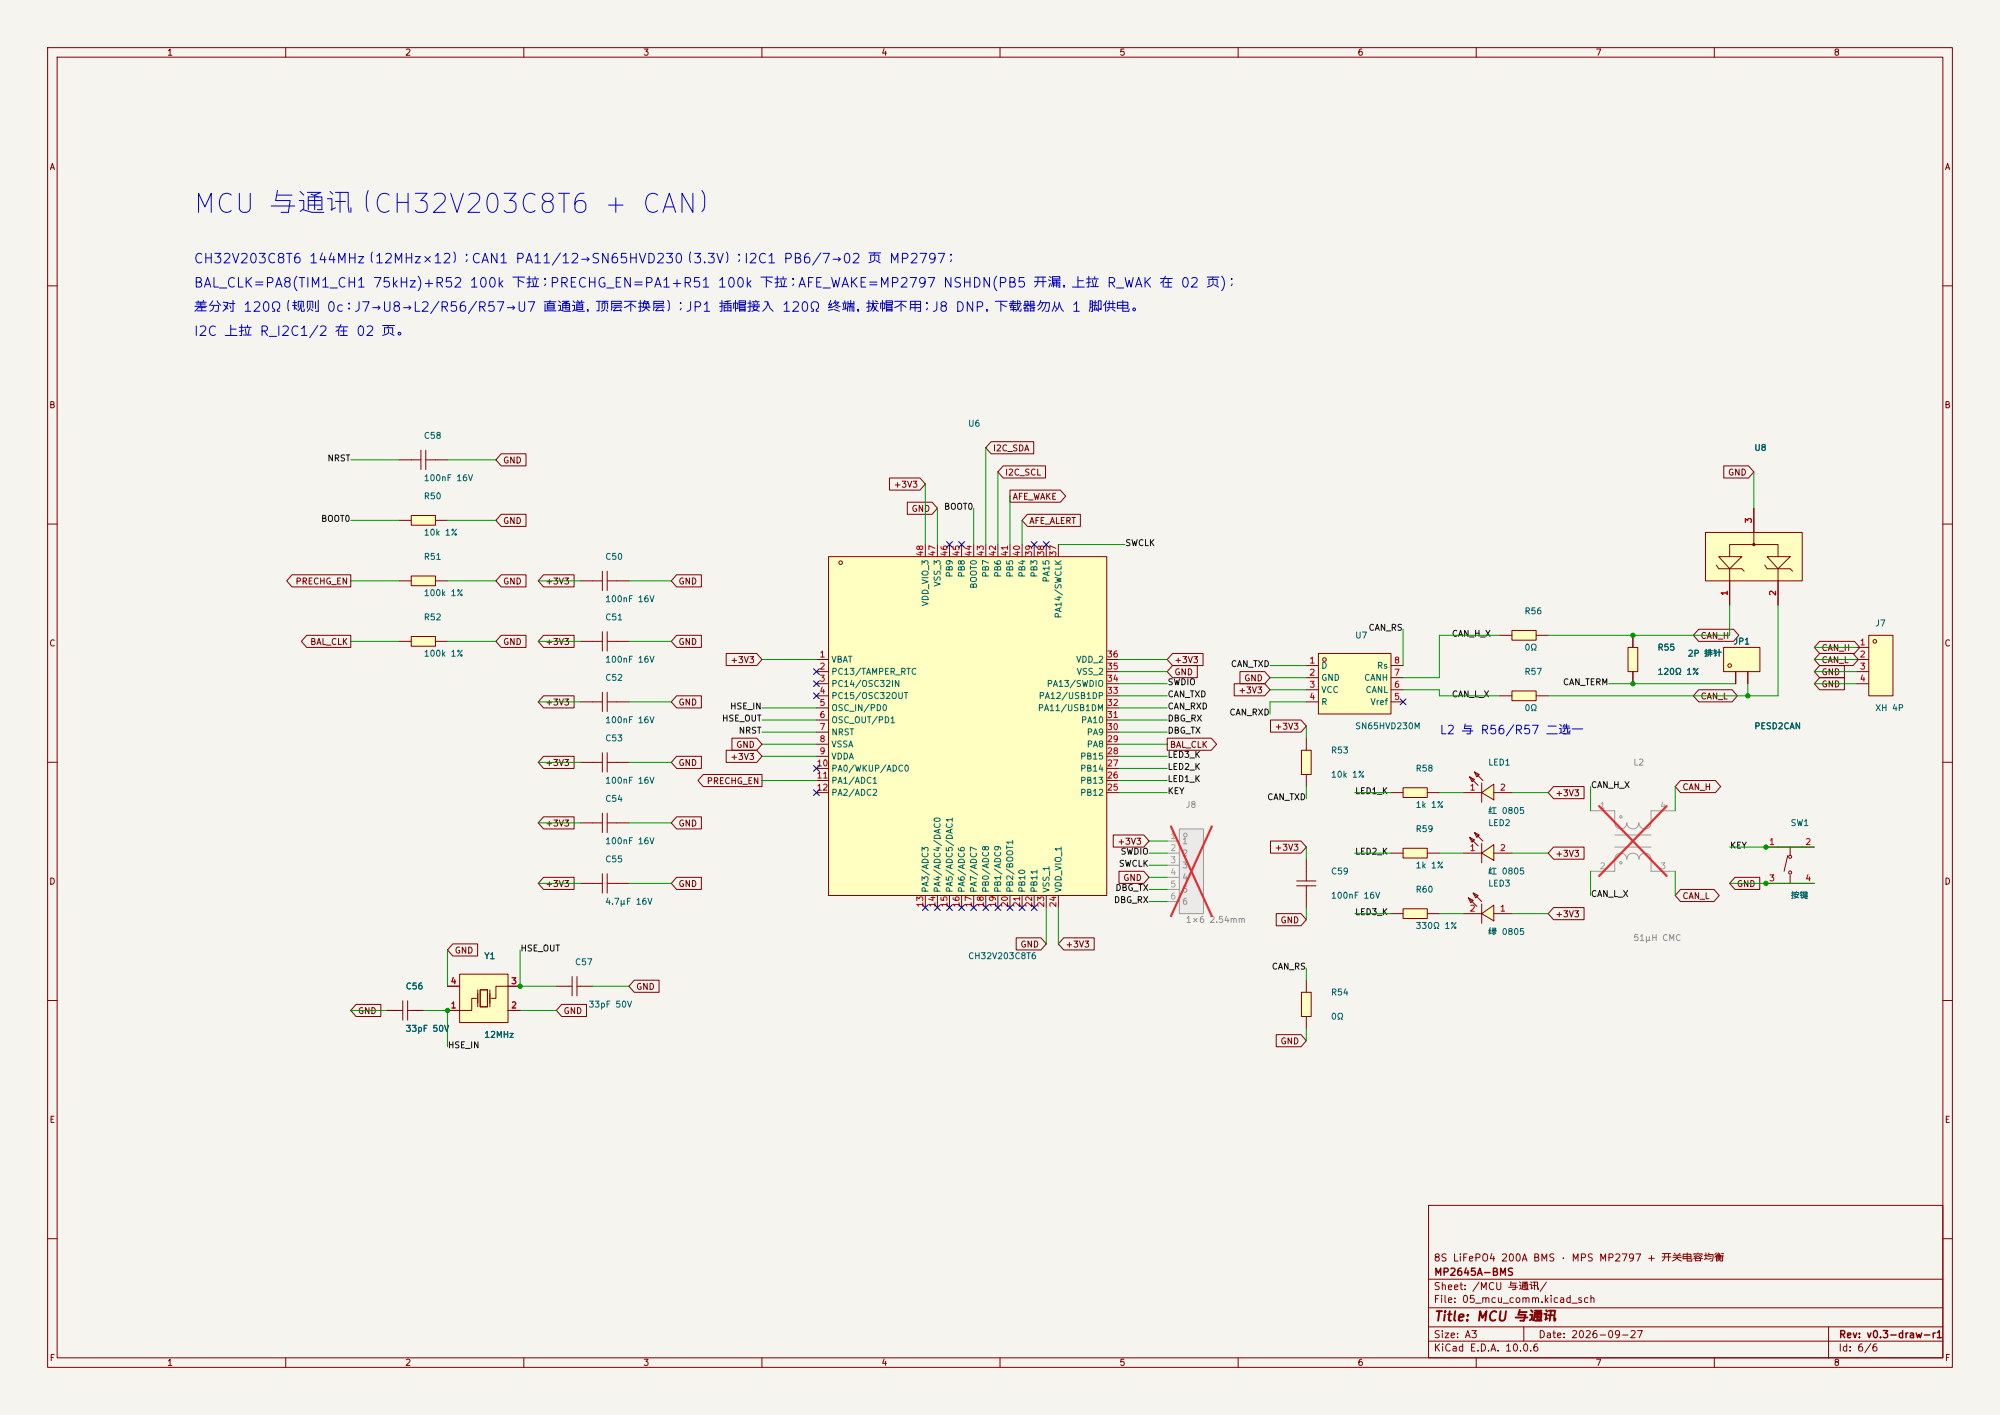
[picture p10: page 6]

CAN_H_X CAN_L_X KEY MCU 与通讯（CH32V203C8T6 + CAN）

BAL_CLK=PA8(TIM1_CH1 75kHz)+R52 100k 下拉；PRECHG_EN=PA1+R51 100k 下拉；AFE_WAKE=MP2797 NSHDN(PB5 开漏，上拉 R_WAK 在 02 页)；

差分对 120Ω（规则 0c：J7→U8→L2/R56/R57→U7 直通道，顶层不换层）；JP1 插帽接入 120Ω 终端，拔帽不用；J8 DNP，下载器勿从 1 脚供电。

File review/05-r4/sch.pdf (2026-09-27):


层次结构（v0.3 骨架）：主动均衡为分立开关电容；电路按 datasheets/ 手册逐 IC 核对后再画

8S LiFePO4 200A BMS · MPS MP2797 + 开关电容均衡
MP2645A-BMS
Sheet: /
File: mp2645a-bms.kicad_sch
Title: 8S LFP 200A BMS — 总图

Size: A3 | Rev: v0.3-skeleton | F Date: 2026-09-26
KiCad E.D.A. 10.0.6 | Id: 1/6


内容：B+ 熔断器 / CHG、DSG 各 8 并联 NMOS / 栅极网络与 PNP 快速关断 / 分流器 / TVS / 预充 / P+ P- 端子

状态：待画。详细设计见 docs/03-详细设计.md；按 pcb-workflow 规则 00/00c/00d 执行。

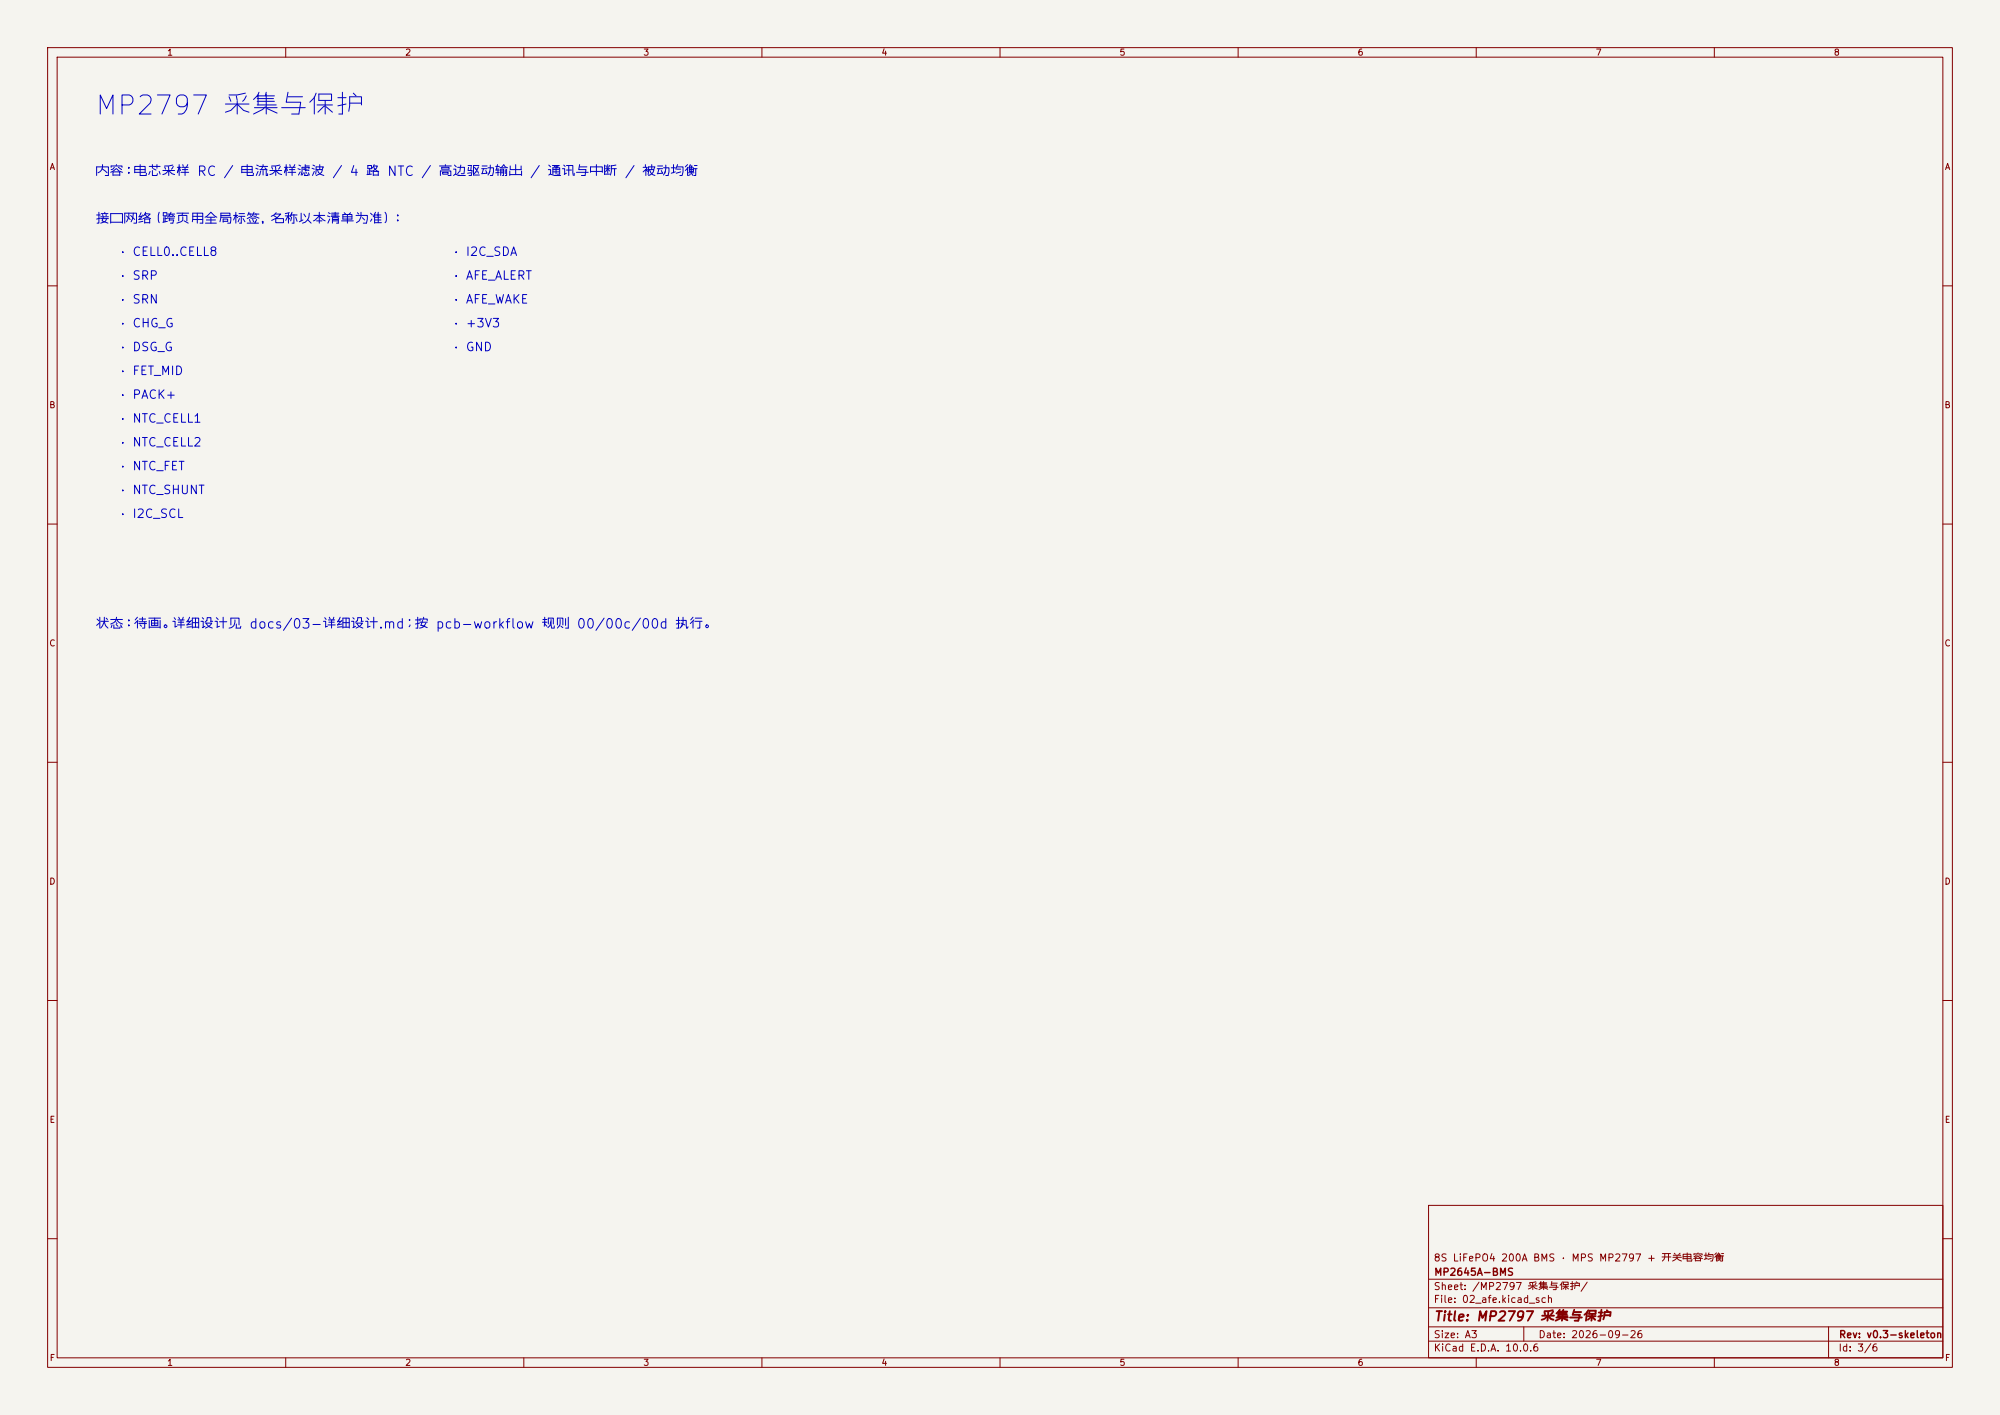
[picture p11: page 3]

内容：电芯采样 RC / 电流采样滤波 / 4 路 NTC / 高边驱动输出 / 通讯与中断 / 被动均衡

状态：待画。详细设计见 docs/03-详细设计.md；按 pcb-workflow 规则 00/00c/00d 执行。

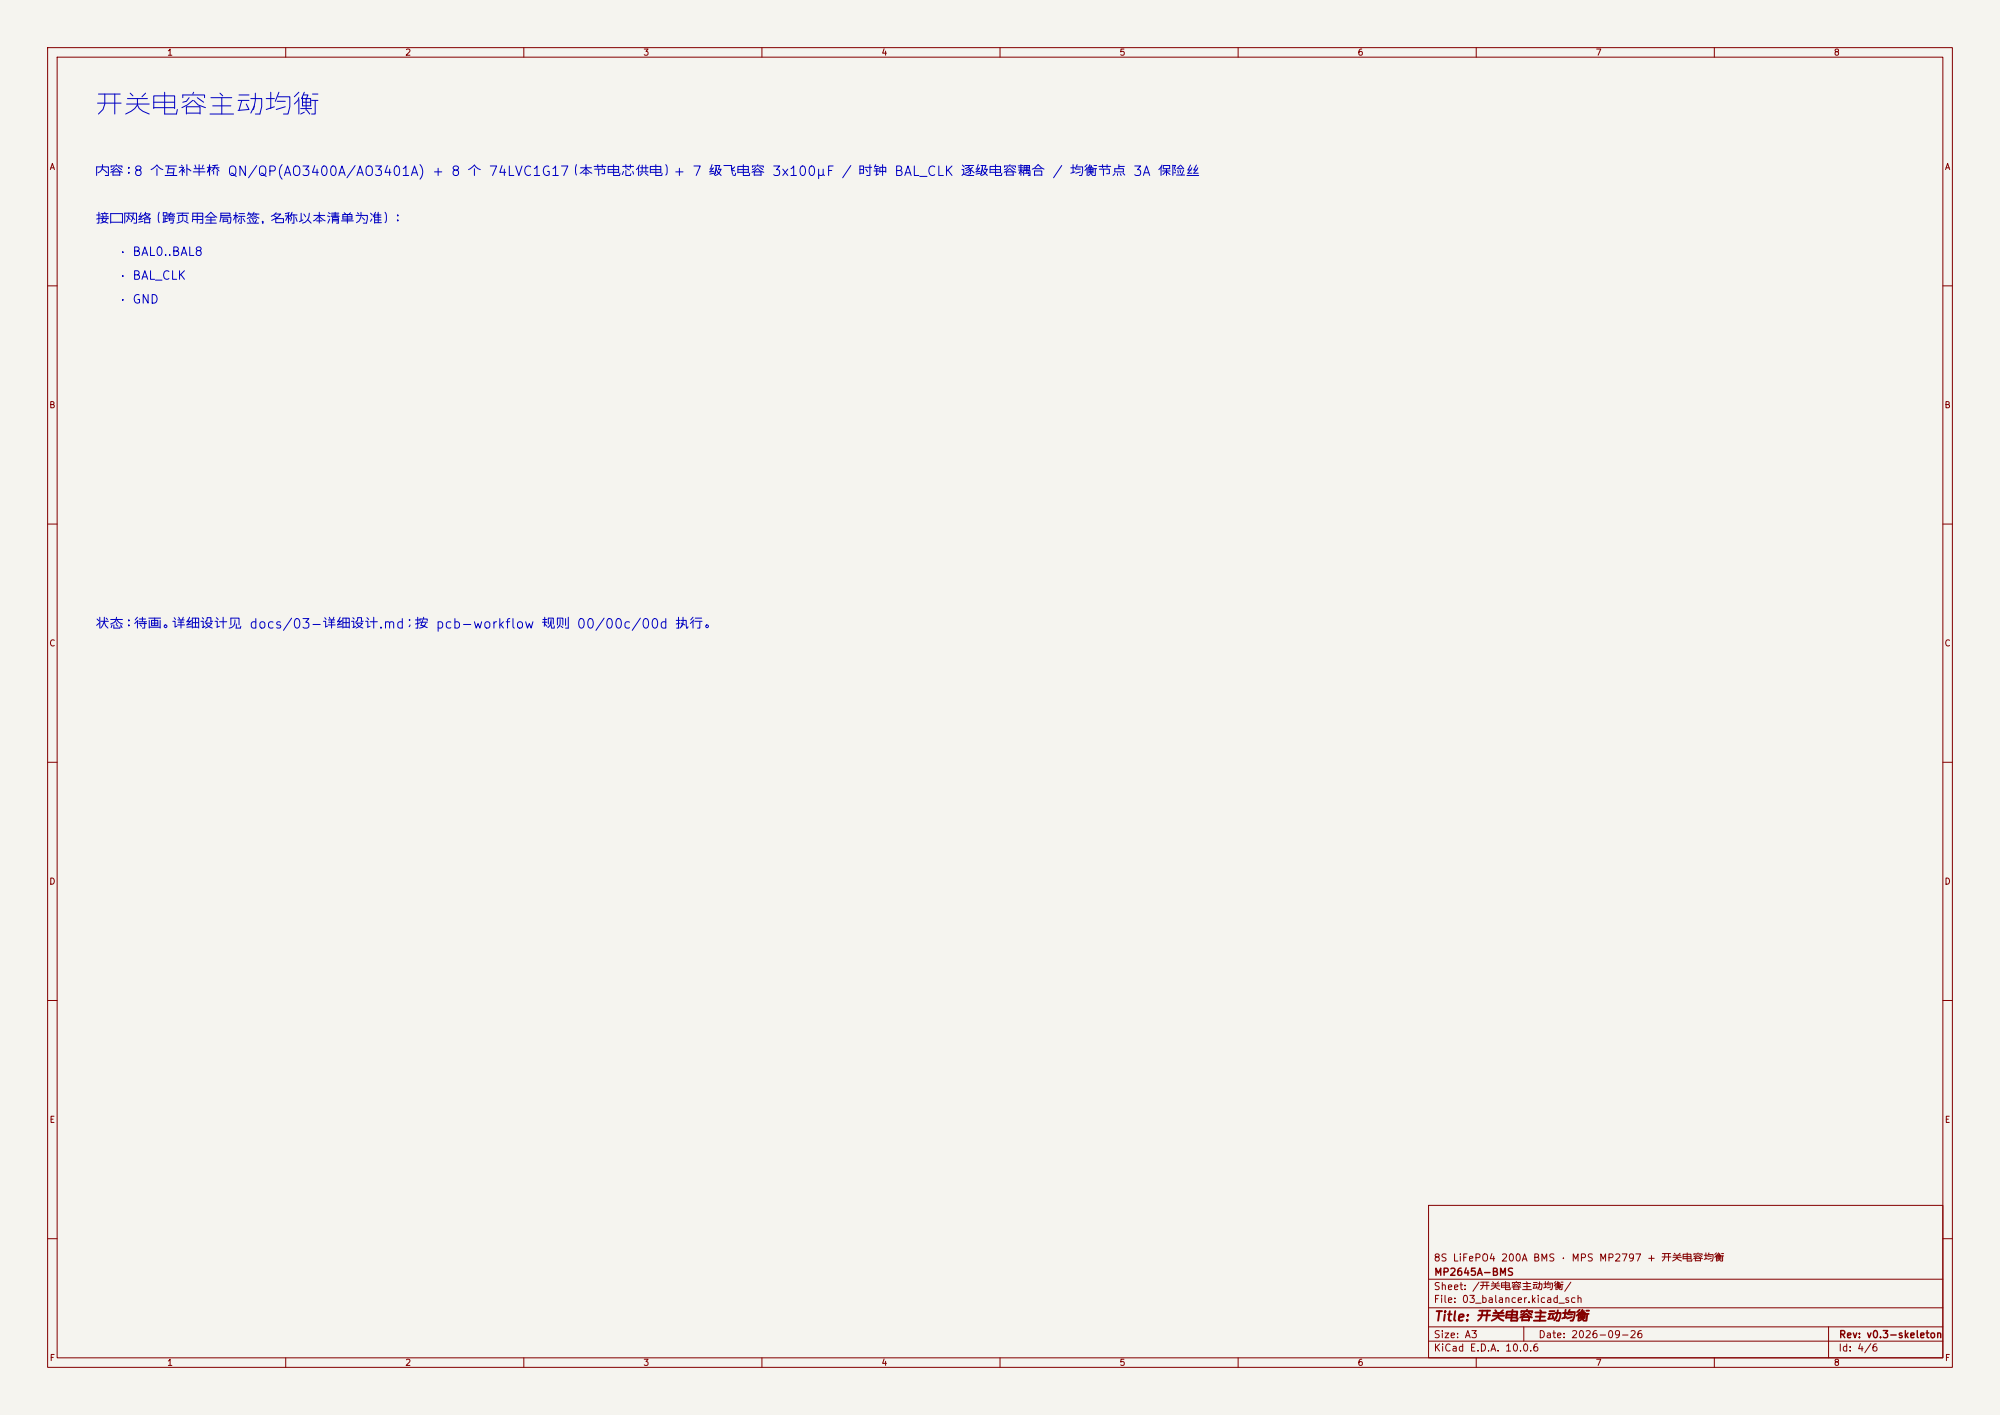
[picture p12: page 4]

内容：8 个互补半桥 QN/QP(AO3400A/AO3401A) + 8 个 74LVC1G17（本节电芯供电）+ 7 级飞电容 3x100µF / 时钟 BAL_CLK 逐级电容耦合 / 均衡节点 3A 保险丝

状态：待画。详细设计见 docs/03-详细设计.md；按 pcb-workflow 规则 00/00c/00d 执行。


LMR16006X 600kHz（Tokmas）非同步 buck；D7 续流必需；SHDN 悬空=常开；输入 C40 47µF/63V + C42/C44 2×1µF/100V

R42 56Ω 熔断电阻与 C40 构成输入 RC：限上电浪涌与短路电流，VIN_F 短路时受控开路；C45 100nF/100V 贴 VIN（Tokmas 手册 p14）


CAN_H_X CAN_L_X KEY MCU 与通讯（CH32V203C8T6 + CAN）

BAL_CLK=PA8(TIM1_CH1 75kHz)+R52 100k 下拉；PRECHG_EN=PA1+R51 100k 下拉；AFE_WAKE=MP2797 NSHDN(PB5 开漏，上拉 R_WAK 在 02 页)；

差分对 120Ω（规则 0c：J7→U8→L2/R56/R57→U7 直通道，顶层不换层）；JP1 插帽接入 120Ω 终端，拔帽不用；J8 DNP，下载器勿从 1 脚供电。

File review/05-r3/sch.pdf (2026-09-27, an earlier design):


层次结构（v0.3 骨架）：主动均衡为分立开关电容；电路按 datasheets/ 手册逐 IC 核对后再画

8S LiFePO4 200A BMS · MPS MP2797 + 开关电容均衡
MP2645A-BMS
Sheet: /
File: mp2645a-bms.kicad_sch
Title: 8S LFP 200A BMS — 总图

Size: A3 | Rev: v0.3-skeleton | F Date: 2026-09-26
KiCad E.D.A. 10.0.6 | Id: 1/6


内容：B+ 熔断器 / CHG、DSG 各 8 并联 NMOS / 栅极网络与 PNP 快速关断 / 分流器 / TVS / 预充 / P+ P- 端子

状态：待画。详细设计见 docs/03-详细设计.md；按 pcb-workflow 规则 00/00c/00d 执行。


内容：电芯采样 RC / 电流采样滤波 / 4 路 NTC / 高边驱动输出 / 通讯与中断 / 被动均衡

状态：待画。详细设计见 docs/03-详细设计.md；按 pcb-workflow 规则 00/00c/00d 执行。


内容：8 个互补半桥 QN/QP(AO3400A/AO3401A) + 8 个 74LVC1G17（本节电芯供电）+ 7 级飞电容 3x100µF / 时钟 BAL_CLK 逐级电容耦合 / 均衡节点 3A 保险丝

状态：待画。详细设计见 docs/03-详细设计.md；按 pcb-workflow 规则 00/00c/00d 执行。

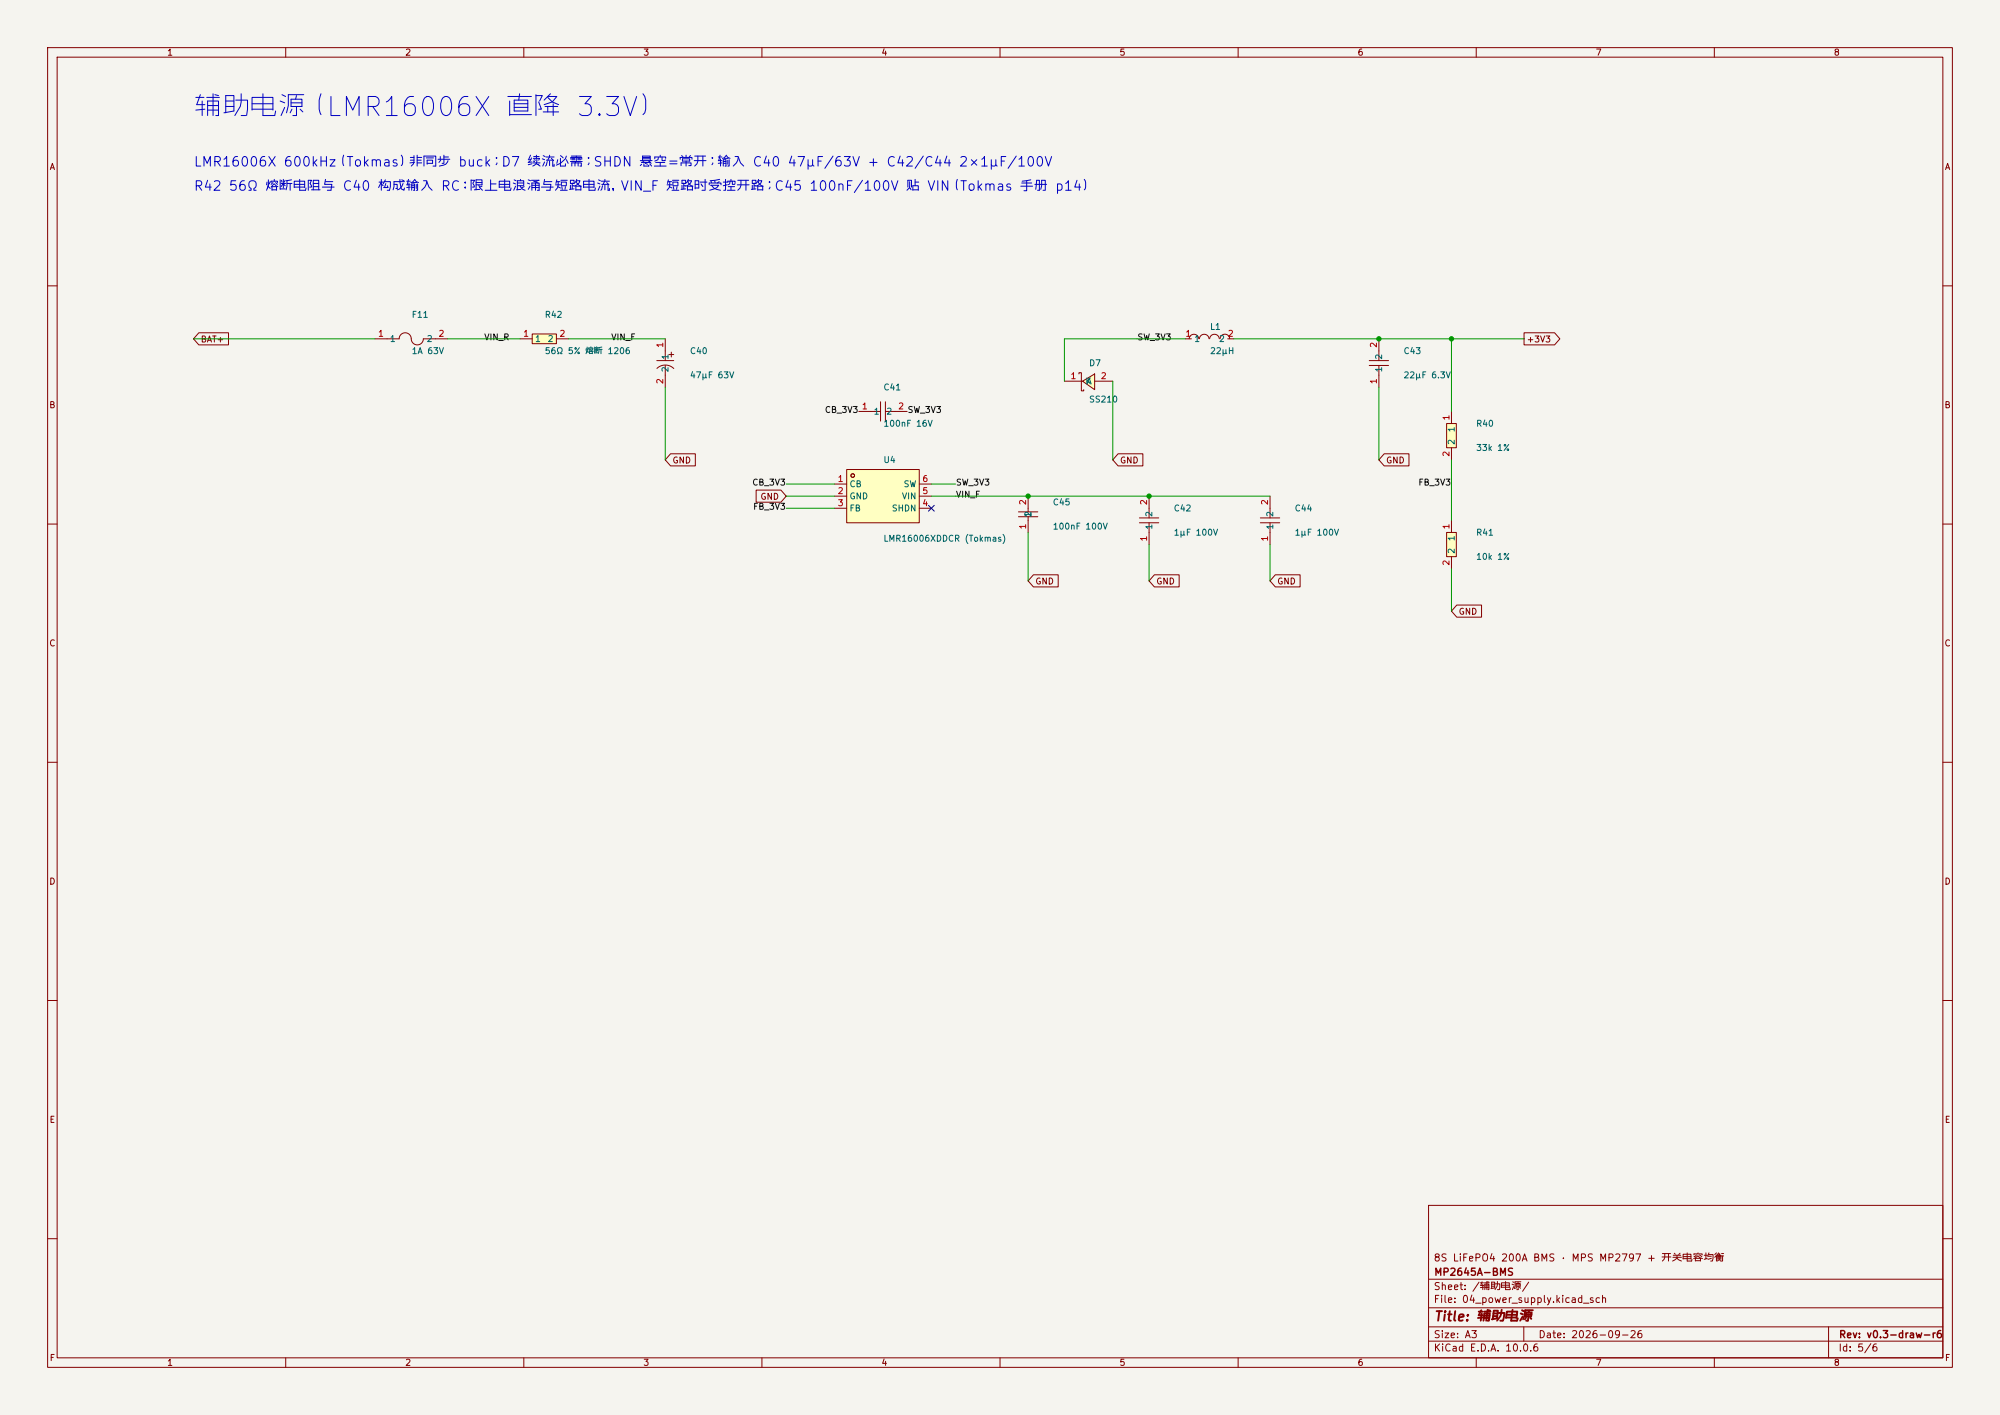
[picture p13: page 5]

LMR16006X 600kHz（Tokmas）非同步 buck；D7 续流必需；SHDN 悬空=常开；输入 C40 47µF/63V + C42/C44 2×1µF/100V

R42 56Ω 熔断电阻与 C40 构成输入 RC：限上电浪涌与短路电流，VIN_F 短路时受控开路；C45 100nF/100V 贴 VIN（Tokmas 手册 p14）

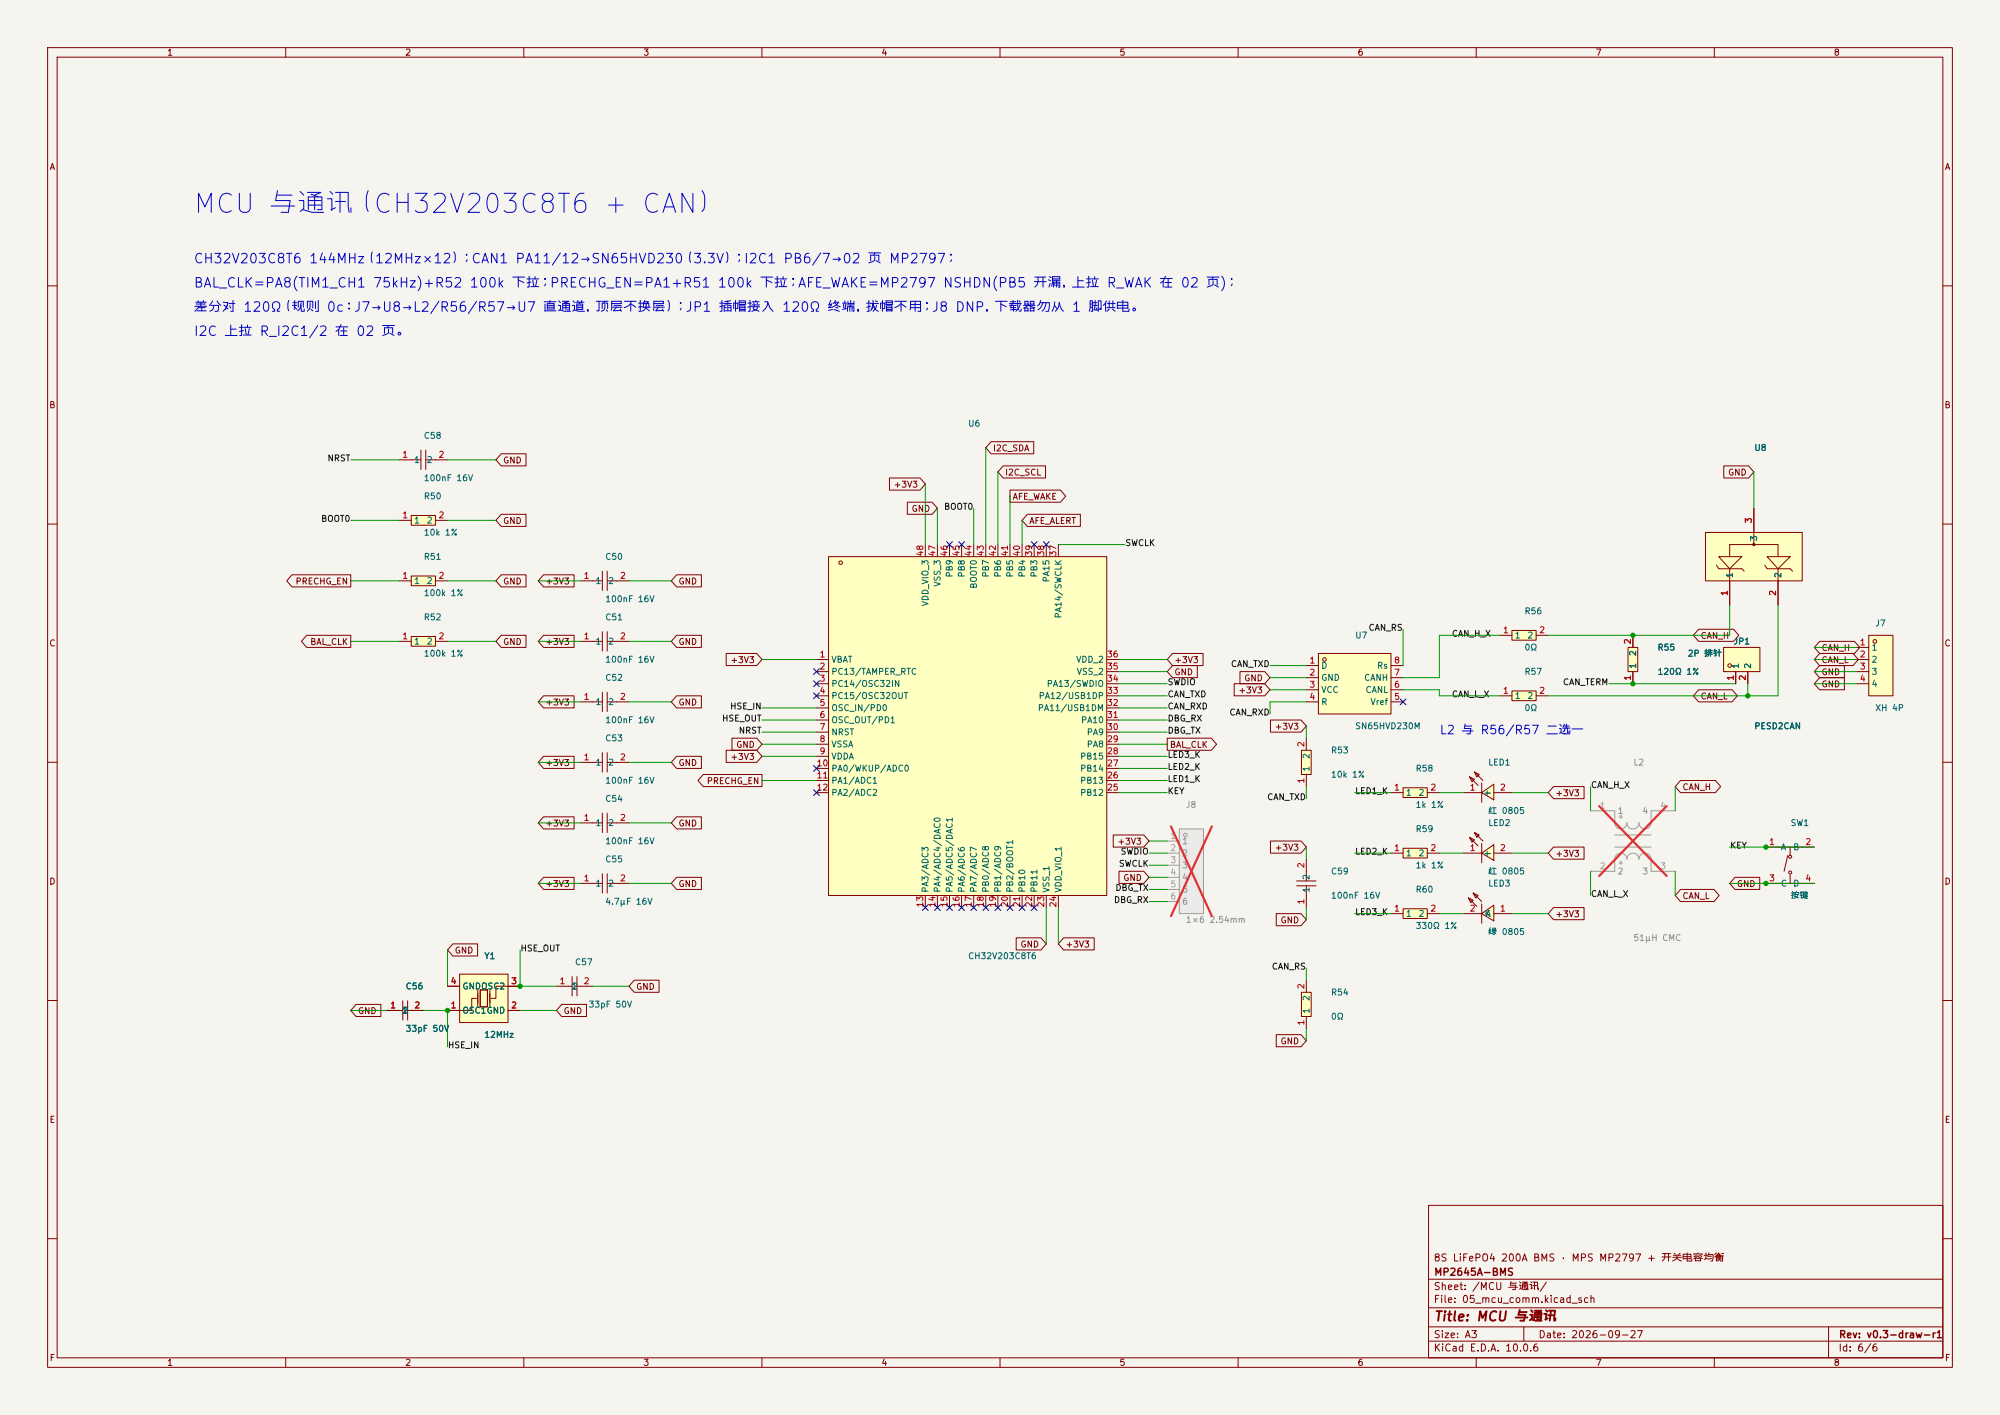
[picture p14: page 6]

CAN_H_X CAN_L_X KEY MCU 与通讯（CH32V203C8T6 + CAN）

BAL_CLK=PA8(TIM1_CH1 75kHz)+R52 100k 下拉；PRECHG_EN=PA1+R51 100k 下拉；AFE_WAKE=MP2797 NSHDN(PB5 开漏，上拉 R_WAK 在 02 页)；

差分对 120Ω（规则 0c：J7→U8→L2/R56/R57→U7 直通道，顶层不换层）；JP1 插帽接入 120Ω 终端，拔帽不用；J8 DNP，下载器勿从 1 脚供电。

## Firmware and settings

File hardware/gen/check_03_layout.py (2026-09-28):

#!/usr/bin/env python3
"""自检脚本：对 hardware/03_balancer.kicad_sch 做几何检查 1–8 + 网表检查 9（结构照搬 check_02_layout.py）。

    python3 hardware/gen/check_03_layout.py

环境变量 `BAL_HW` 可把「硬件目录」换掉（默认 hardware/）。负例验证用：把整棵硬件目录
复制到别处、人为制造缺陷，再 `BAL_HW=/tmp/neg/hardware python3 check_03_layout.py` 跑一遍，
确认检查真的会报出来（这是 obsidian-vault 的规矩：新检查不做负例验证就可能是空跑）。

与 02 页的差异有四处：
  a) 本页**不用** mirror（规格书只给了 N/P 两种管的 rot0/rot180 摆法）；pin_world /
     pin_dir_world 的 mirror 分支照抄保留，load() 仍从实例的 `(mirror y)` 读，
     只是本页实例都不带 mirror，等价于 mirror=False。
  b) 网表核对表按规格书 §3 的逐节展开写（§3.1 模板 + §3.2 的 60 个网络），不再有 U1。
  c) 分段 A 只画第 1–4 节 + 飞电容 1–3 级 + R300，所以 §3.2 里属于第 5–8 节的
     位号（U305–U308 等）在图纸上还不存在——9c 对它们**只列缺件清单，不算失败**。
  d) 本页无 GND、无电源符号（§3.2 末条），所以 9g 反过来查：网表里不许出现
     GND/+3V3/+5V 之类的电源网络。

直接解析生成的 .kicad_sch（不是 gen 脚本的数据），做八件事：
  1. 导线不许经过非端点的引脚端点；
  2. 导线不许穿过符号本体（rectangle/polyline/arc/circle 包络 + 实例坐标变换）；
  3. T 型连接必须有 junction（导线端点落在另一段导线内部、或引脚处多段导线相接）；
  4. 标签/全局标签/说明文字不许压在导线上；
  5. 同一符号的引脚名文字盒不许互相粘连；
  6. 可见字段（Reference/Value）不许压在自己的本体上；
  7. 不同符号的「本体 + 可见字段 + 引脚名」图元盒两两不许相交（第 3 轮新增，
     第 2 轮就是因为缺这一项，R55 的位号被 JP1 本体压住没人发现）；
  8. 用 kicad-cli 导出 PDF、pymupdf 读渲染文字，复核字段文字真的画在预测位置、
     且不同符号的字段文字互不相交、字段文字不落在别的符号本体上（第 3 轮新增，
     补第 1 轮任务书 §4.4 的「文字 bbox 不重叠（pymupdf）」）。
  9. 以**根图**为准导出网表，逐脚核对已画的每个端子对规格书 §3.1/§3.2 的预期网络
     （分段 A 新增）。检查 1–8 全是「我自己算的几何 vs 我自己算的几何」，对符号变换
     不敏感——02 页实测把 pin_world 的 mirror 分支屏蔽掉，1–8 依旧全 PASS；
     检查 9 量的是 KiCad 自己连出来的网，才真正兜得住「接错网」。9 里还带
     9b（NC 真悬空）/9c（外围件端子，未画件列缺件清单）/9d（DNP 标志）/9f（位号合法性）/
     9g（本页不许出现电源网络）/9h（DNP 值里写明）/9i（Footprint 与 LCSC 齐备）/
     9j（网络→脚集合反查）/9l（本页网络全集）/9m（网络类）/9n（本页 ERC=0）/
     9o（8 节同构）/9p（值·LCSC·库符号：第 2 轮换料表 + 对 docs/02-BOM.csv 逐件核）/
     9q（二极管 K/A 方向：库符号图形 + §3.2 网络，第 2 轮新增）几小项。
 10. 标签/说明文字的**墨迹盒**不许压到器件本体图元上（第 2 轮新增）；
 11. 两段标签/说明文字不许叠在一起（用「横向重叠率 + 锚Δx」区分「真叠」与
     「同列上下紧排」，第 2 轮新增）；
 12. 可见字段不许离自己的器件比离别人的器件还远（第 2 轮新增）；
 13. 两段说明文字不许互相压住（第 2 轮新增，生成域，比渲染域的 8e 早一步）。

检查 10–13 用的是**墨迹**几何（见 ink_bbox 的标定说明），1–7 用的是 text_width 的
「字符前进宽度」近似（相对量够用，判「压没压上」不够）。

全部通过 → exit 0；任何一条失败 → 打印 FAIL 并 exit 1。检查 8 需要 kicad-cli + pymupdf，
检查 9 需要 kicad-cli + 根图，缺工具时各自打印 SKIP。
"""
from __future__ import annotations

import csv
import json
import os
import re
import shutil
import subprocess
import sys
import tempfile
import xml.etree.ElementTree as ET

HW = os.environ.get("BAL_HW") or os.path.join(os.path.dirname(os.path.abspath(__file__)), "..")
SCH = os.path.join(HW, "03_balancer.kicad_sch")
ROOT_SCH = os.path.join(HW, "mp2645a-bms.kicad_sch")
# 检查 9p 的外部口径：docs/02-BOM.csv 是本页器件值的**另一份独立记录**（贴片厂吃的那份）。
# 用 BAL_HW 指向快照时（负例验证）BOM 通常不存在，9p 的 BOM 那一半自动降级成 SKIP。
BOM = os.environ.get("BAL_BOM") or os.path.join(os.path.dirname(os.path.abspath(HW)), "docs", "02-BOM.csv")

EPS = 1e-3

# 图纸尺寸（A3，见生成器的 `(paper "A3")`）与文字可用区留边。留边就是**实测的图框线**：
# 从 PDF 的矢量图元里量出来是 x 10.0→410.0、y 10.0→287.0（原来拍脑袋写 8.0，比图框宽
# 2mm，会把「刚压线」漏过去）。图元盒另有检查 3/4 兜着，这里只管文字。
PAGE_W, PAGE_H = 420.0, 297.0
PAGE_MARGIN = 10.0
# 图框标题栏：KiCad 自己管的文字（页号、版本、我们的 comment 行）按图框模板定位，实测
# 最后一行的右边界到 x≈418.9 —— **越过了 410 的边框线**。那不是生成器摆的，也不是
# 「画出去被裁掉」，单独开一个豁免区。区域取右下角，生成器的内容区不会伸到这里
# （全页最右的内容是 x≈402 的字段文字，y < 200）。
TITLE_BLOCK = (295.0, 250.0, 420.0, 297.0)


# ---------------------------------------------------------------------------
# S-表达式解析（够用即可）
# ---------------------------------------------------------------------------
def tokenize(s: str):
    toks, i, n = [], 0, len(s)
    while i < n:
        c = s[i]
        if c in "()":
            toks.append(c)
            i += 1
        elif c == '"':
            j = i + 1
            while j < n:
                if s[j] == "\\":
                    j += 2
                elif s[j] == '"':
                    break
                else:
                    j += 1
            toks.append(s[i:j + 1])
            i = j + 1
        elif c.isspace():
            i += 1
        else:
            j = i
            while j < n and not s[j].isspace() and s[j] not in "()":
                j += 1
            toks.append(s[i:j])
            i = j
    return toks


def parse(toks):
    i = 0

    def _p():
        nonlocal i
        if toks[i] != "(":
            v = toks[i]
            i += 1
            return v
        i += 1
        node = []
        while toks[i] != ")":
            node.append(_p())
        i += 1
        return node

    return _p()


def unq(s):
    if isinstance(s, str) and len(s) >= 2 and s[0] == '"' and s[-1] == '"':
        return s[1:-1]
    return s


def child(node, key):
    for c in node:
        if isinstance(c, list) and c and c[0] == key:
            return c
    return None


def children(node, key):
    return [c for c in node if isinstance(c, list) and c and c[0] == key]


# ---------------------------------------------------------------------------
# 提取图元
# ---------------------------------------------------------------------------
def pin_world(px, py, rot, ix, iy, mirror=False):
    """符号局部坐标 → 世界坐标。mirror=True 表示实例带 `(mirror y)`（先翻局部 x 再旋转）。"""
    if mirror:
        ix = -ix
    if rot == 0:
        return (px + ix, py - iy)
    if rot == 90:
        return (px - iy, py - ix)
    if rot == 180:
        return (px - ix, py + iy)
    if rot == 270:
        return (px + iy, py + ix)
    raise ValueError(rot)


# ---------------------------------------------------------------------------
# 文字几何（近似）：为「标签文字 vs 导线 / 引脚名 vs 引脚名 / 字段 vs 本体」检查服务
# ---------------------------------------------------------------------------
def font_size(eff):
    """effects → (高, 宽)，默认 1.27。"""
    h = w = 1.27
    if eff:
        f = child(eff, "font")
        if f:
            s = child(f, "size")
            if s and len(s) >= 3:
                h, w = float(s[1]), float(s[2])
    return h, w


def justify(eff):
    """effects → (水平, 垂直) 对齐。

    KiCad 文件格式里不写 justify 节点就表示**居中对齐**（所以 KiCad 写左对齐时一定会显式写
    `(justify left)`）。第 3 轮 JP1 的位号改成居中后就是这个样子 —— 渲染实测「JP1」画在
    363.91–367.36（中心 365.64，锚点 365.76），证实默认确实是水平居中，不是左对齐。
    生成脚本里的标签/说明文字都显式写 justify，走不到这个默认值。
    """
    hj, vj = "center", "center"
    if eff:
        j = child(eff, "justify")
        if j and len(j) >= 2:
            parts = unq(j[1]).split()
            if parts and parts[0] in ("left", "right", "center"):
                hj = parts[0]
            if len(parts) > 1 and parts[1] in ("top", "bottom"):
                vj = parts[1]
    return hj, vj


def text_width(txt, h):
    """近似文字宽度：CJK 按全角（≈h），其余按 0.6h。"""
    w = 0.0
    for ch in txt:
        w += h if ord(ch) > 0x2E80 else 0.6 * h
    return w


def text_bbox(x, y, txt, h, hj, vj):
    """水平文字（有效角度 0/180）的近似包围盒；锚点 (x, y)。"""
    tw = text_width(txt, h)
    if hj == "right":
        x0, x1 = x - tw, x
    elif hj == "center":
        x0, x1 = x - tw / 2, x + tw / 2
    else:
        x0, x1 = x, x + tw
    if vj == "top":
        y0, y1 = y, y + h
    elif vj == "bottom":
        y0, y1 = y - h, y
    else:
        y0, y1 = y - h / 2, y + h / 2
    return (x0, y0, x1, y1)


def vtext_bbox(x, y, txt, h):
    """竖排文字（有效角度 90/270）的近似包围盒：宽 = 字高 h，高 = 文字宽度。
    本页的字段都写成 fa=(360-rot)%360，有效角度恒为 0，这个分支跑不到；
    留着是为了「角度不是 0 就静默跳过」这种漏检不再发生。"""
    tw = text_width(txt, h)
    return (x - h / 2, y - tw / 2, x + h / 2, y + tw / 2)


# --- 墨迹几何（第 2 轮新增，检查 10–13 用）----------------------------------
# 检查 1–7 拿 text_width（0.6h/字）比「压没压上」是不够的：那是**字符前进宽度**，比真实
# 墨迹小约一半（实测 1.8 号的「SRN_F」墨迹 5.87mm，text_width 只给 3.81mm），拿同一把
# 偏小的尺子量两边时近距缺陷会被整片漏掉。下面两个函数是**渲染实测标定**出来的：
#   * 墨迹宽 = CJK 1.50h/字、其余 0.92h/字（1.27 号拉丁实测 0.92h/字）；
#   * 纵向锚点：`(justify … top)` 的墨迹 = y−0.25h … y+1.25h（§9 标题锚 43.18、渲染实测
#     42.62–46.16；§10 说明锚 48.26、实测 47.77–50.16），bottom 对称；居中（标签/字段）
#     实测 ≈ y±0.75h（另有 ~0.2mm 系统偏移，见下面 GLBL_PAD 的说明）。
# 已知误差：全局标签的文字画在图形框**里面**、离锚点还有一段框长，实测比「右对齐到锚点」
# 的模型再往左 ~2.0mm（C221 的 GND：模型 351.8–355.3，渲染 355.15–359.02 的实测是
# 355.15 起）。所以全局标签的墨迹盒横向额外放宽 GLBL_PAD —— 宁可把缺陷报出来。
INK_CJK, INK_LATIN = 1.50, 0.92
GLBL_PAD = 2.0


def ink_width(txt, h):
    """墨迹宽度。"""
    return sum(INK_CJK * h if ord(c) > 0x2E80 else INK_LATIN * h for c in txt)


def ink_bbox(x, y, txt, h, hj, vj="center", pad=0.0):
    """水平文字的墨迹盒（锚点 (x, y)）。"""
    tw = ink_width(txt, h)
    if hj == "right":
        x0, x1 = x - tw, x
    elif hj == "center":
        x0, x1 = x - tw / 2, x + tw / 2
    else:
        x0, x1 = x, x + tw
    if vj == "top":
        y0, y1 = y - 0.25 * h, y + 1.25 * h
    elif vj == "bottom":
        y0, y1 = y - 1.25 * h, y + 0.25 * h
    else:
        y0, y1 = y - 0.75 * h, y + 0.75 * h
    return (x0 - pad, y0, x1 + pad, y1)


def box_gap(a, b):
    """两盒的边到边距离（相交 = 0）。字段归属检查要比「离谁更近」，用 2D 间距。"""
    dx = max(b[0] - a[2], a[0] - b[2], 0.0)
    dy = max(b[1] - a[3], a[1] - b[3], 0.0)
    return (dx * dx + dy * dy) ** 0.5


def pin_dir_world(inst_rot, pin_rot, mirror=False):
    """引脚方向（尖端→本体）在世界坐标下的单位向量。"""
    dx = {0: 1, 90: 0, 180: -1, 270: 0}[pin_rot % 360]
    dy = {0: 0, 90: 1, 180: 0, 270: -1}[pin_rot % 360]
    if mirror:
        dx = -dx  # (mirror y)：局部 x 取反（与 pin_world 一致）
    wx, wy = dx, -dy  # 符号局部 y 向上 → 世界 y 向下
    if inst_rot == 90:
        wx, wy = -wy, wx
    elif inst_rot == 180:
        wx, wy = -wx, -wy
    elif inst_rot == 270:
        wx, wy = wy, -wx
    return wx, wy


def pin_name_bbox(bx, by, wx, wy, tw, h):
    """引脚名以本体端 (bx, by) 为锚、沿 (wx, wy) 向本体内延伸。
    水平引脚名=横排文字；顶/底引脚名=竖排文字（KiCad 实际按竖排渲染）。"""
    if wx > 0:
        x0, x1 = bx, bx + tw
        y0, y1 = by - h / 2, by + h / 2
    elif wx < 0:
        x0, x1 = bx - tw, bx
        y0, y1 = by - h / 2, by + h / 2
    elif wy > 0:  # 顶边引脚（向下指）：竖排名字向下延伸
        x0, x1 = bx - h / 2, bx + h / 2
        y0, y1 = by, by + tw
    else:  # wy < 0：底边引脚（向上指）：竖排名字向上延伸
        x0, x1 = bx - h / 2, bx + h / 2
        y0, y1 = by - tw, by
    return (x0, y0, x1, y1)


def bbox_overlap(b1, b2, eps=EPS):
    return not (b1[2] < b2[0] - eps or b2[2] < b1[0] - eps or
                b1[3] < b2[1] - eps or b2[3] < b1[1] - eps)


def bbox_overlap_xy(b1, b2, xeps, yeps):
    """两个轴分别给容差（bbox_overlap 两轴共用一个 eps）。eps 为负 = 允许的重叠量。

    pymupdf 的 span bbox **不是墨迹**：它含字体的上/下伸部。同一段文字块里相邻两行
    （行距 2.54、字号 1.8）的 bbox 会互相压 0.36mm；size 2.4 的表头压到下一行 size 1.8
    的正文字上更是压 0.93mm。所以「说明文字之间」的比对**纵向必须放宽到 ~1.2mm**，
    否则整页的说明文字会自己告自己；横向没这个问题，保持严格。
    """
    return not (b1[2] < b2[0] - xeps or b2[2] < b1[0] - xeps or
                b1[3] < b2[1] - yeps or b2[3] < b1[1] - yeps)


def load():
    txt = open(SCH, encoding="utf-8").read()
    root = parse(tokenize(txt))

    # --- 嵌入库符号：符号名 → {pin_number: (ix, iy)}，符号名 → 本体点列表 ---
    lib_pins = {}
    lib_pinmeta = {}
    lib_body = {}
    libs = child(root, "lib_symbols")
    for sym in children(libs, "symbol"):
        topname = unq(sym[1]) if len(sym) > 1 else None  # "jlc:NAME"
        pins = {}
        pinmeta = {}
        bodypts = []
        for sub in sym:
            if not (isinstance(sub, list) and sub and sub[0] == "symbol"):
                continue
            for el in sub:
                if not isinstance(el, list):
                    continue
                if el[0] == "pin":
                    at = child(el, "at")
                    num = child(el, "number")
                    if at and num:
                        ix, iy, _rot = float(at[1]), float(at[2]), float(at[3])
                        pins[unq(num[1])] = (ix, iy)
                        nm = child(el, "name")
                        ln = child(el, "length")
                        pinmeta[unq(num[1])] = {
                            "name": unq(nm[1]) if nm else "",
                            "ix": ix, "iy": iy, "rot": _rot,
                            "len": float(ln[1]) if ln else 2.54,
                        }
                elif el[0] == "rectangle":
                    st, en = child(el, "start"), child(el, "end")
                    bodypts += [(float(st[1]), float(st[2])), (float(st[1]), float(en[2])),
                                (float(en[1]), float(st[2])), (float(en[1]), float(en[2]))]
                elif el[0] == "polyline":
                    # 注意：xy 是 (pts ...) 的子节点，不是 polyline 的直接子节点。
                    # 第 2 轮这里漏了 pts 一层，导致只有 polyline 的符号（0402 电容/电阻、
                    # LED、Y1、L2）本体盒恒为 None，检查 2/6 对它们等于没跑。
                    pts_node = child(el, "pts")
                    for xy in (children(pts_node, "xy") if pts_node else []):
                        bodypts.append((float(xy[1]), float(xy[2])))
                elif el[0] == "arc":
                    for k in ("start", "mid", "end"):
                        p = child(el, k)
                        if p:
                            bodypts.append((float(p[1]), float(p[2])))
                elif el[0] == "circle":
                    c = child(el, "center")
                    r = child(el, "radius")
                    if c and r:
                        cx, cy, rr = float(c[1]), float(c[2]), float(r[1])
                        bodypts += [(cx - rr, cy), (cx + rr, cy), (cx, cy - rr), (cx, cy + rr)]
        lib_pins[topname] = pins
        lib_pinmeta[topname] = pinmeta
        lib_body[topname] = bodypts

    # --- 实例：位号 → (lib_id, x, y, rot, [pin numbers])；可见字段（Reference/Value）文字盒 ---
    instances = {}
    prop_texts = {}  # ref → [(x0, y0, x1, y1, propname)]
    for sym in children(root, "symbol"):
        lib_id = child(sym, "lib_id")
        at = child(sym, "at")
        if not (lib_id and at):
            continue
        ref = None
        insts = child(sym, "instances")
        if insts:
            for p in insts:
                if isinstance(p, list) and p and p[0] == "project":
                    for q in p:
                        if isinstance(q, list) and q and q[0] == "path":
                            r = child(q, "reference")
                            if r:
                                ref = unq(r[1])
        if not ref:
            # 兜底：用 symbol 自身没有 reference 时跳过
            continue
        nums = [unq(p[1]) for p in children(sym, "pin")]
        mir = child(sym, "mirror")
        mirror = bool(mir) and "y" in [unq(v) for v in mir[1:]]
        instances[ref] = (unq(lib_id[1]), float(at[1]), float(at[2]), float(at[3]),
                          nums, mirror)
        for prop in children(sym, "property"):
            pname = unq(prop[1]) if len(prop) > 1 else ""
            if pname not in ("Reference", "Value"):
                continue
            pval = unq(prop[2]) if len(prop) > 2 else ""
            pat = child(prop, "at")
            peff = child(prop, "effects")
            if pat and pval:
                # 有效角度 = 字段存储角度 + 符号实例旋转（KiCad 就是这么渲染的）：
                # 符号 rot=90 的字段存 270°，实际画出来是水平的（pymupdf dir=(1,0) 实测）。
                # 第 2 轮这里写的是「存储角度 % 360 == 0 才查」，把 R55/JP1 这些 rot=90 符号的
                # 字段全跳过了 —— 结果 P1 的重叠正好落在漏检区里。
                ang = float(pat[3]) if len(pat) > 3 else 0.0
                eff = int(round(ang + float(at[3]))) % 360
                h, _ = font_size(peff)
                hj, vj = justify(peff)
                if eff in (0, 180):
                    box = text_bbox(float(pat[1]), float(pat[2]), pval, h, hj, vj)
                else:
                    box = vtext_bbox(float(pat[1]), float(pat[2]), pval, h)
                # 后 4 项给检查 8 用：锚点、水平对齐、文字内容（宽度估算偏小，见 text_width）；
                # 末项字高给检查 12 的墨迹盒用（检查 10–13 一律按墨迹量，见 ink_bbox）。
                prop_texts.setdefault(ref, []).append(
                    (*box, pname, float(pat[1]), float(pat[2]), hj, pval, h))

    # --- 导线 ---
    wires = []
    for w in children(root, "wire"):
        pts = child(w, "pts")
        xys = children(pts, "xy")
        if len(xys) == 2:
            wires.append(((float(xys[0][1]), float(xys[0][2])),
                          (float(xys[1][1]), float(xys[1][2]))))

    # --- 结点 ---
    junctions = set()
    for j in children(root, "junction"):
        at = child(j, "at")
        if at:
            junctions.add((round(float(at[1]), 4), round(float(at[2]), 4)))

    # --- 引脚世界坐标 ---
    pin_world_pos = {}  # (ref, num) -> (x, y)
    for ref, (lib, x, y, rot, nums, mir) in instances.items():
        lp = lib_pins.get(lib, {})
        for num in nums:
            if num in lp:
                ix, iy = lp[num]
                pin_world_pos[(ref, num)] = pin_world(x, y, rot, ix, iy, mir)

    # --- 本体世界包围盒 ---
    body_boxes = {}  # ref -> (xmin, ymin, xmax, ymax)
    for ref, (lib, x, y, rot, nums, mir) in instances.items():
        pts = lib_body.get(lib, [])
        if not pts:
            body_boxes[ref] = None
            continue
        ws = [pin_world(x, y, rot, ix, iy, mir) for (ix, iy) in pts]
        xs = [p[0] for p in ws]
        ys = [p[1] for p in ws]
        body_boxes[ref] = (min(xs), min(ys), max(xs), max(ys))

    # --- 标签/全局标签/说明文字：文字盒 + 锚点 + 字高/对齐（后三项给检查 10/11/13 的墨迹盒）---
    labels = []  # (x0, y0, x1, y1, ax, ay, txt, kind, h, hj, vj)
    for kind, key in [("label", "label"), ("global_label", "global_label")]:
        for node in children(root, key):
            at = child(node, "at")
            eff = child(node, "effects")
            txt = unq(node[1]) if len(node) > 1 else ""
            if at and txt:
                h, _ = font_size(eff)
                hj, vj = justify(eff)
                labels.append((*text_bbox(float(at[1]), float(at[2]), txt, h, hj, vj),
                               float(at[1]), float(at[2]), txt, kind, h, hj, vj))
    for node in children(root, "text"):
        at = child(node, "at")
        eff = child(node, "effects")
        txt = unq(node[1]) if len(node) > 1 else ""
        if at and txt:
            h, _ = font_size(eff)
            hj, vj = justify(eff)
            labels.append((*text_bbox(float(at[1]), float(at[2]), txt, h, hj, vj),
                           float(at[1]), float(at[2]), txt, "text", h, hj, vj))

    # --- 引脚名世界文字盒（非空引脚名，近似本体端位置）---
    pin_name_boxes = {}  # ref → [(x0, y0, x1, y1, num)]
    for ref, (lib, x, y, rot, nums, mir) in instances.items():
        meta = lib_pinmeta.get(lib, {})
        for num in nums:
            m = meta.get(num)
            if not m or not m["name"]:
                continue
            tip = pin_world(x, y, rot, m["ix"], m["iy"], mir)
            wx, wy = pin_dir_world(rot, m["rot"], mir)
            bx = tip[0] + m["len"] * wx
            by = tip[1] + m["len"] * wy
            tw = text_width(m["name"], 1.27)
            pin_name_boxes.setdefault(ref, []).append(
                (*pin_name_bbox(bx, by, wx, wy, tw, 1.27), num))

    return wires, junctions, pin_world_pos, body_boxes, instances, labels, prop_texts, pin_name_boxes


# ---------------------------------------------------------------------------
# 几何工具
# ---------------------------------------------------------------------------
def on_segment(p, a, b, inclusive=False):
    """p 是否在轴对齐线段 ab 上（默认严格内部）。"""
    ax, ay = a
    bx, by = b
    px, py = p
    if abs(ax - bx) < EPS:  # 竖直
        if abs(px - ax) > EPS:
            return False
        lo, hi = min(ay, by), max(ay, by)
        return lo - EPS <= py <= hi + EPS and ((not inclusive) and (py > lo + EPS) and (py < hi - EPS)) if not inclusive else True
    if abs(ay - by) < EPS:  # 水平
        if abs(py - ay) > EPS:
            return False
        lo, hi = min(ax, bx), max(ax, bx)
        if inclusive:
            return lo - EPS <= px <= hi + EPS
        return lo + EPS < px < hi - EPS
    # 斜线：投影参数
    dx, dy = bx - ax, by - ay
    t = ((px - ax) * dx + (py - ay) * dy) / (dx * dx + dy * dy)
    if inclusive:
        ok = -EPS <= t <= 1 + EPS
    else:
        ok = EPS < t < 1 - EPS
    if not ok:
        return False
    qx, qy = ax + t * dx, ay + t * dy
    return abs(qx - px) < EPS and abs(qy - py) < EPS


def seg_bbox_intersect(a, b, box):
    """轴对齐线段与轴对齐 box 是否相交。"""
    xmin, ymin, xmax, ymax = box
    ax, ay = a
    bx, by = b
    # 线段包围盒
    sx0, sx1 = min(ax, bx), max(ax, bx)
    sy0, sy1 = min(ay, by), max(ay, by)
    if sx1 < xmin - EPS or sx0 > xmax + EPS or sy1 < ymin - EPS or sy0 > ymax + EPS:
        return False
    # 水平/竖直直接判
    if abs(ay - by) < EPS:
        return ymin - EPS <= ay <= ymax + EPS and sx0 <= xmax + EPS and sx1 >= xmin - EPS
    if abs(ax - bx) < EPS:
        return xmin - EPS <= ax <= xmax + EPS and sy0 <= ymax + EPS and sy1 >= ymin - EPS
    # 斜线：对 box 四边做相交（简单化，用中点采样 + 端点）
    pts = [(ax, ay), (bx, by), ((ax + bx) / 2, (ay + by) / 2)]
    for px, py in pts:
        if xmin - EPS <= px <= xmax + EPS and ymin - EPS <= py <= ymax + EPS:
            return True
    return False


# ---------------------------------------------------------------------------
# 检查 8：渲染复核（kicad-cli 导出 PDF + pymupdf 读真实文字盒）
# ---------------------------------------------------------------------------
MM = 72.0 / 25.4  # PDF 用户单位(pt) → mm
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

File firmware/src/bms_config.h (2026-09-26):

/*
 * 8S LiFePO4 200A BMS —— 保护与均衡参数
 * 单位: 电压 mV, 电流 A(充电为正, 放电为负), 温度 0.1°C, 时间 ms
 *
 * 注意: 短路(SCP)与一级过流由 MP2797 硬件比较器完成(µs 级),
 *       这里的软件阈值是 MCU 侧的二级/慢速保护, 必须比硬件阈值更"宽松"
 *       或与之一致, 不能依赖软件做短路保护。
 */
#ifndef BMS_CONFIG_H
#define BMS_CONFIG_H

#define BMS_CELLS               8
#define BMS_NTC_CH              4   /* 0:电芯1 1:电芯2 2:MOSFET 3:分流器/环境 */
#define BMS_TICK_MS             100

/* ---- 单体电压 ---- */
#define CELL_OV_ALARM_MV        3600
#define CELL_OV_TRIP_MV         3650
#define CELL_OV_RECOVER_MV      3400
#define CELL_OV_DELAY_MS        1000

#define CELL_UV_ALARM_MV        2800
#define CELL_UV_TRIP_MV         2500
#define CELL_UV_RECOVER_MV      2900
#define CELL_UV_DELAY_MS        1000

#define CELL_DIFF_ALARM_MV      300

/* ---- 电流 (软件二级, 硬件 SCP=800A/200us, OCD 硬件=400A/10ms 在 MP2797 寄存器中配置) ---- */
#define OCD1_TRIP_A             220     /* 持续放电上限 200A + 10% */
#define OCD1_DELAY_MS           10000
#define OCD2_TRIP_A             300
#define OCD2_DELAY_MS           1000
#define OCC_TRIP_A              132     /* 电芯充电上限 1C = 120A（120Ah）+ 10% */
#define OCC_DELAY_MS            3000
#define OC_RECOVER_MS           30000   /* 过流后自动重试间隔, 或负载移除 */

/* ---- 温度 (0.1°C) ---- */
#define CHG_OT_TRIP_DC          550
#define CHG_OT_RECOVER_DC       500
#define CHG_UT_TRIP_DC          0       /* LFP 0°C 以下禁止充电(析锂) */
#define CHG_UT_RECOVER_DC       50
#define DSG_OT_TRIP_DC          650
#define DSG_OT_RECOVER_DC       550
#define DSG_UT_TRIP_DC          (-200)
#define DSG_UT_RECOVER_DC       (-150)
#define FET_OT_TRIP_DC          1000
#define FET_OT_RECOVER_DC       800
#define TEMP_DELAY_MS           2000

/* ---- 均衡 (分立开关电容均衡 + MP2797 被动补充) ----
 * 开关电容：MCU 输出 BAL_CLK（约 75kHz 方波；每级 2×100µF 飞电容）即全部 8 个半桥同步切换，电荷按相邻两节的压差自动流动；
 * 停止时钟即停止。只能按电压拉平, 所以只在顶部区 / 长时间静置时开启。 */
#define BAL_TOP_START_MV        3400    /* LFP 平台区电压差不能反映 SOC 差, 只在顶部均衡 */
#define BAL_DIFF_START_MV       30
#define BAL_DIFF_STOP_MV        10
#define BAL_REST_DIFF_START_MV  80      /* 静置时平台区也允许均衡, 但门槛更高 */
#define BAL_REST_CURRENT_A      2       /* |I| 小于此值且持续 REST_TIME 视为静置 */
#define BAL_REST_TIME_MS        1800000 /* 30 min */
#define BAL_MIN_TEMP_DC         0
#define BAL_MAX_TEMP_DC         500
#define BAL_MAX_DIFF_MV         300     /* 压差过大（坏电芯/采样断线）时开关电容电流会很大：禁止均衡, 只告警 */
#define BAL_MIN_CELL_MV         3000    /* 半桥栅压取自本节电芯, 低于此值 MOSFET 导通不充分 */
#define BAL_PASSIVE_MIN_MV      5       /* 主动未运行时, 高于 min+5mV 的电芯由 MP2797 被动放电微调 */
#define BAL_TOP_HYST_MV         50      /* 顶部均衡退出迟滞 */

#endif

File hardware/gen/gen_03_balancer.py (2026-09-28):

#!/usr/bin/env python3
"""生成 hardware/03_balancer.kicad_sch（开关电容主动均衡，8S LiFePO4）。

幂等：同一输入跑两次输出逐字节相同（UUID 用 uuid.uuid5 按位号/用途派生）。
运行即覆盖生成 hardware/03_balancer.kicad_sch。

    python3 hardware/gen/gen_03_balancer.py

设计依据：design/03_balancer-spec.md（含 §8.1b 用户决定 2026-09-27/28；附录 A 已作废）。
本脚本按任务书分段交付：**分段 A** 画第 1–4 节（k=1..4）全部器件 + 首级时钟输入，
**分段 B** 续画第 5–8 节（右栏，整体比左栏上移 26.67mm 以避开右下角标题栏）、
余下 4 级飞电容（C334–C337 / C344–C347）、最左栏的 J6 与 F300–F308，
版面分区见下面 LAYOUT 注释与 a_components 的说明。

沿用 02 页的通用函数（read_symbol/pin_world/发射器逐字照搬）与教训：
坐标全落 1.27mm 栅格；每条 wire 只 2 点；竖放件字段角 (360-rot)%360；
引脚几何以库读数为准（parse_pins/pin_world，**P 管 AO3415A 的引脚几何与 N 管不同**：
AO3416 G=−5.08/S,D=2.54，AO3415A G=−6.35/S,D=3.81）；IC 引脚引短线 + 标签；
导线不穿本体/不经过非端点引脚；引脚处 ≥2 段导线端点相接补 junction（本脚本自动补）。

本页特有：**不含 GND、不含任何电源符号**（§8.1b U-3：VB0 不接地，首级改交流耦合）；
局部网络名一律用具体名（VB0..VB8 / X1..X8 / IN1..IN8 / DRV1..DRV8 / GNk / GPk / CLK_R），
跨节一律用局部标签，不画长导线（§7.4）。
"""
from __future__ import annotations

import os
import re
import uuid

HW = os.path.join(os.path.dirname(os.path.abspath(__file__)), "..")
JLCSYM = os.path.join(HW, "lib", "jlc", "jlc.kicad_sym")
OUT = os.path.join(HW, "03_balancer.kicad_sch")

PAGE_UUID = "249fa7f7-2571-5b26-9553-df94514122d0"   # 03 页文件自身 uuid（保持骨架现值）
ROOT_UUID = "632f74a5-cd8f-58d8-9ac1-1bfbb611d555"
SHEET_UUID = "66cc3a14-196d-5f5c-9535-d482588cd3fc"  # 根图里 Sheetfile "03_balancer.kicad_sch" 的 sheet
PATH = f"/{ROOT_UUID}/{SHEET_UUID}"

NS = uuid.UUID("249fa7f725715b269553df94514122d0")


def uid(name: str) -> str:
    return str(uuid.uuid5(NS, name))


def fmt(v: float) -> str:
    return f"{v:.2f}"


def esc(txt: str) -> str:
    return txt.replace("\\", "\\\\").replace('"', '\\"')


def read_symbol(name: str) -> str:
    s = open(JLCSYM, encoding="utf-8").read()
    key = f'(symbol "{name}"'
    start = s.index(key)
    i, depth = start, 0
    while True:
        c = s[i]
        if c == "(":
            depth += 1
        elif c == ")":
            depth -= 1
            if depth == 0:
                break
        i += 1
    block = s[start:i + 1]
    return block.replace(f'(symbol "{name}"', f'(symbol "jlc:{name}"', 1)


def symbol_props(block: str) -> dict:
    return {m.group(1): m.group(2)
            for m in re.finditer(r'\(property "([^"]+)" "([^"]*)"', block)}


def parse_pins(block: str) -> dict:
    pins = {}
    for m in re.finditer(
        r'\(pin\s+\S+\s+\S+\s+\(at\s+(-?[\d.]+)\s+(-?[\d.]+)\s+(\d+)\).*?'
        r'\(number\s+"([^"]+)"',
        block, re.S,
    ):
        pins[m.group(4)] = (float(m.group(1)), float(m.group(2)))
    return pins


def pin_world(px: float, py: float, rot: int, ix: float, iy: float, mirror: bool = False):
    """符号局部坐标 → 世界坐标（y 轴向下）。本页不用 mirror，保留参数与 02 页一致。"""
    if mirror:
        ix = -ix
    if rot == 0:
        return (px + ix, py - iy)
    if rot == 90:
        return (px - iy, py - ix)
    if rot == 180:
        return (px - ix, py + iy)
    if rot == 270:
        return (px + iy, py + ix)
    raise ValueError(rot)


# ---------------------------------------------------------------------------
# 版面（spec §7.4：A3 420×297 分两栏、自下而上，左栏 1–4 节、右栏 5–8 节，最左栏熔丝/端子）
# 每节一个横条：① R30k 下拉 / C32k 耦合 ② U30k（74LVC1G17，本节电芯供电）+ C30k 去耦
# ③ 死区 R31k∥D30k、R32k∥D31k + GP/DRV/GN 三条竖轨 ④ 半桥 Q31k(P) 上 / Q30k(N) 下，
# 漏极相对接 Xk，源极之间挂 C31k 储能 ⑤ 最右 Xk 标签。飞电容摆在第 k 节与第 k+1 节
# 之间的右侧（两端用 Xk/X(k+1) 标签）。相邻两节之间只有两处相连：飞电容 + 1nF 耦合电容。
# ---------------------------------------------------------------------------
SEC = {1: 251.46, 2: 199.39, 3: 147.32, 4: 95.25}    # 左栏第 k 节的横条基线 y（行距 52.07）
# 右栏（第 5–8 节）：整列比左栏同序号行上移 26.67mm（=21×1.27），
# 否则第 5 节最低的 D 值字段（R+19.05+0.95）会压到右下角标题栏（y ≥ 250 @ x ≥ 295）。
# 上移后：第 8 节顶端字段 y=50.80（标题文字止于 ~51.7，横向隔 2 栏无重叠），
# 第 5 节最低 y=243.84 < 250 ✓，右栏最右墨迹 ≈385 < 410 ✓。
SEC_R = {5: 224.79, 6: 172.72, 7: 120.65, 8: 68.58}
DX = 168.91          # 右栏相对左栏的 x 偏移（133×1.27）；右栏最左墨迹 ≈221.3 > 左栏最右 ≈216.2

X_R30 = 55.88        # R30k 下拉（竖放 rot 270，pin1 上=INk、pin2 下=VB(k-1)）：R301=100k、R302–R308=330k
X_C32 = 71.12        # C32k 1nF 交流耦合（横放 rot 0，pin1 左、pin2 右）
X_U30 = 96.52        # U30k SN74LVC1G17（rot 90：1 NC / 2 INA / 3 GND / 4 OUTY / 5 VCC）
X_C30 = 113.03       # C30k 100nF 去耦（竖放 rot 270）
X_R_D_D = 129.54     # R32k ＋ D31k（GP 轨 ↔ DRV 轨）
X_R_D_G = 144.78     # R31k ＋ D30k（DRV 轨 ↔ GN 轨）
X_GP, X_DRV, X_GN = 121.92, 137.16, 152.40   # 三条竖轨
X_QN, X_QP = 165.10, 171.45   # Q30k rot 0（S/D 在 x=167.64）＋ Q31k rot 180（同样落 167.64）
X_C31 = 190.50       # 每节 100µF 本地储能（竖放 rot 270）
X_FLY_L, X_FLY_R = 194.31, 201.93   # 飞电容两并联链；标签锚 191.77 / 204.47
RD_DY = 6.35         # 死区两行的高度：R 行 y=R+6.35、D 行 y=R+13.97（轨底 y=R+16.51）
STUB = 2.54          # 引脚短线的通用长度

# 跨栏那一级飞电容（第 4–5 级，spec §7.4：放右栏最下）。x 落在右栏链位上，
# y 取左栏最下一条的空档（R300 与标题栏之间）：两件都在 y=276.86，字段向上摆。
X4_L, X4_R, Y4 = 224.79, 240.03, 276.86

# 最左栏（spec §7.4）：F300–F308 一列 + J6 线束端子。
# F30k：pin1 → BALk 全局标签（向左引线，标签右对齐）、pin2 → VBk 局部标签（向右）。
# 栈自下而上 F300…F308，节距 22.86；F300 与第 1 节基线同高（251.46）。
# 说明：§7.4 希望 F30k 与 VBk 同高——两栏行高互不相同（52.07 错位 26.67），
# 无法让 9 只同时对齐，故取等节距排布；两端都是标签连接，电气等价（报告已记录）。
X_FUSE, Y_FUSE0, FUSE_PITCH = 27.94, 251.46, 22.86
X_J6, Y_J6 = 27.94, 269.24       # XDWF-C3030WV-2*5P：本体 x±3.81 / y±7.62，引脚 x±6.35


def sec_row(k: int, R: float, dx: float = 0.0):
    """spec §3.1 每节通用连接的 11 件（k，右栏 dx≠0）。"""
    # R30k 是 DRVk 的下拉/泄放电阻。第 2 轮（复核 P1-2 → 规格书 §8.1c 用户决定）：
    # R301 保持 100k（它是整套死区时序的基准），R302–R308 改 330k，让第 1 级**总是**先
    # 泄放完（第 1 级翻相 ≤133µs，其余 ≥169µs）。时钟卡高或 MCU 掉电时，八级同时异步
    # 衰减会让相邻级混相，浪涌可达 20–40A（超 AO3415A 的 IDM 15.6A）。330k 的漏电流
    # 偏移 ±0.33V < VT−,min 0.89V，不会误翻。
    r30 = (("0402WGF1003TCE", "100k 1%", "C25741") if k == 1
           else ("0402WGF3303TCE", "330k 1%", "C25778"))
    # 死区二极管（复核 P1-1 → 规格书 §8.1c）：1N5819WS → BAT54WS。1N5819WS 的结电容
    # ~110pF@4V，经 R31k/R32k 330Ω 耦合会把栅极瞬时顶过 Vth，慢开快关的死区被抹掉；
    # BAT54WS 的 CT ≤10pF、VF 0.24V@0.1mA。**脚位几何完全相同**（SOD-323，1=K/2=A，
    # 本体折线一致），所以接线一根不用动，只换符号/值/LCSC。
    return [
        (f"R30{k}", *r30, X_R30 + dx, R, 270, False),
        (f"C32{k}", "0402B102K500NT", "1nF 50V", "C1523", X_C32 + dx, R, 0, False),
        (f"U30{k}", "SN74LVC1G17DBVR", "SN74LVC1G17DBVR", "C7394021", X_U30 + dx, R, 90, False),
        (f"C30{k}", "CL05B104KO5NNNC", "100nF 16V", "C1525", X_C30 + dx, R, 270, False),
        (f"R32{k}", "0402WGF3300TCE", "330Ω 1%", "C25104", X_R_D_D + dx, R + RD_DY, 0, False),
        (f"D31{k}", "BAT54WSL9", "BAT54WS", "C22629", X_R_D_D + dx, R + 2 * RD_DY + 1.27, 0, False),
        (f"R31{k}", "0402WGF3300TCE", "330Ω 1%", "C25104", X_R_D_G + dx, R + RD_DY, 0, False),
        (f"D30{k}", "BAT54WSL9", "BAT54WS", "C22629", X_R_D_G + dx, R + 2 * RD_DY + 1.27, 0, False),
        (f"Q30{k}", "AO3416_C479060", "AO3416", "C479060", X_QN + dx, R + 6.35, 0, False),
        (f"Q31{k}", "AO3415A_C5350990", "AO3415A", "C5350990", X_QP + dx, R - 6.35, 180, False),
        (f"C31{k}", "CL31A107MQHNNNE", "100µF 6.3V", "C15008", X_C31 + dx, R, 270, False),
    ]
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

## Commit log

2026-09-26 8S LFP 200A BMS 方案：MP2797 AFE + MP2645A 主动均衡
    - 系统设计说明、BOM
    - 设计计算器及单元测试
    - 与硬件无关的保护状态机与 LFP 均衡策略（C11）及主机端测试
    - Obsidian 项目知识库
    Claude-Session: https://claude.ai/code/session_01EyFjq1nqLUmfVYESj2uYXd
    [02-BOM.csv]
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2026-09-26 v0.2 详细设计：功率/AFE/均衡/电源/MCU 模块设计与计算，KiCad 10 工程骨架
    - docs/03-详细设计.md：接口契约、逐件耗散、预充、线束保护、电容完备性、封装下探、PCB 规划
    - tools/bms_calc.py：预充、铜排、IPC-2221 线宽、RC、NTC 计算及测试
    - tools/gen_kicad_skeleton.py + hardware/：层次原理图、四层叠层、网络类
    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
    [01_power_path.kicad_sch, 02_afe.kicad_sch, 03_balancer.kicad_sch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]
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2026-09-26 v0.3：主动均衡改为 MP2643 ×7（MPS 客供），光耦跨电位控制，逐对均衡策略，BOM 与成本估算
    - docs/03：均衡章节按 MP2643 手册 Rev1.1 重写（外围逐件点名、电流/限压计算、光耦接口、线束与发热）
    - firmware：7 对 EN/MODE 输出，边界电荷盈亏定方向，相邻不同时开，收敛仿真测试
    - tools/bms_calc.py：MP2643 手册公式；tools/jlc_api.py：嘉立创料号接口；tools/cost.py：成本估算
    - docs/02-BOM.csv v0.3（81 行，带立创编号与来源），docs/05-成本估算.md
    - KiCad 骨架更新（03 子图接口、网络类）
    Claude-Session: https://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
    [01_power_path.kicad_sch, 02-BOM.csv, 02_afe.kicad_sch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]
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2026-09-26 v0.3 降本落地：Tokmas MOSFET×12、CH32V203、风华 4.7µF/100V、基础库阻值；MP2643 用 MPS 原厂 KiCad 库
    - BOM：12 颗 Tokmas IPT012N08N5（C19626224）、CH32V203C8T6（C3001172）、C381466，MP2643 周边阻值改 0603 基础库等
    - hardware/lib/mps：用户提供的 MP2643 符号/封装（已核对手册 p22 与引脚定义），注册到工程库表
    - 计算器默认改为每方向 6 颗、Qg 240nC；测试按 Tj,max 150°C 留 30°C 裕量
    - 成本：10 块 ¥587→¥393/块，100 块 ¥460→¥294/块（元器件）
    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
    [02-BOM.csv, 05_mcu_comm.kicad_sch, mp2645a-bms.kicad_pcb]
2026-09-26 电源改为 LMR16006X 直降 3.3V + SN65HVD230（取消 5V 轨与 LDO）；会话交接文档与技能转移包
    - BOM/详细设计/骨架：MP9486A+MP2013A+TJA1051 → LMR16006XDDCR(C87080)+SS210(C14996)+SN65HVD230DR(C12084)
    - 成本（元器件）：10 块 ¥393→¥359/块，100 块 ¥294→¥267/块
    - docs/00-会话交接.md：新会话的环境恢复、技能恢复、DeepSeek 画图方配置与待办
    - transfer/pcb-workflow-skill.tar.gz：云主机上改写的 pcb-workflow 技能（仅用于转移）
    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
    [02-BOM.csv, 04_power_supply.kicad_sch, 05_mcu_comm.kicad_sch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]
2026-09-26 主动均衡改为分立开关电容（方案 B）：均衡部分约 ¥186→¥35/块
    - 8 个互补半桥 AO3400A/AO3401A（基础库）+ 74LVC1G17 本节供电驱动，7 级飞电容 3×100µF，MCU BAL_CLK 50kHz 逐级电容耦合
    - 固件：单一时钟使能；顶部/静置才开；压差>300mV 或任一节<3.0V 禁止；测试 37/37
    - 计算器：sc_equalizer 模型（100mV≈0.21A，300mV≈0.62A）；测试 21/21
    - BOM/成本：整板元器件 10 块 ¥359→¥202/块，100 块 ¥267→¥156/块
    - 均衡端子改国产 2×5 Micro-Fit 兼容 C3030WV-2x5P（实测 3.0mm），节点保险丝 3A 1206
    Claude-Session: https://claude.a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
    [01_power_path.kicad_sch, 02-BOM.csv, 02_afe.kicad_sch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]
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2026-09-26 降本推荐项全采用：RS1/QP/Q17-18/Y1/D4-5/J5/J6/J7/C_LDO 换料，开关电容均衡电流按 AO3415A 与保险丝冷阻重算
    - 成本（元器件）：10 块 ¥202→¥187/块，100 块 ¥156→¥146/块
    - J5 新料封装实测 2.50mm（修复原 C158025 封装错误）；J6 针号之字形已在 BOM/交接文档标注
    - 测试：设计计算 21/21，固件 38/38
    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
    [02-BOM.csv]
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2026-09-26 第 2 轮决定落 BOM：MP2797 外围按 Table 18 补全、栅极网络改手册拓扑、D6 删除、C_IN_E 63V、R_RS 0Ω、RB1/2 重号改名
    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
    [02-BOM.csv]
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2026-09-26 04 子图第 1 轮（DeepSeek 画图，ERC 0 错误）；jlc 库引脚类型统一 passive；第 2 轮任务书（lib_id 加 jlc: 前缀、位号统一）
    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
    [04_power_supply.kicad_sch]
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2026-09-26 04 子图第 2 轮：lib_id 带 jlc:、位号 C40–C43/R40–R41、删 D6、C40→C48971005；jlc 库用 kicad-cli 升级为当前格式（消 lib_symbol_mismatch 假告警，取库脚本自动做）
    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
    [04_power_supply.kicad_sch]
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2026-09-26 第 2 轮推荐与可选项全采用：C_IN1/2 2×C13832、C_OUT1 C59461、U8 UMW、U4 Tokmas（沿用 C87080 库）、U7 HGSEMI、F11 JDT
    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
    [02-BOM.csv]
2026-09-26 04 子图第 3 轮：版面返工（标签引出、分组、文字不重叠，8 项自检通过）；取库 R42 10Ω 1206 C17903；第 4 轮任务书（P0 Footprint 字段、P1 输入串 10Ω）
    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
    [04_power_supply.kicad_sch]
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2026-09-26 04 子图第 4 轮：实例补 Footprint/Datasheet 字段（P0-1）、F11 后串 R42 10Ω（P1-1/P1-2）、并入用户 13:57 换料（U4 Tokmas、F11 JDT、C42/C44 2×1µF、C43 0603）；BOM 位号改为 C40–C44/R40–R42；冻结快照 review/04-r4
    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
    [02-BOM.csv, 04_power_supply.kicad_sch]
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2026-09-26 第 1 轮可选项采用：D1–D3 DOWO、C1–C6 C282823、QN AO3416、CF 每级 2 颗 + BAL_CLK 75kHz、F2–F10 大毅、RT APV、J5 C40669；均衡估算 0.19A@100mV
    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
    [02-BOM.csv]
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2026-09-26 04 子图第 5 轮：R42→C153337 56Ω 熔断电阻、加 C45 100nF/100V、U4 Datasheet 指向 Tokmas、补 T 接点；BOM/docs 同步；冻结快照 review/04-r5
    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
    [02-BOM.csv, 04_power_supply.kicad_sch]
2026-09-26 docs/03：修正 04 输入电容行（C13832 + C45）
    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
2026-09-27 05 页用户决定落地（2026-09-27）：RS485 不画、调试口 1×6 2.54 DNP、CAN 待机超标接受、晶振 33pF、绿灯 330Ω、删 PWR_EN、02 页 R_ALT 改 100k 下拉；BOM MCU 段位号 C50–C59/R50–R60 + 新增件；取库 C1562 C25104 C95572 C492405
    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
    [02-BOM.csv]
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2026-09-27 CAN 终端改为跳线可选（用户 2026-09-27）：R55 串 JP1 2P 排针 C492401 + 跳线帽 C100114
    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
    [02-BOM.csv]
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2026-09-27 05 页第 1 轮（DeepSeek，结尾因 API 余额不足 402 中断）：32 器件，ERC 仅跨页 isolated_pin_label，几何自检通过；取库 JP1 C492401
    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
    [05_mcu_comm.kicad_sch]
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2026-09-27 05 页第 2 轮中间产物（DeepSeek 跑满 1 小时超时）：JP1/CAN_TERM 已加；自检尚余 J7 字段压本体
    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
    [05_mcu_comm.kicad_sch]
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2026-09-27 05 页第 2 轮完成（JP1 跳线、三处重叠修复、可读性小项；自检 6 项全过）；冻结快照 review/05-r2
    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
    [05_mcu_comm.kicad_sch]
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2026-09-27 05 页第 3 轮（deepseek-flash）：JP1 挪开、嵌入符号恢复与库一致、JP1 值「2P 排针」；自检 8 项全过；冻结快照 review/05-r3
    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
    [05_mcu_comm.kicad_sch]
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2026-09-27 05 复核 r3（P1-R3 引脚名压本体）→ 库级修复：≤4 脚符号 pin_names hide、两脚无源件 pin_numbers hide（fetch_jlc_parts 自动做）；04/05 页重新生成，网表 0 差异；冻结快照 review/05-r4
    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
    [04_power_supply.kicad_sch, 05_mcu_comm.kicad_sch]
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2026-09-27 按用户 2026-09-27 决定落地（Opus）：BOM AFE 段 2xx 位号与改料、删 RT1/RT2 改线束 NTC、C_PACK_E 47µF；docs/03 共漏拓扑与 §3 订正；02 契约加 BAT+；网络类 HV_SIG/CELL_SENSE/KELVIN；成本重算 10 块 ¥167.98/块；测试 21/21、38/38
    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
    [02-BOM.csv]
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2026-09-27 02 页分段 B（电芯采样 RC、电流采样、J5；自检 9 项 140 脚通过）；分段 C 任务书
    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
    [02_afe.kicad_sch]
2026-09-27 02 页第 1 轮完成（分段 C：NTC、I2C/ALERT/WAKE、全页验收 164 脚、ERC 仅 6 条待 01 页）；冻结快照 review/02-r1；复核任务书
    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
    [02_afe.kicad_sch]
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2026-09-28 03 页用户决定落地（Opus）：BOM 均衡段 3xx 与新增死区/储能/耦合件、docs/03 §4 重写、网络类 BAL_3A 改用图纸名路径、sc_equalizer 加线束电阻（0.16A@100mV）；成本重算 10 块 ≈ ¥177.0/块；测试 22/22、38/38
    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
    [02-BOM.csv]
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2026-09-28 03 页第 1 轮完成（DeepSeek 分段 A/B/C；113 器件、60 网络逐一核对、18 项自检、本页 ERC 0）；冻结快照 review/03-r1；复核任务书
    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
    [03_balancer.kicad_sch]
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
